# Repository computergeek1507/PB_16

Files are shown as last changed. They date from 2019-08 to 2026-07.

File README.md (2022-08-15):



# Copyright and Disclaimer
Copyright: Scott Hanson

This documentation describes Open Hardware and is licensed under the CERN Open Hardware License Version 2 - Strongly Reciprocal. (CERN-OHL-S)

You may redistribute and modify this documentation under the terms of the CERN OHL-S-v2 (https://ohwr.org/cern_ohl_s_v2.txt). This documentation is distributed WITHOUT ANY EXPRESS OR IMPLIED WARRANTY, INCLUDING OF MERCHANTABILITY, SATISFACTORY QUALITY AND FITNESS FOR A PARTICULAR PURPOSE. Please see the CERN OHL v2-S for applicable conditions

**Under CERN OHL-S-v2, derivative work must be publicly released as defined in subsection 3.3**

# BBB/PB 'Family' of Controllers

The PB16/BBB16 Pixel Controllers are designed as open source DIY hobbyist controllers. 
They all run FPP to drives the ports and serial ports. 
They are designed to be modular and support many use cases. It runs a full Linux operating system with ethernet, WIFI and audio supported over the USB port. It can run in standalone, or be used with other controllers/devices. All the design files are open source and available on github. Open source applications were used to create the controllers. [KiCad](http://kicad.org/) was used for the PCB design, and [LibreOffice](https://www.libreoffice.org/) for the documentation.

# [PB 16v1](PB_16v1/README.md)
The "Original" Pocketbeagle Version with 16 pixel ports, 2 serial ports and an expansion header for additional 16 pixel outputs.
The design was made with all through hole components for easy assembly by most users.

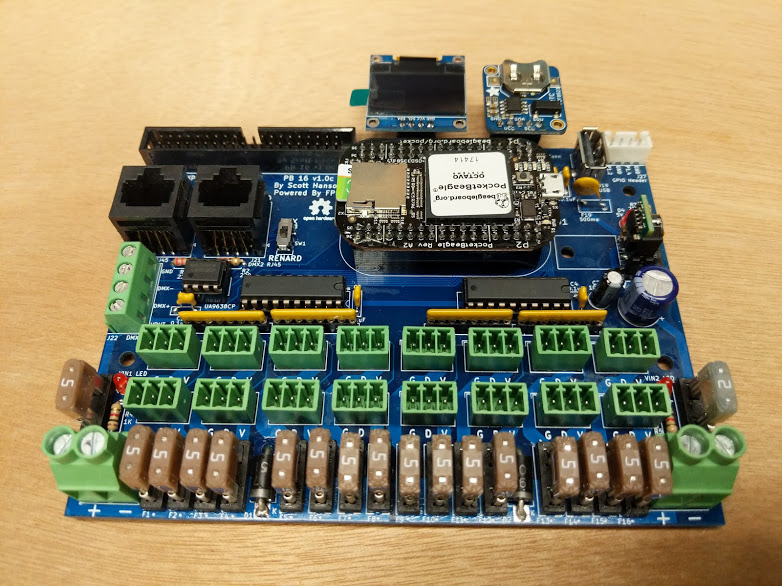
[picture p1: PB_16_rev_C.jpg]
Image of Rev C Controller


# [PB 16v2](PB_16v2_SMD/README.md)
The PB 16v2 is a Surface Mount(SMD) Pocketbeagle Version with 16 pixel ports, 1 remote differential port, 2 serial ports, and an expansion header for additional 16 pixel outputs. The v2 has an improved reverse protect circuit and USB power supply circuit.
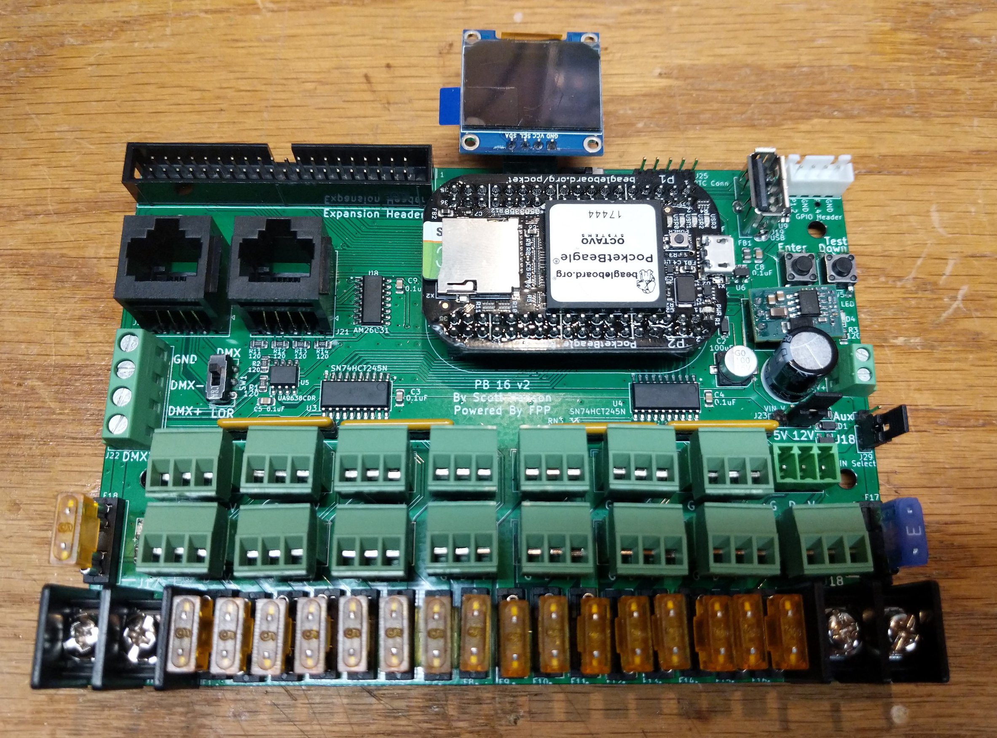
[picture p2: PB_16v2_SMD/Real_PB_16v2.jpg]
Image of PB 16v2


# [BBB 16v2](BBB_16/README.md)
The BBB 16v2 is a BeagleBone Version with 16 pixel ports, 1 remote differential port, 2 serial ports, and an expansion header for additional 16 pixel outputs. Uses Falcon v4 (24 pin) Expansion Pinout.
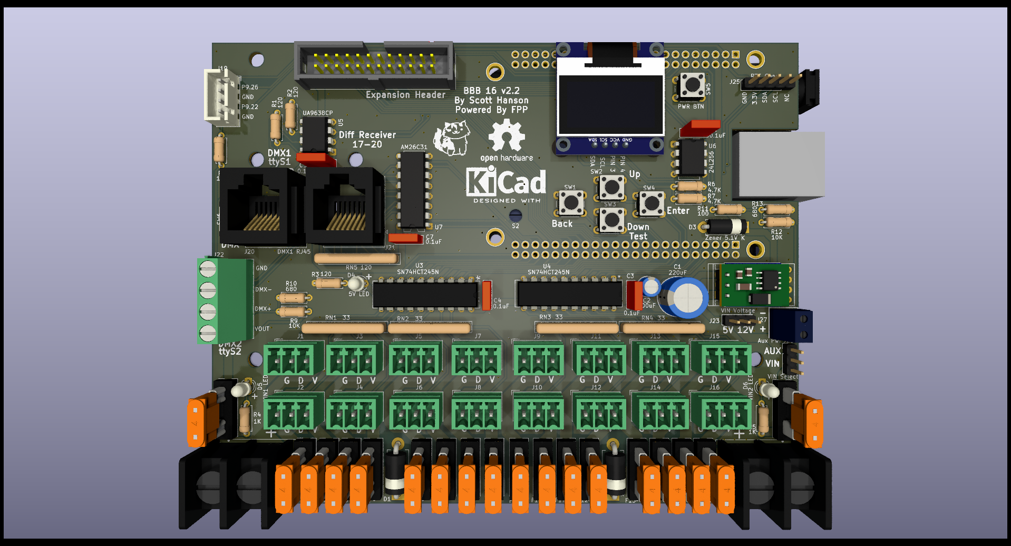
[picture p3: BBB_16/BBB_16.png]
Image of BBB 16v2


# [BBB 16v2 SMD](BBB_16_SMD/README.md) 
The BBB 16v2 SMD is a Surface Mount(SMD) BeagleBone Version with 16 pixel ports, 1 remote differential port, 2 serial ports, and an expansion header for additional 16 pixel outputs. Uses Falcon v4 (24 pin) Expansion Pinout.
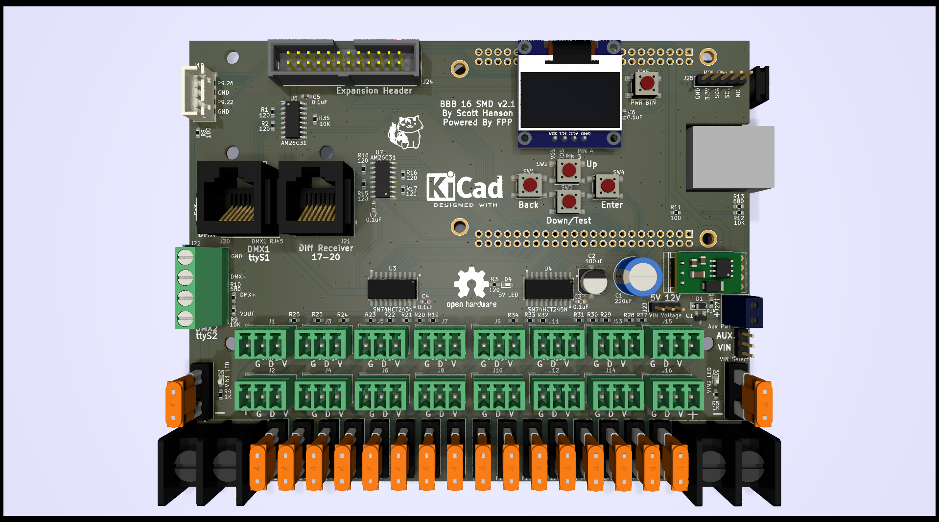
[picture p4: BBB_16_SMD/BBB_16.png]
Image of BBB 16v2 SMD


### Common Features of the PB 16v1, PB 16v2, & BBB 16v2
* Powered by FPP Falcon Player
* Standalone/Master/Remote/Bridge Support
* 16 3-Wire Pixel Ports
* 700 pixel per output at 40 FPS or 1300 at 20 FPS
* 2 DMX Serial Outputs
* Fused Powered DMX Output
* USB port for Ethernet,WIFI, or Audio
* OLED Display header
* Adafruit Real Time Clock Header Connector
* 2 pin GPIO Header for Push Button or Relay Support
* 5v - 24v Vin Support
* Expansion Header for additional 16 pixel outputs, Supports Falcon v3 (40 pin) Expansion Boards.

### Features of the PB 16v1
* Through Hole Assemply
* 1 RJ-45 Connector with DMX/Renard Wiring Support.
* 1 RJ-45 Connector with DMX/LOR Wiring Support.
* Only Supports DMX Protocol over Serial Ports.

### Features of the PB 16v2 & BBB 16v2
* 1 RJ-45 Connector for a remote differential port.
* 1 RJ-45 Connector with DMX/LOR Wiring Support.
* Supports DMX/Renard/Lor Protocol over Serial Ports.

## [Ordering Instructions](https://github.com/computergeek1507/PB_16/blob/master/JLC_PCB.md)
## [Flashing EEPROM Instructions](https://github.com/computergeek1507/PB_16/blob/master/Flashing_EEPROM.md)

## Variants
I created different variants of the PB 16, to fit my specific needs.
* [**PB 16v1**](PB_16v1/README.md) - Original Pocketbeagle Version with 16 pixel ports, 2 serial ports and an expansion header(40 pins) for additional 16 pixel outputs.
* [**PB 16v2**](PB_16v2_SMD/README.md) - **Surface Mount(SMD)** Pocketbeagle Version with 16 pixel ports, 1 remote differential port, 2 serial ports, and an expansion header(40 pins) for additional 16 pixel outputs.
* [**BBB 16v2**](BBB_16/README.md) - Beaglebone Version with 16 pixel ports, 1 remote differential port, 2 serial ports and an expansion header for additional 16 pixel outputs. Uses Falcon v4 Expansion Pinout(24 pins).
* [**BBB 16v2 SMD**](BBB_16_SMD/README.md) - **Surface Mount(SMD)** Beaglebone Version with 16 pixel ports, 1 remote differential port, 2 serial ports and an expansion header for additional 16 pixel outputs. Uses Falcon v4 Expansion Pinout(24 pins).
* [**BBB 16 Flex**](BBB_16_Flex/README.md) - BBB 16 PCB to use with the HolidayCoro Flex System. This is a **Surface Mount(SMD)** Design.
* [**BBB 16 Expansion**](BBB_16_Expansion/README.md) - BBB 16v2 PCB with Three Expansion Board Ports for 48 outputs. Uses Falcon v4 Expansion Pinout. This is a **Surface Mount(SMD)** Design.
* [**PB 16 Expansion**](PB_16_Expansion/README.md) - Small Form Factor PB 16 with Two Expansion Board Ports(40 pins) for 32 outputs.
* [**PB 16 Mini**](PB_16_Mini/README.md) - Small Form Factor PB 16 with one Expansion Board Port(40 pins) for 16 ouputs and two Serial Outputs.
* [**PB 16 Flex**](PB_16_Flex/README.md) - PB 16 PCB to use with the HolidayCoro Flex System.
<!--- * [**PB 16 E682**](PB_16_E682/README.md) - Adapter PCB to use a Pocketbeagle with a Sandevice E682. (This is a proof of concept, not designed for extended use)-->
* [**PB 16 E682 Serial**](PB_16_E682_Serial/README.md) - Serial Output PCB to for PB 16 E682 or PB 16 Expansion.

## Addon Boards

The PB16 Controller contains an expansion header. The expansion header can drive 16 additional pixel ports. I have also created addition addon boards to work with the expansion port. These Expansions will work with Kulp Controllers, but **not** Falcon Controllers.

* [**16 Expansion**](16_Expansion/README.md) - 16 Port Local Expansion. Supports PB 16 (40 pins) Connectors.
* [**16 Expansion 24pin**](16_Expansion_24pin/README.md) - 16 Port Local Expansion. Supports BBB 16v2 (24 pins) Connectors.
* [**16 Expansion SMD**](16_Expansion_SMD/README.md) - 16 Port Local Expansion. Supports PB 16 (40 pins) Connectors. This is a **Surface Mount(SMD)** Design.
* [**16 Expansion SMD 24pin**](16_Expansion_SMD_24pin/README.md) - 16 Port Local Expansion. Supports BBB 16v2 (24 pins) Connectors. This is a **Surface Mount(SMD)** Design.
* [**Diff Expansion**](Diff_Expansion/README.md) - 4 Port Remote Differential Expansion. Supports PB 16 (40 pins) & BBB 16 (24 pins) Connectors.
* [**Multi Expansion**](Multi_Expansion/README.md) - 8 Port Local & 2 Port Remote Differential Expansion. **Only Supports PB 16 (40 pins) Connectors.**
* [**Quad Diff Out**](Quad_Diff_Out/README.md) - 1 Port Remote Differential Expansion.
* [**Four Out**](Four_Out/README.md) - 4 Port Local Expansion. Supports PB 16 (40 pins) & BBB 16 (24 pins) Connectors.
* [**Receiver Out**](Receiver_Out/README.md) - 4 Port Remote Receiver Board for use with Remote Differential Expansions.
* [**Receiver Out SMD**](Receiver_Out_SMD/README.md) - 4 Port Remote Receiver Board for use with Remote Differential Expansions. This is a **Surface Mount(SMD)** Design.

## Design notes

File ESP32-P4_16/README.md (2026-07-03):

# Copyright and Disclaimer
Copyright: Scott Hanson

This documentation describes Open Hardware and is licensed under the CERN Open Hardware License Version 2 - Strongly Reciprocal. (CERN-OHL-S)

You may redistribute and modify this documentation under the terms of the CERN OHL-S-v2 (https://ohwr.org/cern_ohl_s_v2.txt). This documentation is distributed WITHOUT ANY EXPRESS OR IMPLIED WARRANTY, INCLUDING OF MERCHANTABILITY, SATISFACTORY QUALITY AND FITNESS FOR A PARTICULAR PURPOSE. Please see the CERN OHL v2-S for applicable conditions

**Under CERN OHL-S-v2, derivative work must be publicly released as defined in subsection 3.3**

# ESP32-P4 16

**WIP, Do not use**

The ESP32-P4 16 is a ESP32-P4 based 16 port controller. All the design files are open source and available on github.

## [Interactive BOM](https://computergeek1507.github.io/PB_16/ESP32-P4_16/bom/ibom)

## [Part BOM](https://github.com/computergeek1507/PB_16/raw/master/ESP32-P4_16/ESP32-P4_16_BOM.ods)

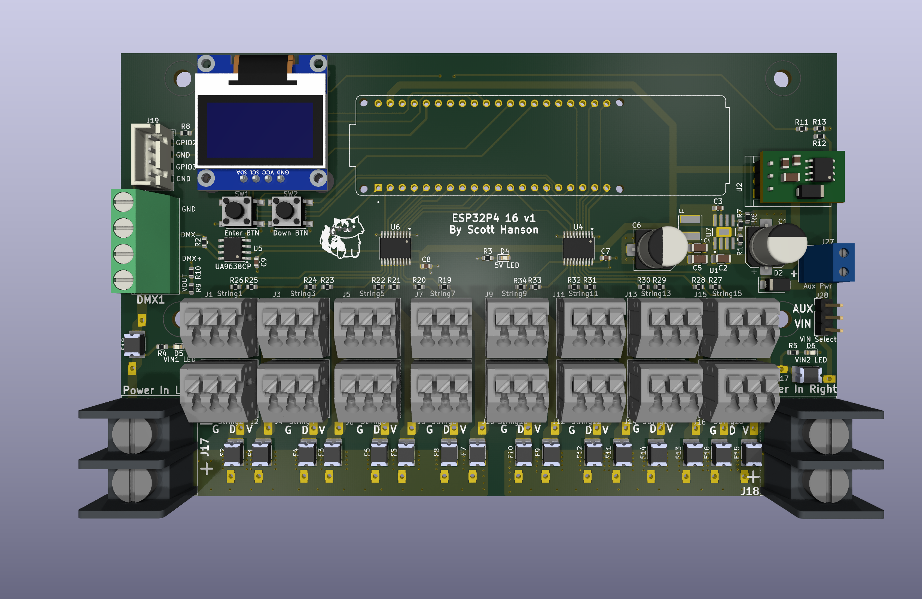
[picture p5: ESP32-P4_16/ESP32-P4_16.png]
Image of ESP32-P4 16 Out


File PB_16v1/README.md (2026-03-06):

# Copyright and Disclaimer
Copyright: Scott Hanson

This documentation describes Open Hardware and is licensed under the CERN Open Hardware License Version 2 - Strongly Reciprocal. (CERN-OHL-S)

You may redistribute and modify this documentation under the terms of the CERN OHL-S-v2 (https://ohwr.org/cern_ohl_s_v2.txt). This documentation is distributed WITHOUT ANY EXPRESS OR IMPLIED WARRANTY, INCLUDING OF MERCHANTABILITY, SATISFACTORY QUALITY AND FITNESS FOR A PARTICULAR PURPOSE. Please see the CERN OHL v2-S for applicable conditions

**Under CERN OHL-S-v2, derivative work must be publicly released as defined in subsection 3.3**

# PB 16

Image of Rev C Controller

The PB16 Pixel Controller is designed as an open source DIY hobbyist controller. A Pocketbeagle running FPP drives the 16 pixel ports and 2 serial ports. The design was made with all through hole components for easy assembly by most users. It is designed to be modular and support many use cases. It runs a full Linux operating system with ethernet, WIFI and audio supported over the USB port. It can run in standalone, or be used with other controllers/devices. It is 140mm (5’) wide by 103mm(4’) tall. The controllers small form factor and simplistic design are intended to limit overall cost. All the design files are open source and available on github. Open source applications were used to create this controller. [KiCad](http://kicad.org/) was used for the PCB design, and [LibreOffice](https://www.libreoffice.org/) for the documentation.

To order your own PCB upload the gerber.zip file to your favorite PCB manufacture of choice, I personally use [jlcpcb.com](https://jlcpcb.com/).

Assembly Instructions are included in the manual below.

### Features
* Powered by FPP Falcon Player
* Standalone/Master/Remote/Bridge Support
* 16 3-Wire Pixel Ports
* 700 pixel per output at 40 FPS or 1300 at 20 FPS
* 2 DMX Serial Outputs
* 2 RJ-45 Connectors with DMX/LOR/Renard Wiring Support
* Fused Powered DMX Output
* USB port for Ethernet,WIFI, or Audio
* OLED Display header
* Adafruit Real Time Clock Header Connector
* 2 pin GPIO Header for Push Button or Relay Support
* 5v - 24v Vin Support
* Expansion Header for additional 16 pixel outputs, Supports Falcon(v3) Expansion Boards

## [Manual](https://github.com/computergeek1507/PB_16/raw/master/PB_16v1/FPP%20PB16%20Pixel%20Controller%20Manual%20and%20Assembly%20Guide.pdf)

## [Gerbers](https://github.com/computergeek1507/PB_16/raw/master/PB_16v1/gerbers/gerbers.zip)

## [Part BOM](https://github.com/computergeek1507/PB_16/raw/master/PB_16v1/PB16_Bom.ods)

## [Interactive BOM](https://computergeek1507.github.io/PB_16/PB_16v1/bom/ibom)

## [Ordering Instructions](https://github.com/computergeek1507/PB_16/blob/master/JLC_PCB.md)

---
## Changelog

v1 rev I 
- 
* 2026-03-06
* Switched Expansion Header to 24pin Falcon V4 pinout.
* Removed OLED Slide Switch.

v1 rev H 
- 
* 2022-05-29
* Updated 5V regulator to "Universal" footprint to support different regulators.
* Added Chewi Logo.

v1 rev G 
-
* 2020-05-09
* Moved to barrier block screws connectors for Power Inputs.
* Fix AUX power pin holes too small.

v1 rev F
-
* 2019-10-07
* Added Serial Selector for LOR/DMX, EEPROM, Push Buttons.

v1 rev E
-
* 2019-09-19
* Increased AUX power input terminal footprint to 3.81mm. (Pin Holes were too small)

v1 rev D
-
* 2019-08-24
* Added OLED wiring selector switch and AUX power input.

v1 rev C
-
* 2019-08-12
* Added LEDs and GPIO Header. (First functional PCBs)

v1 rev B(v1.1)
-
* 2019-07-31
* Added Expansion, DMX2 RJ45, and OLED Headers. (non-functioning due to wiring issues)

v1 rev A(v1.0)
-
* 2019-06-19(SEH B-Day)
* Initial Version. (First non-functioning Prototype PCBs)

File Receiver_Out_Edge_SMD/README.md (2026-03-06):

# Copyright and Disclaimer
Copyright: Scott Hanson

This documentation describes Open Hardware and is licensed under the CERN Open Hardware License Version 2 - Strongly Reciprocal. (CERN-OHL-S)

You may redistribute and modify this documentation under the terms of the CERN OHL-S-v2 (https://ohwr.org/cern_ohl_s_v2.txt). This documentation is distributed WITHOUT ANY EXPRESS OR IMPLIED WARRANTY, INCLUDING OF MERCHANTABILITY, SATISFACTORY QUALITY AND FITNESS FOR A PARTICULAR PURPOSE. Please see the CERN OHL v2-S for applicable conditions

**Under CERN OHL-S-v2, derivative work must be publicly released as defined in subsection 3.3**

# Receiver Out Edge SMD

The "Receiver Out Edge SMD" is a 4 port Differental Reciver output board for the PB16. This design is surface mount based. All the design files are open source and available on github.

### Version 3
Version 3 (2025-2-23) adds an Attiny1616 Micro controller and Test Button to enable local testing. This is be programmed with the included Ardunio INO file or hex file. Requires a UPDI programmer. This can be bypassed by populateding R12 with 10K.

### Ordering
To order PCBs upload the "GERBER-Receiver_Out.zip" file in the "jlcpcb\production_files" folder. Enable the SMD service, 'BOM-Receiver_Out.csv' is the SMD BOM and 'POS-Receiver_Out.csv' is the SMD CPL position file.

## [Part BOM](https://github.com/computergeek1507/PB_16/raw/master/Receiver_Out_Edge_SMD/Receiver_Out.csv)

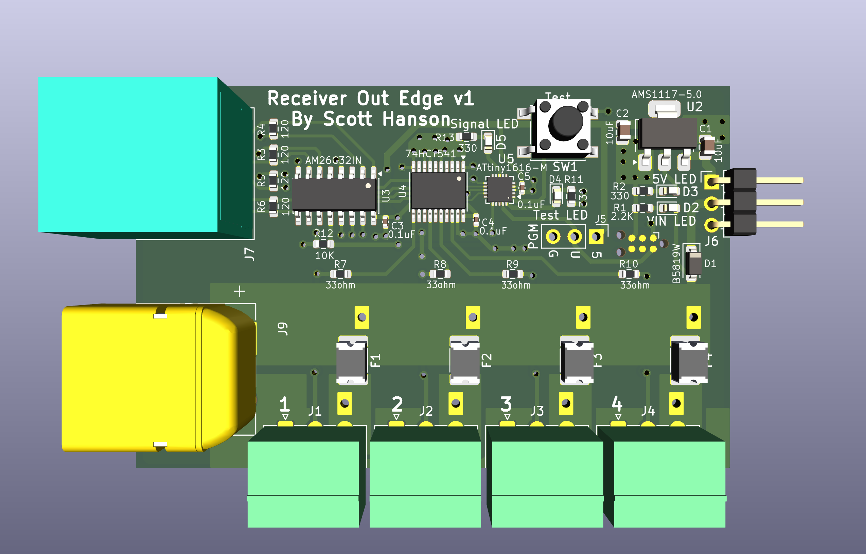
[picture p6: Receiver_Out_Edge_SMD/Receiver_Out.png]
Image of Receiver Out


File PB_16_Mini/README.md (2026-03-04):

# Copyright and Disclaimer
Copyright: Scott Hanson

This documentation describes Open Hardware and is licensed under the CERN Open Hardware License Version 2 - Strongly Reciprocal. (CERN-OHL-S)

You may redistribute and modify this documentation under the terms of the CERN OHL-S-v2 (https://ohwr.org/cern_ohl_s_v2.txt). This documentation is distributed WITHOUT ANY EXPRESS OR IMPLIED WARRANTY, INCLUDING OF MERCHANTABILITY, SATISFACTORY QUALITY AND FITNESS FOR A PARTICULAR PURPOSE. Please see the CERN OHL v2-S for applicable conditions

**Under CERN OHL-S-v2, derivative work must be publicly released as defined in subsection 3.3**

# PB 16 Mini

The PB16 Mini is a compact version of the PB16 with only an Expansions Header. It can be used with any PB16 Family Expansion or Falcon Expansion Boards. All the design files are open source and available on github.

## [Part BOM](https://github.com/computergeek1507/PB_16/raw/master/PB_16_Mini/PB_16_Mini.ods)

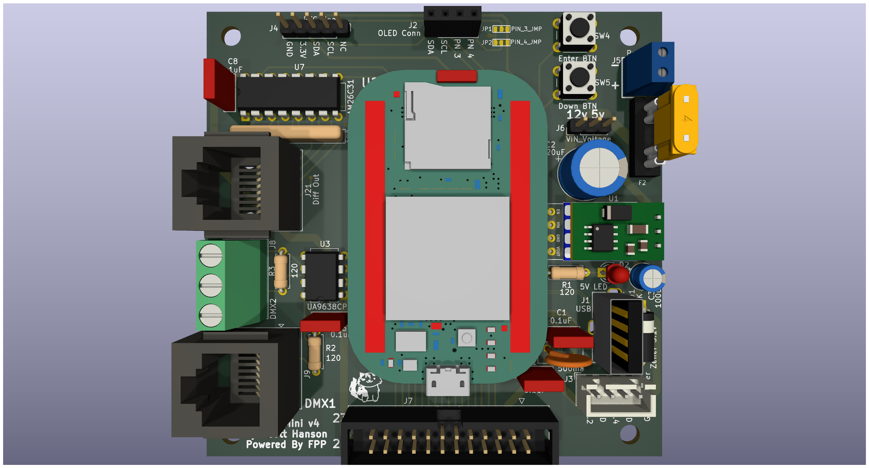
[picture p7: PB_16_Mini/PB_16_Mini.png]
Image of PB16 Mini Out


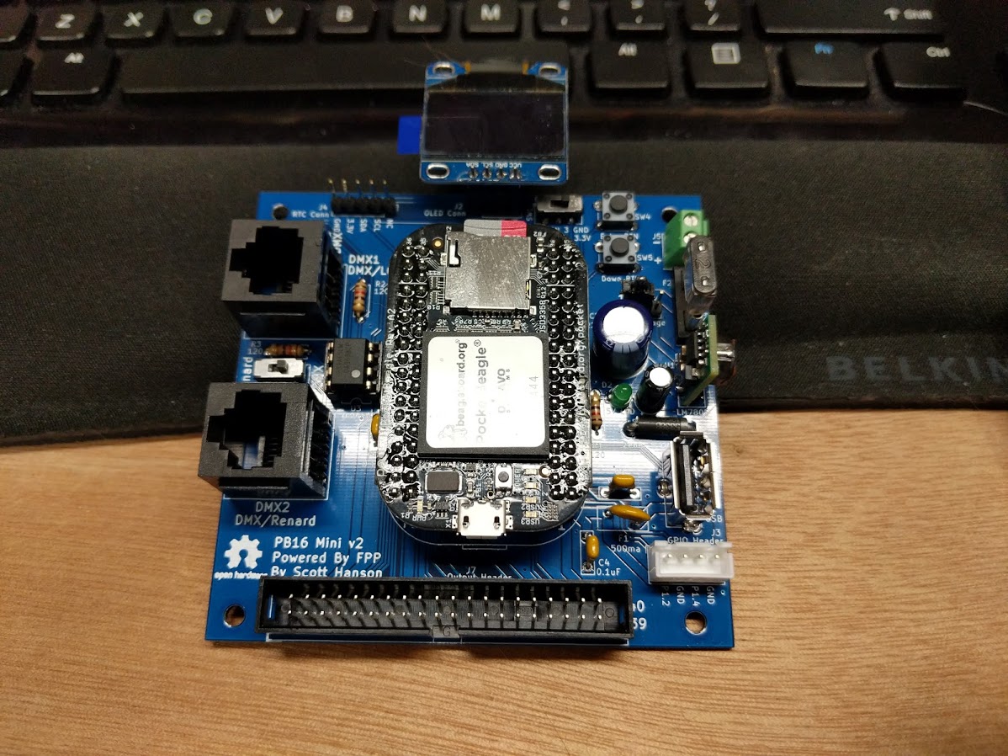
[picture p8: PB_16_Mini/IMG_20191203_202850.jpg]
Real Image of PB16 Mini Out


----
## Changelog

v4
----
* 2026-03-04
* Add Different Output
* Switched Expansion Header to 24pin Falcon V4 pinout.
* Switched to PB16v2 pinout, use PB16v2 EEPROM

v3
----
* 2022-08-13
* Updated 5V regulator to "Universal" footprint to support different regulators.
* Added Logo

v2
----
* 2019-12-03
* Add Serial Outputs.

v1
----
* 2019-??-??
* First Internal Version with only Expansion Port.

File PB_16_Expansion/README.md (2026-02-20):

# Copyright and Disclaimer
Copyright: Scott Hanson

This documentation describes Open Hardware and is licensed under the CERN Open Hardware License Version 2 - Strongly Reciprocal. (CERN-OHL-S)

You may redistribute and modify this documentation under the terms of the CERN OHL-S-v2 (https://ohwr.org/cern_ohl_s_v2.txt). This documentation is distributed WITHOUT ANY EXPRESS OR IMPLIED WARRANTY, INCLUDING OF MERCHANTABILITY, SATISFACTORY QUALITY AND FITNESS FOR A PARTICULAR PURPOSE. Please see the CERN OHL v2-S for applicable conditions

**Under CERN OHL-S-v2, derivative work must be publicly released as defined in subsection 3.3**

# PB 16 Expansion

The PB16 Expansion is a compact version of the PB16 with only two Expansion Headers. It can be used with any PB16 Family Expansion or Falcon Expansion Boards. There is also an optional [serial breakout board](../PB_16_E682_Serial/README.md) for DMX capability. All the design files are open source and available on github.

## [Part BOM](https://github.com/computergeek1507/PB_16/raw/master/PB_16_Expansion/PB_16.csv)

## [Interactive BOM](https://computergeek1507.github.io/PB_16/PB_16_Expansion/bom/ibom)

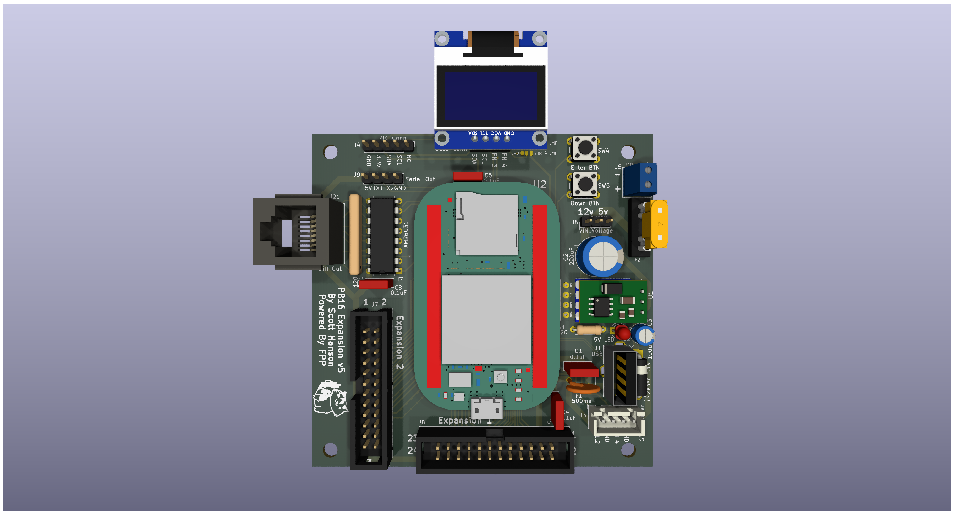
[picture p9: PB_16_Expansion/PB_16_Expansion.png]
Image of PB16 Expansion Out


----
## Changelog

v5
----
* 2026-02-20
* Add Different Output
* Switched Expansion Header to 24pin Falcon V4 pinout.
* Switched to PB16v2 pinout, use PB16v2 EEPROM

v4
----
* 2022-08-13
* Updated 5V regulator to "Universal" footprint to support different regulators.
* Added Logo

v3
----
* 2020-05-06
* Wiring Routing Updates.

v2
----
* 2020-01-02
* Add Serial Output Header.

v1
----
* 2019-12-31
* First Version.

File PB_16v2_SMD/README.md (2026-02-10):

# Copyright and Disclaimer
Copyright: Scott Hanson

This documentation describes Open Hardware and is licensed under the CERN Open Hardware License Version 2 - Strongly Reciprocal. (CERN-OHL-S)

You may redistribute and modify this documentation under the terms of the CERN OHL-S-v2 (https://ohwr.org/cern_ohl_s_v2.txt). This documentation is distributed WITHOUT ANY EXPRESS OR IMPLIED WARRANTY, INCLUDING OF MERCHANTABILITY, SATISFACTORY QUALITY AND FITNESS FOR A PARTICULAR PURPOSE. Please see the CERN OHL v2-S for applicable conditions

**Under CERN OHL-S-v2, derivative work must be publicly released as defined in subsection 3.3**

# PB 16v2

The PB 16v2 is a surface mount(SMD) version of the original PB16. The updated PB 16v2 has 16 local pixel ports, one remote receiver port(4 remote ports), a 16 port expansion, and 2 serial ports. A total of 36 pixel outputs. All the design files are open source and available on github.

### Features
* Powered by FPP Falcon Player
* Standalone/Master/Remote/Bridge Support
* 16 3-Wire Pixel Ports
* 1 RJ-45 Connector for a remote differential port.
* 700 pixel per output at 40 FPS or 1300 at 20 FPS
* 2 DMX Serial Outputs
* 1 RJ-45 Connectors with DMX/LOR Wiring Support
* Fused Powered DMX Output
* USB port for Ethernet,WIFI, or Audio
* OLED Display header
* Adafruit Real Time Clock Header Connector
* 2 pin GPIO Header for Push Button or Relay Support
* 5v - 24v Vin Support
* Expansion Header for additional 16 pixel outputs, Supports Falcon(v3) Expansion Boards

### Purchase
I (Scott) have a limited quantity of fully assembled PCB's available for purchase. PM me if interested.

## [Part BOM](https://github.com/computergeek1507/PB_16/raw/master/PB_16v2_SMD/PB_16_BOM.ods)

## [Interactive BOM](https://computergeek1507.github.io/PB_16/PB_16v2_SMD/bom/ibom)

Image of PB 16v2

----
## Changelog

v2.3
----
* 2026-02-09
* Switched to TSSOP-20 for U4 & U5.
* Switched Pixel Outputs to Dual 3.5mm/3.81mm Pads.
* Switched Expansion Header to 24pin Falcon V4 pinout.
* Removed OLED Slide Switch.
* Removed Top Solder pour.

v2.2
----
* 2022-06-05
* Updated 5V regulator to "Universal" footprint to support different regulators.
* Switched to 603 Resistors and Capacitors
* Added Logo

v2.1
----
* 2022-05-26
* Switched to surface mount 33ohm resistors on pixel outputs.

v2
----
* 2020-08-11 (publicly released 2022-01-22)
* First SMD version.
* Based off PB16v1.
* Used 805 Resistors and Capacitors
* Changed one RJ45 port to new differential output.
* Added Power Controller to USB port.
* Added TVS Diodes to USB port.

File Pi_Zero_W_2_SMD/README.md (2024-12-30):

# Copyright and Disclaimer
Copyright: Scott Hanson

This documentation describes Open Hardware and is licensed under the CERN Open Hardware Licence Version 2 - Strongly Reciprocal. (CERN-OHL-S)

You may redistribute and modify this documentation under the terms of the CERN OHL-S-v2 (https://ohwr.org/cern_ohl_s_v2.txt). This documentation is distributed WITHOUT ANY EXPRESS OR IMPLIED WARRANTY, INCLUDING OF MERCHANTABILITY, SATISFACTORY QUALITY AND FITNESS FOR A PARTICULAR PURPOSE. Please see the CERN OHL v2-S for applicable conditions

**Under CERN OHL-S-v2, derivative work must be publicy released as defined in subsection 3.3**

# Pi Zero W 2

**Never Built or tested**

The Pi Zero W 2 is a surface mount(SMD) controller with 2 local pixel ports. All the design files are open source and available on github.

## [Interactive BOM](https://computergeek1507.github.io/PB_16/Pi_Zero_W_2_SMD/bom/ibom)

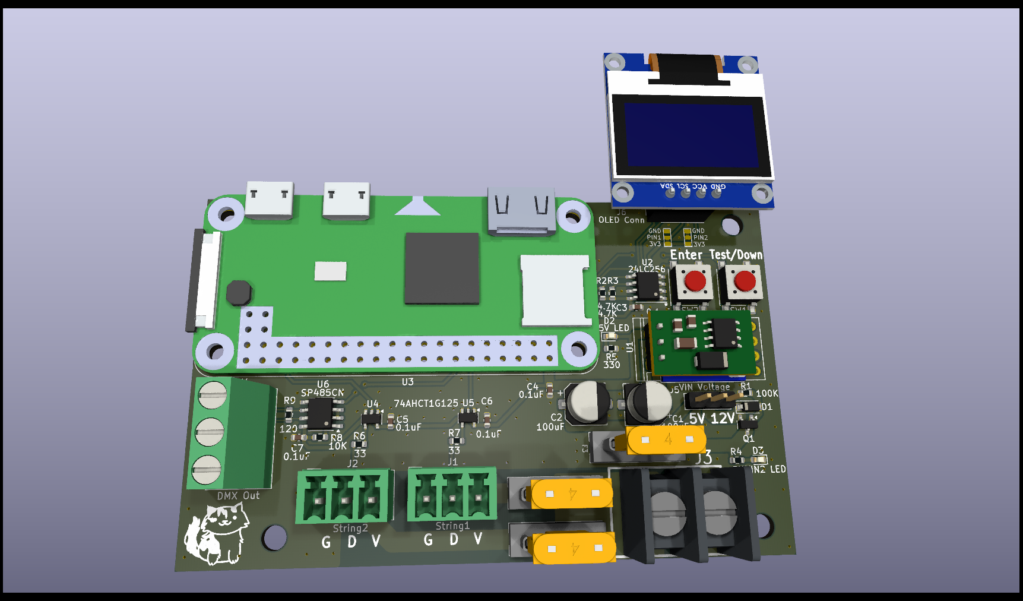
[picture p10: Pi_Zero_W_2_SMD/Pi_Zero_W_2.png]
Image of PB Pi Zero W 16


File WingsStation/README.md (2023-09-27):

# Copyright and Disclaimer
Copyright: Scott Hanson

This documentation describes Open Hardware and is licensed under the CERN Open Hardware License Version 2 - Strongly Reciprocal. (CERN-OHL-S)

You may redistribute and modify this documentation under the terms of the CERN OHL-S-v2 (https://ohwr.org/cern_ohl_s_v2.txt). This documentation is distributed WITHOUT ANY EXPRESS OR IMPLIED WARRANTY, INCLUDING OF MERCHANTABILITY, SATISFACTORY QUALITY AND FITNESS FOR A PARTICULAR PURPOSE. Please see the CERN OHL v2-S for applicable conditions

**Under CERN OHL-S-v2, derivative work must be publicly released as defined in subsection 3.3**

# Button Station SMD

The "Button Station SMD" is a 4 port Selfy Station that reacts to Button Presses. The Firmware is a work in progress. This design is surface mount based and is harder to solder. All the design files are open source and available on github.

**WIP** Work in progress, firmware and PCB may change.

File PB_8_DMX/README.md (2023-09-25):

# Copyright and Disclaimer
Copyright: Scott Hanson

This documentation describes Open Hardware and is licensed under the CERN Open Hardware License Version 2 - Strongly Reciprocal. (CERN-OHL-S)

You may redistribute and modify this documentation under the terms of the CERN OHL-S-v2 (https://ohwr.org/cern_ohl_s_v2.txt). This documentation is distributed WITHOUT ANY EXPRESS OR IMPLIED WARRANTY, INCLUDING OF MERCHANTABILITY, SATISFACTORY QUALITY AND FITNESS FOR A PARTICULAR PURPOSE. Please see the CERN OHL v2-S for applicable conditions

**Under CERN OHL-S-v2, derivative work must be publicly released as defined in subsection 3.3**

# PB 8 DMX

The PB 8 DMX Controller is designed as an open source DIY hobbyist controller. A Pocketbeagle running FPP drives the 8 serial ports. The design was made with all through hole components for easy assembly by most users. It is designed to be modular and support many use cases. It runs a full Linux operating system with ethernet, WIFI and audio supported over the USB port. It can run in standalone, or be used with other controllers/devices. It is 140mm (5’) wide by 103mm(4’) tall. The controllers small form factor and simplistic design are intended to limit overall cost. All the design files are open source and available on github. Open source applications were used to create this controller. [KiCad](http://kicad.org/) was used for the PCB design, and [LibreOffice](https://www.libreoffice.org/) for the documentation.

To order your own PCB upload the gerber.zip file to your favorite PCB manufacture of choice, I personally use [jlcpcb.com](https://jlcpcb.com/).

### Features
* Powered by FPP Falcon Player
* Standalone/Master/Remote/Bridge Support
* 8 DMX Serial Outputs
* USB port for Ethernet,WIFI, or Audio
* OLED Display header
* Adafruit Real Time Clock Header Connector
* 2 pin GPIO Header for Push Button or Relay Support
* 5v - 24v Vin Support

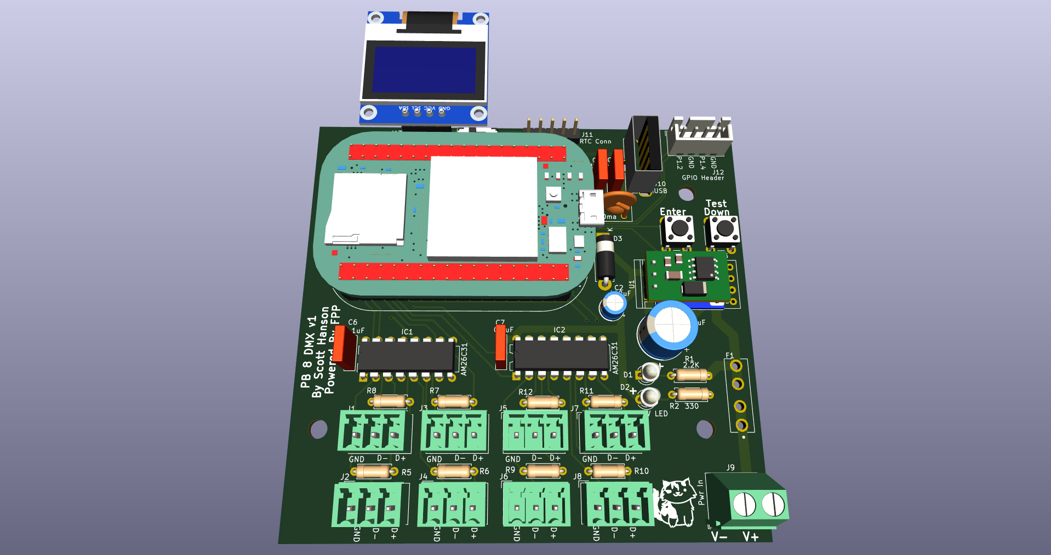
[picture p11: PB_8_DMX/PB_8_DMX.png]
Image of Controller


## [Gerbers](https://github.com/computergeek1507/PB_16/raw/master/jlcpcb/production_files/GERBER-PB_8_DMX.zip)

## [Interactive BOM](https://computergeek1507.github.io/PB_16/PB_8_DMX/bom/ibom)

---
## Changelog

v1
-
* 2023-09-24
* Initial Version.

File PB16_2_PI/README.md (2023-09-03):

# Copyright and Disclaimer
Copyright: Scott Hanson

This documentation describes Open Hardware and is licensed under the CERN OHL v. 1.2.

You may redistribute and modify this documentation under the terms of the CERN OHL v.1.2. (http://ohwr.org/cernohl). This documentation is distributed WITHOUT ANY EXPRESS OR IMPLIED WARRANTY, INCLUDING OF MERCHANTABILITY, SATISFACTORY QUALITY AND FITNESS FOR A PARTICULAR PURPOSE. Please see the CERN OHL v.1.2 for applicable conditions

# PB16-2-PI

This is an adapter to use a Raspberry Pi W with the PB16 Cape instead of a PocketBeagle. This only supports the 16 local ports and the serial ports. The Expansion header does not work. Open source applications were used to create this PCB. [KiCad](http://kicad.org/) was used for the PCB design, and [LibreOffice](https://www.libreoffice.org/) for the documentation.

To order your own PCB upload the gerber.zip file to your favorite PCB manufacture of choice, I personally use [jlcpcb.com](https://jlcpcb.com/).

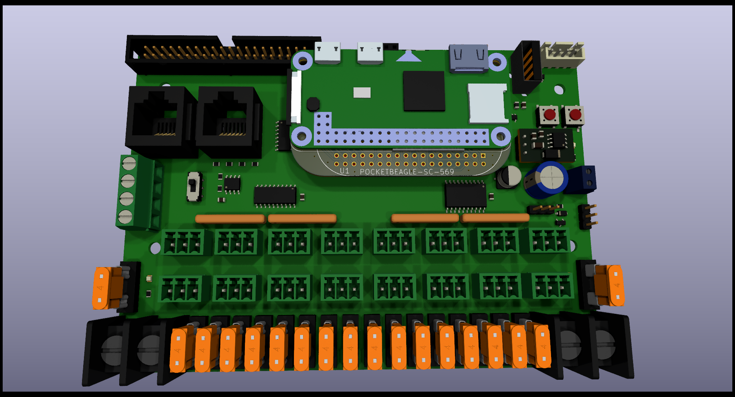
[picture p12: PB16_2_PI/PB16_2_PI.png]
Image of PI Adapter


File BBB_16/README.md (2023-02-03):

# Copyright and Disclaimer
Copyright: Scott Hanson

This documentation describes Open Hardware and is licensed under the CERN Open Hardware License Version 2 - Strongly Reciprocal. (CERN-OHL-S)

You may redistribute and modify this documentation under the terms of the CERN OHL-S-v2 (https://ohwr.org/cern_ohl_s_v2.txt). This documentation is distributed WITHOUT ANY EXPRESS OR IMPLIED WARRANTY, INCLUDING OF MERCHANTABILITY, SATISFACTORY QUALITY AND FITNESS FOR A PARTICULAR PURPOSE. Please see the CERN OHL v2-S for applicable conditions

**Under CERN OHL-S-v2, derivative work must be publicly released as defined in subsection 3.3**

# BBB 16

The BBB16 is a Beaglebone version of the PB16. All the design files are open source and available on github.

To order PCBs upload the ["GERBER-BBB_16.zip"](https://github.com/computergeek1507/PB_16/raw/master/BBB_16/jlcpcb/production_files/GERBER-BBB_16.zip) file in the "jlcpcb\production_files" folder to jlcpcb.com.

## [Part BOM](https://github.com/computergeek1507/PB_16/raw/master/BBB_16/BBB_16_BOM.ods)

## [Interactive BOM](https://computergeek1507.github.io/PB_16/BBB_16/bom/ibom)

Image of BBB16 Out

---
## Changelog

v2.3
-
* Added cutable traces to OLED power pins that defaults to the common pinout.

v2.2
-
* Updated 5V regulator to "Universal" footprint to support different regulators.

v2.1
-
* Added power input ADC circuits.

v2
-
* Moved Beaglebone to bottom of PCB.
* Changed one RJ45 port to differential output.
* Added Aux Power port.
* Changed to 24pin Expansion port.
* Changed power terminals to screw terminals.
* Removed Audio Breakout Header.

v1.4
-
* Fix EEPROM I2C.

v1.3
-
* Fix Buttons and GPIO.

v1.2
-
* Added Audio Breakout Header.
* Switch to 33ohm resistors for pixel outputs.

v1
-
* First version.
* BBB on top
* OLED.
* Buttons.
* GPIO port.
* Side Entry power ports.

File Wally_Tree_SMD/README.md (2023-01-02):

# Copyright and Disclaimer
Copyright: Scott Hanson

This documentation describes Open Hardware and is licensed under the CERN Open Hardware License Version 2 - Strongly Reciprocal. (CERN-OHL-S)

You may redistribute and modify this documentation under the terms of the CERN OHL-S-v2 (https://ohwr.org/cern_ohl_s_v2.txt). This documentation is distributed WITHOUT ANY EXPRESS OR IMPLIED WARRANTY, INCLUDING OF MERCHANTABILITY, SATISFACTORY QUALITY AND FITNESS FOR A PARTICULAR PURPOSE. Please see the CERN OHL v2-S for applicable conditions

**Under CERN OHL-S-v2, derivative work must be publicly released as defined in subsection 3.3**

# Wally Tree Driver

The "Wally Tree Driver" is a Differental Reciver board designed to control at 5" Holiday Time RGB Tree from Walmart[Link](https://www.walmart.com/ip/Holiday-Time-5-Rgb-Color-Changing-Pixel-Tree/908536686). All the design files are open source and available on github.

To order PCBs upload the "GERBER-Wally_Tree.zip" file in the "jlcpcb\gerber" folder. Enable the SMD service, 'BOM-Wally_Tree.csv' is the SMD BOM and 'POS-Wally_Tree.csv' is the SMD CPL position file.

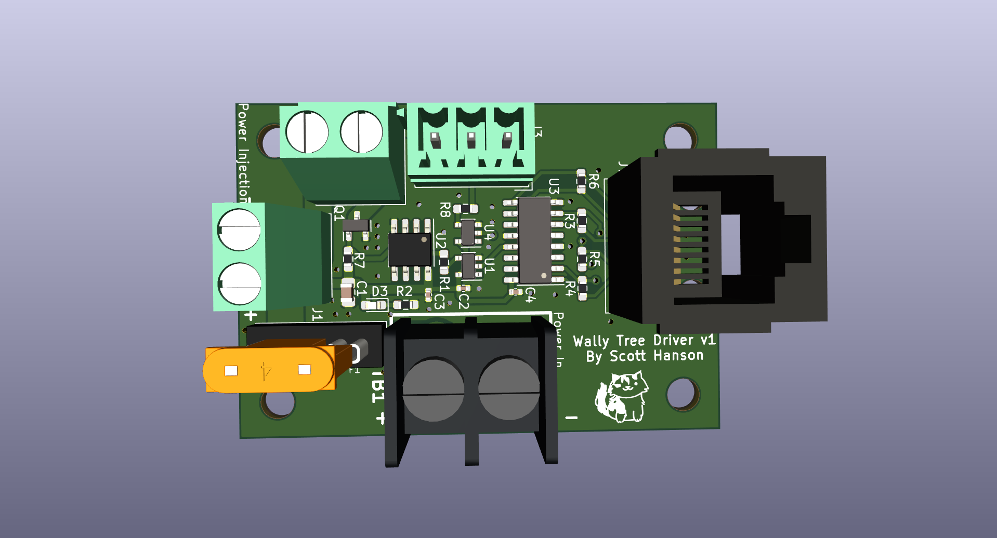
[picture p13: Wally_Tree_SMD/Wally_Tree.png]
Image of PCB


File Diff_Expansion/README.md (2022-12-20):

# Copyright and Disclaimer
Copyright: Scott Hanson

This documentation describes Open Hardware and is licensed under the CERN Open Hardware License Version 2 - Strongly Reciprocal. (CERN-OHL-S)

You may redistribute and modify this documentation under the terms of the CERN OHL-S-v2 (https://ohwr.org/cern_ohl_s_v2.txt). This documentation is distributed WITHOUT ANY EXPRESS OR IMPLIED WARRANTY, INCLUDING OF MERCHANTABILITY, SATISFACTORY QUALITY AND FITNESS FOR A PARTICULAR PURPOSE. Please see the CERN OHL v2-S for applicable conditions

**Under CERN OHL-S-v2, derivative work must be publicly released as defined in subsection 3.3**

# Diff Expansion

The Diff Expansion is a four port Differental Reciever output boardfor the PB16. It works with Smart and Dumb Differental Recievers. All the design files are open source and available on github.

To order, upload the "GERBER-Diff_Expansion.zip" file in the "jlcpcb\gerber" folder to jlcpcb.com.

## [Part BOM](https://github.com/computergeek1507/PB_16/raw/master/Diff_Expansion/Diff_Expansion_BOM.ods)

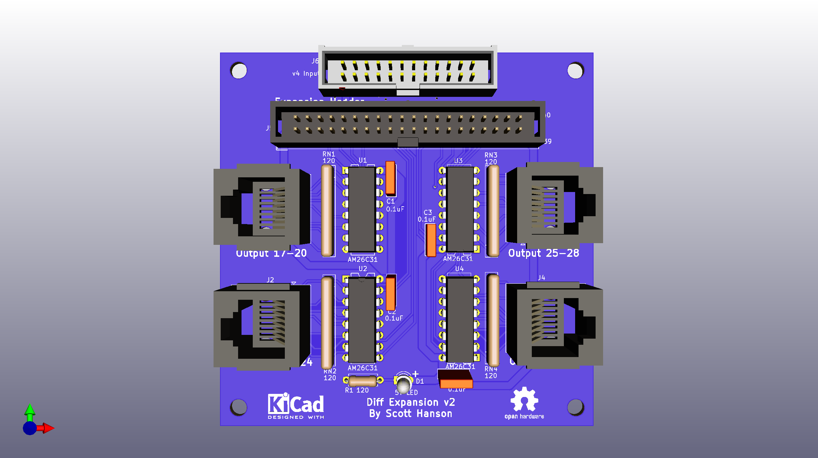
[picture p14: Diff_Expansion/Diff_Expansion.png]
Image of Diff Expansion


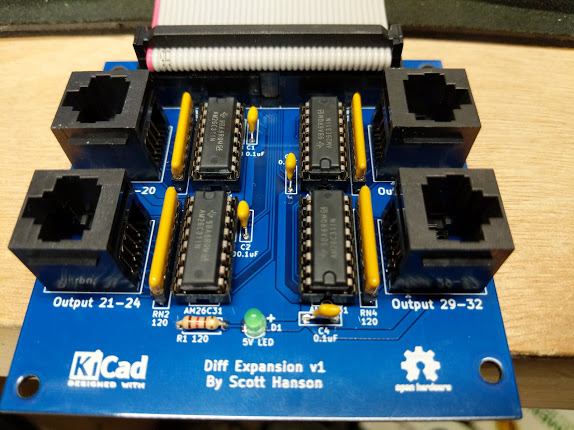
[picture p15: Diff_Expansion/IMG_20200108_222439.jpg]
Real Image of Diff Expansion


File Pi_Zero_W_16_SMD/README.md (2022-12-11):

# Copyright and Disclaimer
Copyright: Scott Hanson

This documentation describes Open Hardware and is licensed under the CERN Open Hardware Licence Version 2 - Strongly Reciprocal. (CERN-OHL-S)

You may redistribute and modify this documentation under the terms of the CERN OHL-S-v2 (https://ohwr.org/cern_ohl_s_v2.txt). This documentation is distributed WITHOUT ANY EXPRESS OR IMPLIED WARRANTY, INCLUDING OF MERCHANTABILITY, SATISFACTORY QUALITY AND FITNESS FOR A PARTICULAR PURPOSE. Please see the CERN OHL v2-S for applicable conditions

**Under CERN OHL-S-v2, derivative work must be publicy released as defined in subsection 3.3**

# Pi Zero W 16

**Never Built or tested**

The Pi Zero W 16 is a surface mount(SMD) controller with 16 local pixel ports and two remote receiver port(8 remote ports). A total of 24 pixel outputs. All the design files are open source and available on github.

## [Interactive BOM](https://computergeek1507.github.io/PB_16/Pi_Zero_W_16_SMD/bom/ibom)

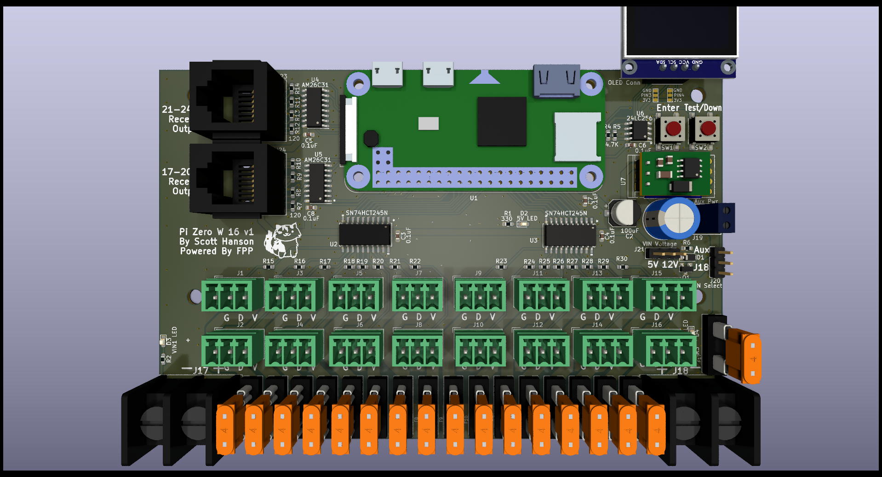
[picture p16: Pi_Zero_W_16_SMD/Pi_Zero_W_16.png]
Image of PB Pi Zero W 16


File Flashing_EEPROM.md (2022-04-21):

## Uploading Cape Firmware

Open the controllers FPP Home Page, goto “Help->About”

About

Scroll to Cape/Hat Firmware Upgrade

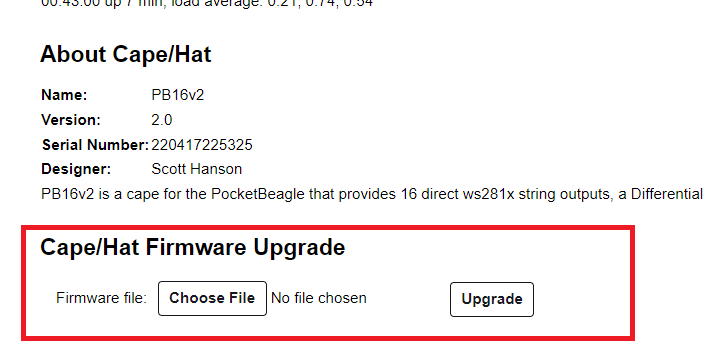
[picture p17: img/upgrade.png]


Upload the "eeprom.bin" file for the controller by clicking the "Choose File" button.
Once Selected Click the "Upgrade" button.

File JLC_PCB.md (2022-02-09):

## Ordering from [jlcpcb.com](https://jlcpcb.com/)

### Printed Circuit Board

Go to https://cart.jlcpcb.com/quote to upload the PCB design files.

Upload the "gerber.zip" file by clicking the "Add Gerber File" button.

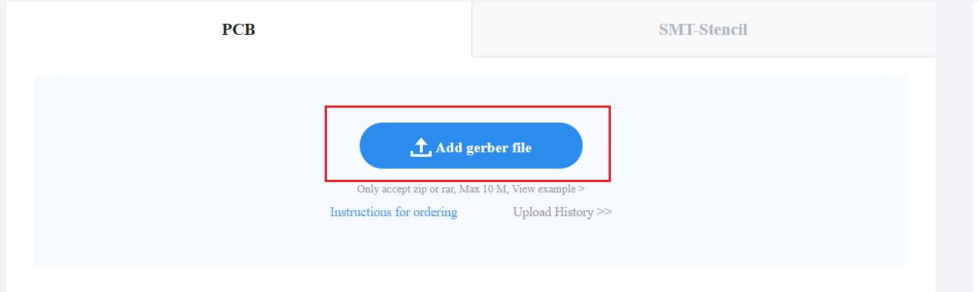
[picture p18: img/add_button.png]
Add Button


The default setting are correct, blue color PCB's are recommended, but it will add two days to the build time.

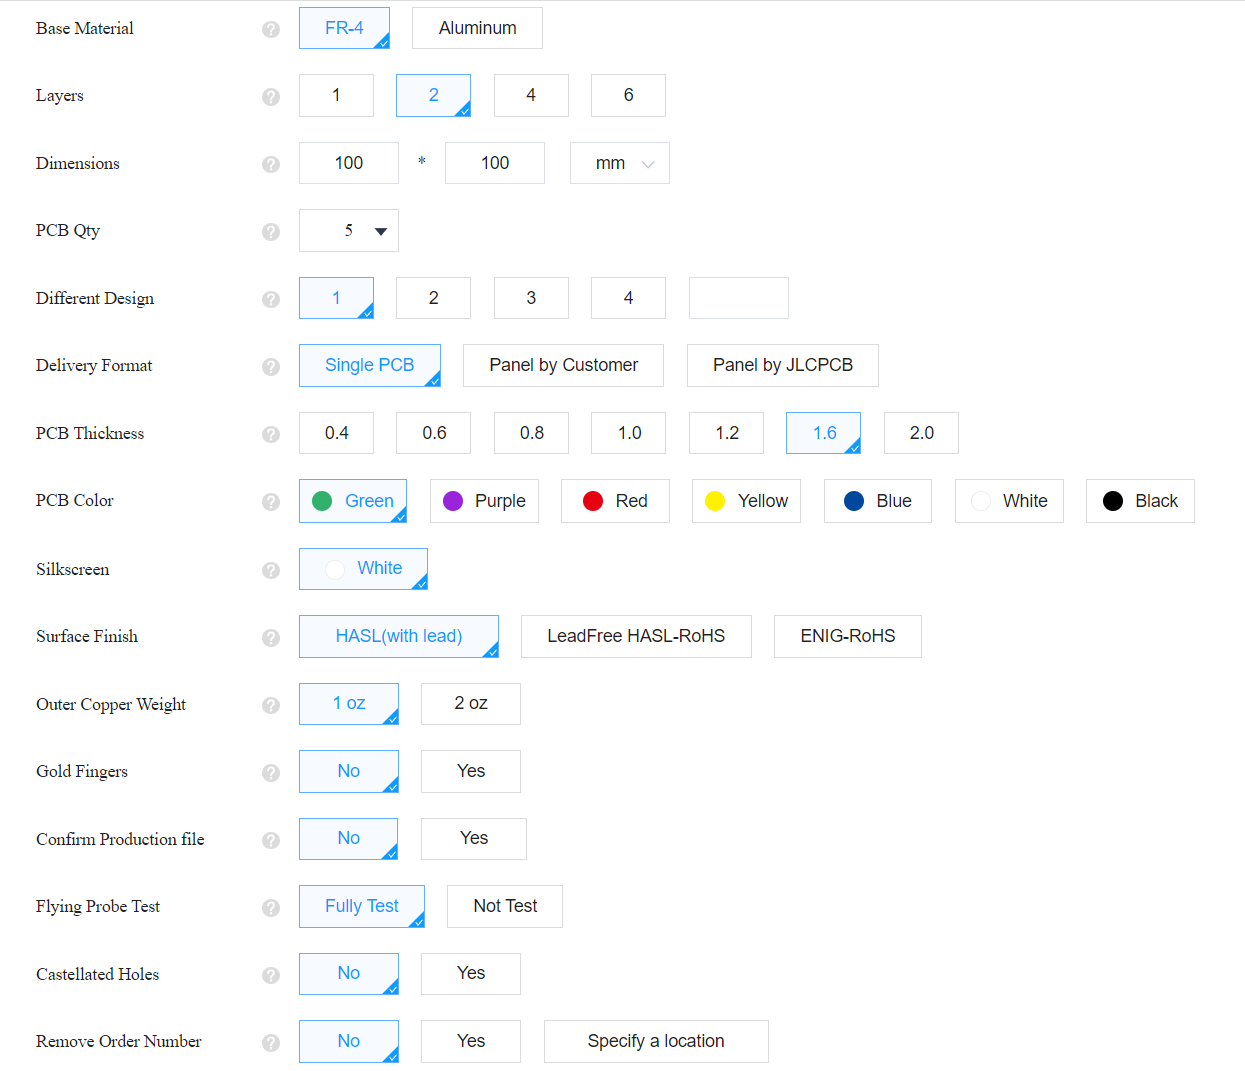
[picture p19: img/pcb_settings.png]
PCB Settings


### Surface Mount Assembly Service

****NOTE: Surface Mount Assembly Service**** is only required for designs ending in "SMD" or "SMT", all other designs can skip this step.

Scroll down and Enable the SMD service.

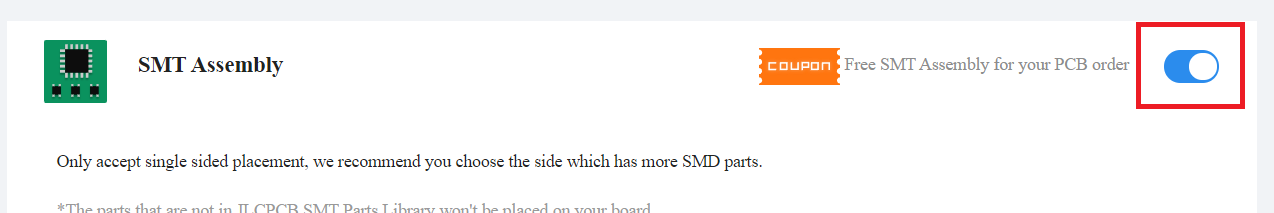
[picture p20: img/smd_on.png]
SMD ON


Select "Assemble top side" and "Added by JLCPCB" for tooling holes.

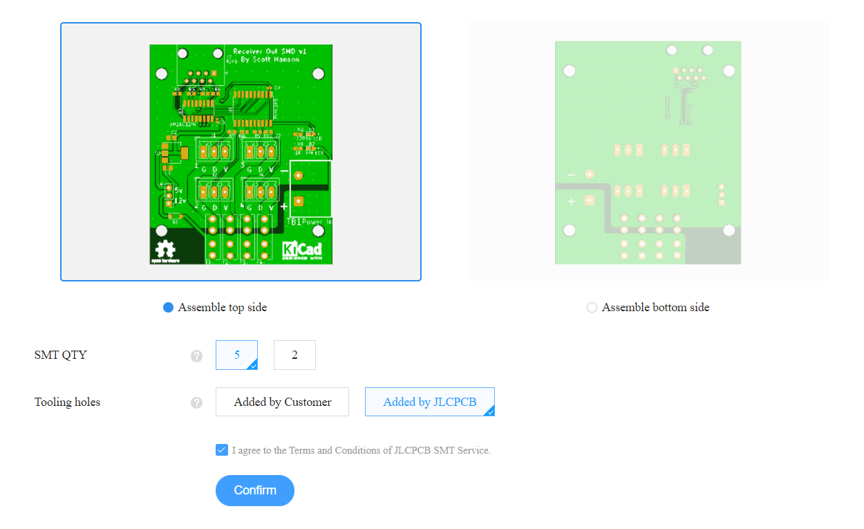
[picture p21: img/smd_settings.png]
SMD Settings


Then click "Next" on the right by the Calculated Price heading.

On the Next page, you will select the BOM and Part Position Files.

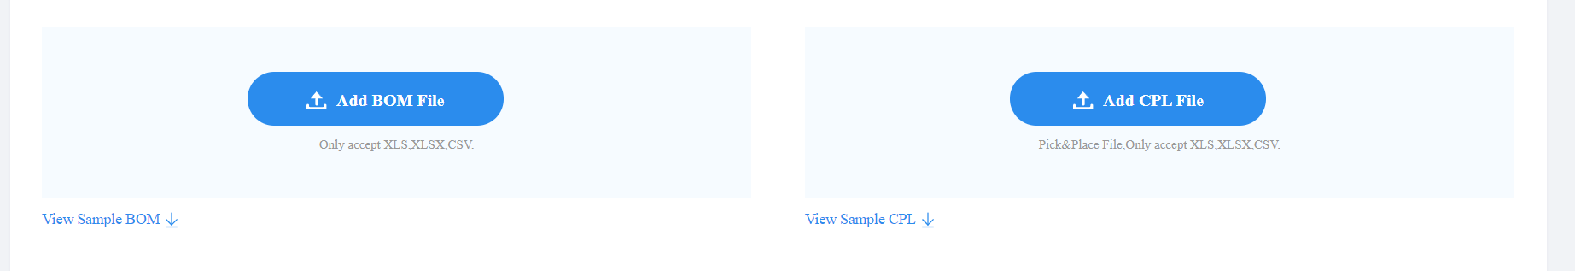
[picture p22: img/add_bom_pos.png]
Add BOM POS


'xxxxx_SMD.csv' is the SMD BOM and 'xxxxx-all-pos.csv' is the SMD CPL position file.

The next page will confirm all the BOM parts in the SMD CSV file. Select "Next" to proceed to placement review. If they are incorrect, let me know and I will update the LCSC part numbers.

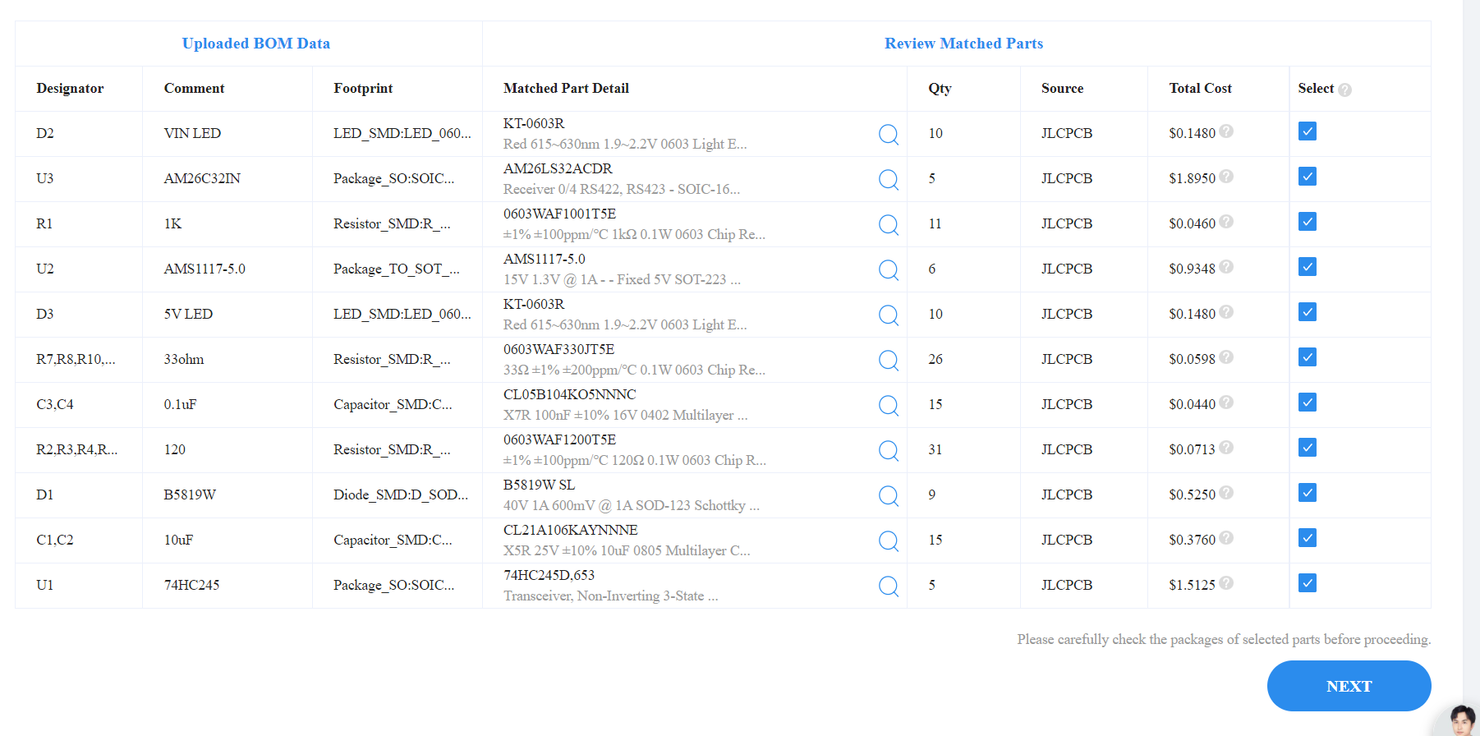
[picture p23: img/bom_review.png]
BOM Review


The final page will confirm all the part placements in the POS CSV file. The "dots" should match the pin 1 locations on the IC's. If they are incorrect, let me know and I will update the rotation values.

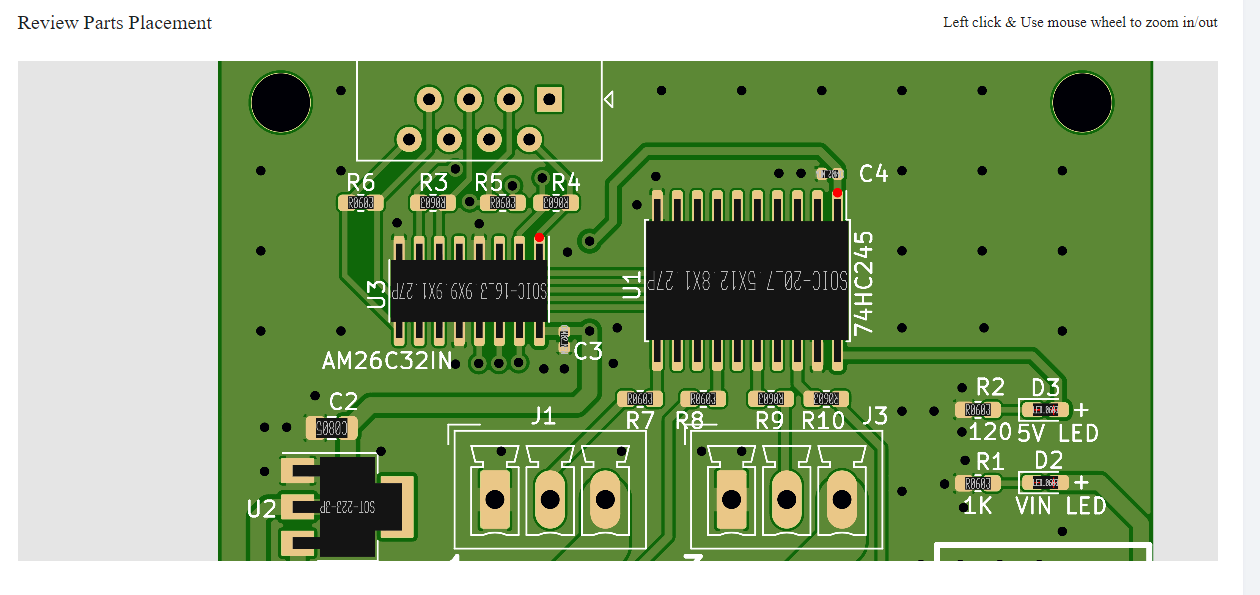
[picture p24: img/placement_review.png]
POS Review


Then Save to Cart and proceed to Checkout and Shipping like normal.

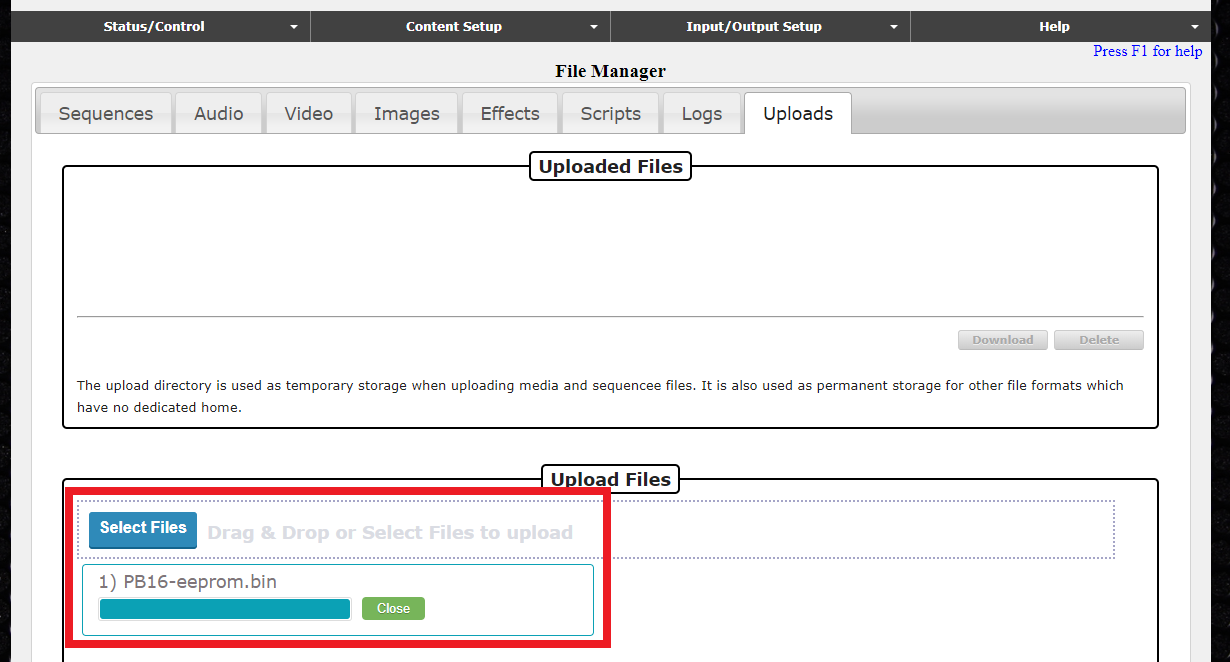
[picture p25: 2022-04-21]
img/upload.png

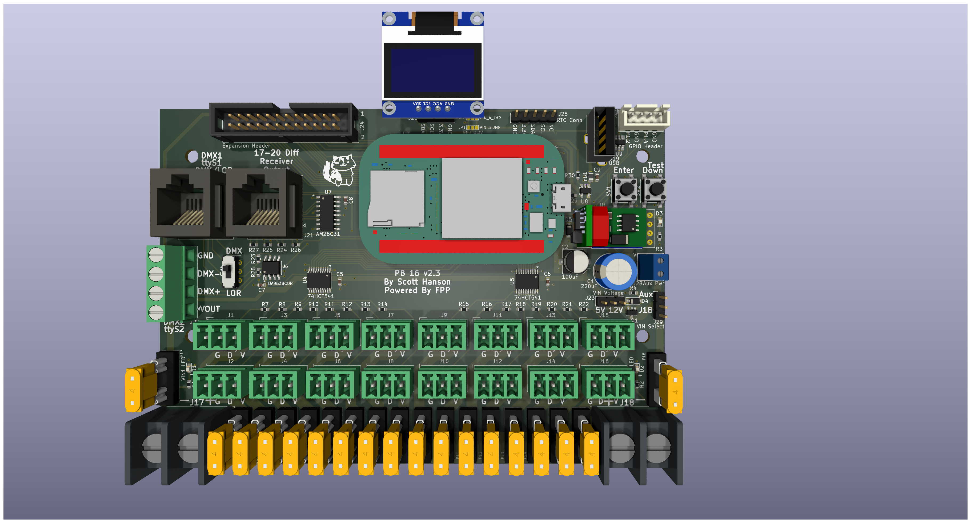
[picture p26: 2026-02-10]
PB_16v2_SMD/PB_16.png

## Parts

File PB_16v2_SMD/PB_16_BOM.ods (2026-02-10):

Designator | 220uF | Quantity | Digi-Key_PN | MPN | LCSC
C1 | 100uF | 1 | P5183-ND | ECA-1HM221 | C338228
C2 | 220uF | 1 | 493-2105-1-ND | UWX1C101MCL1GB | C134723
C3-C9 | 0.1uF | 7 | 1276-1935-2-ND | CL10B104KB8NNWC | C14663
D1, D2, D3 | LED | 3 | 160-1436-2-ND | LTST-C190KRKT | C2286
D4 | Zener 10V | 1 | MMSZ5240B-FDICT-ND | MMSZ5240B-7-F | C173431
D5 | Zener 5.1V | 1 | MMSZ5231B-FDICT-ND | MMSZ5231B-7-F | C173407
F1-F18 | Fuse Holder | 18 | 36-3544-2-ND | 3544-2 | C492610
F1-F17 Fuse | String Fuse | 17 | F989-ND | 0297005.WXNV
F18 Fuse | PB Fuse | 1 | F986-ND | 0297002.WXNV
FB1 | USB Ferrite | 1 | MU2029-151YCT-ND | MU2029-151Y | C1015
J1-J16 | String Plugs | 16 | 277-5737-ND | 1843619
J1-J16 Header | String Headers | 16 | ED10555-ND | OSTTJ0311530 | C192778
J17,J18 | Power In | 2 | ED2953-ND | OSTYK51102030 | C707421
J19 | USB | 1 | WM8672-ND | 1050570001 | C39455
J20,J21 | RJ45 | 2 | AE10392-ND | A-2014-2-4-R | C2938579
J22 | DMX2 | 1 | 277-1238-ND | 1729034 | C192769
J23 | Voltage Select | 1 | 732-5316-ND | 61300311121 | C49257
J24 | Expansion | 1 | S9175-ND | SBH11-PBPC-D20-ST-BK | C9138
J25 | RTC | 1 | 732-5318-ND | 61300511121 | C358687
J26 | OLED | 1 | S7002-ND | PPTC041LFBN-RC | C225501
J27 | GPIO | 1 | 455-2249-ND | B4B-XH-A(LF)(SN) | C144395
J28 | Aux Pwr | 1 | 277-1947-ND | 1727010 | C69811
J29 | VIN Select | 1 | 732-5316-ND | 61300311121 | C49257
Q1 | DMP3056L | 1 | DMP3056L-7DICT-ND | DMP3056L-7 | C150724
R1, R2 | 1K | 2 | 311-1.00KHRTR-ND | RC0603FR-071KL | C21190
R3 | 120 | 1 | A129677CT-ND | CRGCQ0603F120R | C22787
R4 | 100K | 1 | YAG1235CT-ND | RT0603BRD07100KL | C25803
R5, R6 | 4.7K | 2 | 311-4.7KGRCT-ND | RC0603JR-074K7L | C23162
R7-R22 | 33 | 16 | 311-33.0HRCT-ND | RC0603FR-0733RL | C23140
R23-R28 | 120 | 6 | A129677CT-ND | CRGCQ0603F120R | C22787
R29, R30 | 10K | 2 | 311-10.0KHRCT-ND | RC0603FR-0710KL | C25804
SW1,SW2 | Push Btn | 2 | CKN9088CT-ND | PTS645SL50SMTR92 LFS | C127509
SW4 | Slide Switch | 1 | CKN10723CT-ND | K3-2235D-F1 | C189615
U1 | OKI-78SR-5 | 1 | 811-2196-5-ND | OKI-78SR-5/1.5-W36-C
U2 | 24LC256 | 1 | 24LC256T-I/SNCT-ND | 24LC256T-I/SN | C6482
U3 | POCKETBEAGLE-SC-569 | 1 | POCKETBEAGLE-SC-569-ND | POCKETBEAGLE-SC-569
U4, U5 | SN74HCT245N | 2 | MC74HCT541ADTR2GOSTR-ND | SN74HCT541PWR | C133641
U6 | UA9638CDR | 1 | 296-15058-1-ND | UA9638CDR | C435812
U7 | AM26C31 | 1 | 296-24344-1-ND | AM26C31IDR | C157476
U8 | TPS2051BDBVR | 1 | 296-21265-1-ND | TPS2051BDBVR | C24593
U9 | TPD4S009DBVR | 1 | 296-23749-1-ND | TPD4S009DBVR | C88032

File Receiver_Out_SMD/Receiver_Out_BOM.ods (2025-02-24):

Qty | Comment | Designator | LCSC_PN | Digi-Key_PN | MPN
2 | 10uF | C1,C2 | C15850 | 490-5523-1-ND | GRM21BR61E106KA73L
3 | 0.1uF | C3,C4,C5 | C1525 | 1292-1630-1-ND | 0402B104K160CT
1 | B5819W | D1 | C8598 | B5819W-TPMSCT-ND | B5819W-TP
3 | VIN/5V/Test LED | D2,D3,D4 | C2286 | 732-4984-1-ND | 150080RS75000
4 | 3544-2 | F2,F3,F4,F1 | C492610 | 36-3544-2-ND | 3544-2
4 | String1-4 | J1,J2,J3,J4 | C192778 | 277-5737-ND | 1843619
4 | String1-4 Plugs | J1,J2,J3,J4 |  | ED10555-ND | OSTTJ0311530
1 | PGM | J5
1 | VIN_Voltage | J6 | C49257 | 732-5316-ND | 61300311121
1 | VIN_Voltage JMP | J6 |  | S9341-ND | NPC02SXON-RC
1 | RJ45 | J7 | C2938579 | AE10392-ND | A-2014-2-4-R
1 | 1K | R1 | C21190 | 311-1.00KHRCT-ND | RC0603FR-071KL
6 | 120 | R2,R3,R4,R5,R6,R11 | C22787 | A129677CT-ND | CRGCQ0603F120R
4 | 33ohm | R7,R8,R10,R9 | C23140 | 311-33GRCT-ND | RC0603JR-0733RL
1 | Test Btn | SW1 | C255812 | CT3088CT-ND | 222AMVBAR
1 | Power In | TB1 | C306200 | A98472-ND | 4DB-P108-02
1 | AMS1117-5.0 | U2 | C6187 | 488-LM1117MPX-50NOPBCT-ND | LM1117MPX-50NOPB
1 | AM26C32IN | U3 | C6180 | 296-37322-1-ND | AM26C32INSR
1 | 74HCT541PW | U4 | C131314 | 1727-4099-1-ND | 74HCT541PW,118
1 | ATtiny1616-M | U5 | C507118 | ATTINY1616-MNRCT-ND | ATTINY1616-MNR

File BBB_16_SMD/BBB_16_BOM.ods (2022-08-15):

D:\PB_16\BBB_16_SMD\BBB_16.kicad_sch
Qty | Reference(s) | Value | Digi-Key_PN | LCSC | MPN
1 | C1 | 220uF | P5183-ND | C88784 | ECA-1HM221
1 | C2 | 100uF | 493-2105-1-ND | C134723 | UWX1C101MCL1GB
5 | C3, C4, C5,C6, C7 | 0.1uF | 1276-1935-2-ND | C14663 | CL10B104KB8NNWC
1 | D1 | Zener 10V | MMSZ5240B-FDICT-ND | C173431 | MMSZ5240B-7-F
3 | D4, D5, D5 | LEDs | 160-1436-2-ND | C2286 | LTST-C190KRKT
18 | F1-F18 | 3544-2 | 36-3544-2-ND | C492610 | 3544-2
17 | F1-F16, F18 Fuses | FUSE AUTO 5A 32VDC BLADE MINI | F989-ND |  | 0297005.WXNV
1 | F17 Fuse | FUSE AUTO 2A 32VDC BLADE MINI | F986-ND |  | 0297002.WXNV
16 | J1-J16 | String Ports | 277-11320-ND | C8389 | 5444657
16 | J1-J16 Plugs | String Ports | ED2876-ND |  | OSTTJ0331530
2 | J17, J18 | Power Ins | ED2953-ND | C707421 | OSTYK51102030
1 | J19 | GPIO | 455-2249-ND | C144395 | B4B-XH-A(LF)(SN)
2 | J20, J21 | RJ45 | AE10392-ND | C305972 | A-2014-2-4-R
1 | J22 | DMX2 | 277-1238-ND | C192769 | 1729034
2 | J23, J28 | VIN Voltage/Select | 732-5316-ND | C49257 | 61300311121
2 | J23, J28 Jumpers |  | S9341-ND |  | NPC02SXON-RC
1 | J24 | Expansion Header | ED10525-ND | C221083 | 302-S241
1 | J25 | RTC Conn | 732-5318-ND | C358687 | 61300511121
1 | J26 | OLED | S7002-ND | C225501 | PPTC041LFBN-RC
1 | J27 | Aux Pwr | 277-1947-ND | C69811 | 1727010
1 | Q1 | DMP3056L | DMP3056L-7DICT-ND | C150724 | DMP3056L-7
7 | R1, R2, R3, R15, R16, R17, R18 | 120 | A129677CT-ND | C22787 | CRGCQ0603F120R
2 | R4, R5 | 1K | 311-1.00KHRTR-ND | C21190 | RC0603FR-071KL
2 | R6, R7 | 4.7K | 311-4.7KGRCT-ND | C23162 | RC0603JR-074K7L
2 | R8, R11 | 100 | RMCF0603FT100RCT-ND | C22775 | RMCF0603FT100R
3 | R9, R12, R35 | 10K | 311-10.0KHRCT-ND | C25804 | RC0603FR-0710KL
2 | R10, R13 | 680 | 311-680HRCT-ND | C23228 | RC0603FR-07680RL
1 | R14 | 100K | YAG1235CT-ND | C25803 | RT0603BRD07100KL
16 | R19 - R34 | 33 | 311-33.0HRCT-ND | C23140 | RC0603FR-0733RL
5 | SW1-SW5 | BTNs | CKN9088CT-ND | C127509 | PTS645SL50SMTR92 LFS
1 | SW6 | DMX_LOR_Select | 401-2001-ND | C221663 | JS202011CQN
1 | U1 | BEAGLEBONEBLACK | BBB01-SC-505-ND |  | BBB01-SC-505
2 | U1 Header |  | S2012EC-23-ND |  | PREC023DAAN-RC
1 | U2 | 5V Reg | 811-2196-5-ND or 102-P7805-2000-S-ND |  | OKI-78SR-5/1.5-W36-C or P7805-2000-S
2 | U3, U4 | SN74HCT245N | 296-8279-1-ND | C133641 | SN74HC245PWR
2 | U5, U7 | AM26C31 | 296-23457-1-ND | C34923 | AM26C31MDREP
1 | U6 | 24L256 | 24LC256T-I/MSCT-ND | C6482 | 24LC256T-I/MS

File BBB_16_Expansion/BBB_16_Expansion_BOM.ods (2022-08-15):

Qty | Reference(s) | Value | Digi-Key_PN | LCSC | MPN
1 | C1 | 220uF | P5183-ND | C88784 | ECA-1HM221
1 | C2 | 100uF | 493-2105-1-ND | C134723 | UWX1C101MCL1GB
4 | C3, C4, C5, C6 | 0.1uF | 1276-1007-1-ND | C14663 | CC0603KRX7R9BB104
1 | C7 | 10uF | 493-2173-1-ND | C72485 | UWT1C100MCL1GB
1 | D1 | 5V LED | 160-1423-1-ND | C2297 | LTST-C171GKT
1 | D2 | Zener 10V | MMSZ5240B-FDICT-ND | C173431 | MMSZ5240B-7-F
1 | F1 | 3544-2 | 36-3544-2-ND | C492610 | 3544-2
1 | F1 Fuse | FUSE AUTO 2A 32VDC BLADE MINI | F986-ND |  | 0297002.WXNV
3 | J1-J3 | Outputs | ED10525-ND | C221083 | Z-S311024S1GK1A
1 | J4 | RTC Conn | 732-5318-ND | C358687 | MTP125-1105S1
1 | J5 | OLED Conn | S7002-ND | C225501 | A2541HWV-4P
1 | J6 | Pwr In | 277-1947-ND | C69811 | 1727010
2 | J7, J8 | DMX | 2057-EBWA-03-B-ND | C36780 | EBWA-03-B
1 | J10 | VIN Voltage | 732-5316-ND | C49257 | 61300311121
1 | J10 Jumper |  | S9341-ND |  | NPC02SXON-RC
1 | Q1 | DMP3056L | DMP3056L-7DICT-ND | C150724 | DMP3056L-7
1 | R1 | 1K | 311-1.00KCRCT-ND | C17513 | RC0805FR-071KL
2 | R2, R3 | 120 | 311-120ARCT-ND | C17437 | RC0805JR-07120RL
4 | R4, R5, R7, R8 | 4.7K | 311-4.7KARCT-ND | C17673 | RC0805JR-074K7L
1 | R6 | 100K | YAG1235CT-ND | C25803 | RT0603BRD07100KL
5 | SW1-SW5 | BUTTONS | 450-1650-ND | C428628 | 1825910-6
1 | U1 | BEAGLEBONEBLACK
2 | U1 Header |  | S2012EC-23-ND |  | PREC023DAAN-RC
2 | U2, U5 | SP3485EN | 1016-1171-5-ND | C6855 | SP485EEN-L
1 | U3 | 24LC256 | 24LC256T-I/SNCT-ND | C6482 | 24LC256T-I/SN
1 | U4 | Universe5V | 811-2196-5-ND |  | OKI-78SR-5/1.5-W36-C

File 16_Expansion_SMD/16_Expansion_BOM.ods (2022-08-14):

Comment | Designator | Digi-Key_PN | MPN | LCSC
0.1uF | C1,C2 | 478-1395-1-ND | 08055C104KAT2A | C49678
10uF | C3 | 493-2173-1-ND | UWT1C100MCL1GB | C72485
VIN1 LED | D3 | 732-4986-1-ND | 150080VS75000 | C2297
VIN2 LED | D4 | 732-4986-1-ND | 150080VS75000 | C2297
5V LED | D5 | 732-4986-1-ND | 150080VS75000 | C2297
3544-2 | F2,F3,F4,F5,F6,F7,F8,F1,F10,F11,F12,F13,F14,F15,F16,F9 | 36-3544-2-ND | 3544-2
String1 | J1 | 277-5737-ND/ED10555-ND | 1843619/OSTTJ0311530
String10 | J10 | 277-5737-ND/ED10555-ND | 1843619/OSTTJ0311530
String11 | J11 | 277-5737-ND/ED10555-ND | 1843619/OSTTJ0311530
String12 | J12 | 277-5737-ND/ED10555-ND | 1843619/OSTTJ0311530
String13 | J13 | 277-5737-ND/ED10555-ND | 1843619/OSTTJ0311530
String14 | J14 | 277-5737-ND/ED10555-ND | 1843619/OSTTJ0311530
String15 | J15 | 277-5737-ND/ED10555-ND | 1843619/OSTTJ0311530
String16 | J16 | 277-5737-ND/ED10555-ND | 1843619/OSTTJ0311530
Power In Left | J17 | ED2953-ND | OSTYK51102030
Power In Right | J18 | ED2953-ND | OSTYK51102030
Expansion Header | J19 | S9175-ND | SBH11-PBPC-D20-ST-BK
String2 | J2 | 277-5737-ND/ED10555-ND | 1843619/OSTTJ0311530
String3 | J3 | 277-5737-ND/ED10555-ND | 1843619/OSTTJ0311530
String4 | J4 | 277-5737-ND/ED10555-ND | 1843619/OSTTJ0311530
String5 | J5 | 277-5737-ND/ED10555-ND | 1843619/OSTTJ0311530
String6 | J6 | 277-5737-ND/ED10555-ND | 1843619/OSTTJ0311530
String7 | J7 | 277-5737-ND/ED10555-ND | 1843619/OSTTJ0311530
String8 | J8 | 277-5737-ND/ED10555-ND | 1843619/OSTTJ0311530
String9 | J9 | 277-5737-ND/ED10555-ND | 1843619/OSTTJ0311530
1K | R1,R2 | 311-1.00KCRCT-ND | RC0805FR-071KL | C17513
330 | R3 | 311-330CRCT-ND | RC0805FR-07330RL | C17630
120 | R20-R35 | RMCF0603JT120RCT-ND | RMCF0603JT120R | C22787
33 | RN2,RN1,RN4,RN3 | 4608X-2-330LF-ND | 4608X-102-330LF
74HC245 | U1,U2 | 296-8279-1-ND | SN74HC245PWR | C5625

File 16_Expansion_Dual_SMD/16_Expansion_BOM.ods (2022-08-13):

Qty | Comment | Designator | Digi-Key_PN | MPN | LCSC
2 | 0.1uF | C1,C2 | 478-1395-1-ND | 08055C104KAT2A | C49678
1 | 10uF | C3 | 493-2173-1-ND | UWT1C100MCL1GB | C72485
3 | LEDs | D3-D5 | 732-4986-1-ND | 150080VS75000 | C2297
16 | 3544-2 | F1-F16 | 36-3544-2-ND | 3544-2
16 | Fuses | F1-F16 Fuses | F989-ND | 0297005.WXNV
16 | Pixel String Ports | J1-J16 | 277-5737-ND/ED10555-ND | 1843619/OSTTJ0311530
2 | Power Ins | J17, J18 | ED2953-ND | OSTYK51102030
1 | Expansion Header | J19 | S9175-ND | SBH11-PBPC-D20-ST-BK
1 | v4 Headed | J20 | ED10525-ND | 302-S241
2 | 1K | R1,R2 | 311-1.00KCRCT-ND | RC0805FR-071KL | C17513
1 | 330 | R3 | 311-330CRCT-ND | RC0805FR-07330RL | C17630
16 | 33 | R4-R19 | 2571-CN34J330CTTR-ND | CN34J330CT | C23140
32 | 120 | R20-R51 | RMCF0603JT120RCT-ND | RMCF0603JT120R | C22787
2 | 74HC245 | U1,U2 | 296-8279-1-ND | SN74HC245PWR | C5625

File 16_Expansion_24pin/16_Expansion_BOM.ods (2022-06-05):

Reference | Description | Quantity | Digi-Key Part Number
C1-C2 | CAP CER 0.1UF 50V X7R RADIAL | 2 | 478-7336-1-ND
C3 | CAP ALUM 10UF 20% 16V RADIAL | 1 | 399-6597-ND
D1,D2 | DIODE SCHOTTKY 100V 5A DO201AD | 2 | SB5100DICT-ND
D3,D4,D5 | LED GREEN DIFFUSED T-1 T/H | 3 | 754-1217-ND
F1-F16 Fuses | FUSE AUTO 5A 32VDC BLADE MINI | 16 | F989-ND
F1-F16 | FUSE BLOCK BLADE 500V 20A PCB | 16 | 36-3544-2-ND
J17,J18 | CONN BARRIER STRIP 2CIRC 0.374" | 2 | ED2953-ND
J1-J16 | TERM BLOCK HDR 3POS VERT 3.5MM | 16 | 277-5737-ND
J1-J16 Pixel Plugs | TERM BLOCK PLUG 3POS STR 3.5MM | 16 | ED10555-ND
J20 | CONN HEADER VERT 24POS 2.54MM | 1 | ED10525-ND
R1,R2 | RES 1K OHM 1/4W 5% AXIAL | 2 | CF14JT1K00CT-ND
R3 | RES 120 OHM 1/4W 5% AXIAL | 1 | CF14JT120RCT-ND
RN1-RN4 | RES ARRAY 4 RES 33 OHM 8SIP | 4 | 4608X-2-330LF-ND
RN1-RN4 Sockets | CONN SOCKET 8POS 0.1 GOLD PCB | 4 | 1212-1097-ND
U1,U2 | IC TXRX NON-INVERT 5.5V 20DIP | 2 | 296-1612-5-ND
U1,U2 Sockets | CONN IC DIP SOCKET 20POS TIN | 2 | AE9998-ND

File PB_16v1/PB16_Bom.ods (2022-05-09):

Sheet: PB16_Bom
Reference | Description | Quantity | Digi-Key Part Number | Alt Digi-Key Part Number | Mouser Part Number | Tayda SKU | MPN | Aliexpress links
C1 | CAP ALUM 220UF 20% 50V RADIAL | 1 | P5183-ND |  | 80-ESK227M050AH9KA | A-4547 | ECA-1HM221 | https://www.aliexpress.com/item/32886248789.html?spm=a2g0s.9042311.0.0.27424c4d3bSt0w
C2 | CAP ALUM 100UF 20% 16V RADIAL | 1 | 1189-1148-ND |  | 80-ESK107M016AC3AA | A-4146 | 16ZLH100MEFC5X11 | https://www.aliexpress.com/item/32886248789.html?spm=a2g0s.9042311.0.0.27424c4d3bSt0w
C3-C8 | CAP CER 0.1UF 50V X7R RADIAL | 6 | 478-7336-1-ND |  | 594-K104K15X7RF5TH5 | A-553 | SR215C104KARTR1 | https://www.aliexpress.com/item/32429917283.html?spm=a2g0s.9042311.0.0.27424c4dvo0FgD
D1,D2 | DIODE SCHOTTKY 100V 5A DO201AD | 2 | SB5100DICT-ND |  | 621-SB5100T |  | SB5100-T | https://www.aliexpress.com/item/32853424313.html?spm=a2g0s.9042311.0.0.27424c4dvo0FgD
D3 | DIODE ZENER 5.1V 5W AXIAL | 1 | 1N5338BRLGOSCT-ND |  | 512-1N4733AT50A | A-169 | 1N5338BRLG | https://www.aliexpress.com/item/32854094468.html?spm=a2g0s.9042311.0.0.27424c4dvo0FgD
D4,D5,D6 | LED GREEN DIFFUSED T-1 T/H | 3 | 754-1217-ND |  | 859-LTL-4231N | A-262 | WP3A8GD | https://www.aliexpress.com/item/32826443536.html?spm=a2g0s.9042311.0.0.27424c4d3bSt0w
F17 Fuse | FUSE AUTO 2A 32VDC BLADE MINI | 1 | F986-ND |  | 576-0297002.WXNV |  | 0297002.WXNV | https://www.aliexpress.com/item/32919446549.html?spm=a2g0s.9042311.0.0.78ce4c4dzTHxuo
F19 | PTC RESET FUSE 72V 500MA RADIAL | 1 | RXEF050-2HFCT-ND |  | 650-RXEF050-2 | A-5234 | RXEF050-2
F1-F16, F18 Fuses | FUSE AUTO 5A 32VDC BLADE MINI | 17 | F989-ND |  | 576-0297005.WXNV |  | 0297005.WXNV | https://www.aliexpress.com/item/32919446549.html?spm=a2g0s.9042311.0.0.78ce4c4dzTHxuo
F1-F18 | FUSE BLOCK BLADE 500V 20A PCB | 18 | 36-3544-2-ND |  | 534-3544-2 |  | 3544-2 | https://www.aliexpress.com/item/4000541186880.html?spm=a2g0s.9042311.0.0.27424c4dTVdR23
J17,J18 | CONN BARRIER STRIP 2CIRC 0.374" | 2 | ED2953-ND |  | 538-38720-7502 or 571-14376644 | A-2793 | OSTYK51102030 | https://www.aliexpress.com/item/1005002136115175.html?spm=a2g0o.productlist.0.0.1950561bL3DRIy
J19 | CONN RCPT USB2.0 TYPEA 4POS VERT | 1 | WM8672-ND |  | 571-1734366-3 | A-5358 | 1050570001
J1-J16 | TERM BLOCK HDR 3POS VERT 3.5MM | 16 | 277-5737-ND |  | 710-691321100003 |  | 1843619 | https://www.aliexpress.com/item/4000660083322.html?spm=a2g0s.9042311.0.0.27424c4d3bSt0w
J1-J16 Pixel Plugs | TERM BLOCK PLUG 3POS STR 3.5MM | 16 | ED10555-ND |  | 710-691361100003 |  | OSTTJ0311530 | https://www.aliexpress.com/item/4000660083322.html?spm=a2g0s.9042311.0.0.27424c4d3bSt0w
J20,J21 | CONN MOD JACK 8P8C VERT UNSHLD | 2 | AE10392-ND |  | 571-55202594 |  | A-2014-2-4-R | https://www.aliexpress.com/item/4000641016208.html?spm=a2g0s.9042311.0.0.27424c4dTVdR23
J22 | TERM BLK 4POS SIDE ENTRY 5MM PCB | 1 | 277-1238-ND |  | 651-1729034 or 490-TB002-500-04BE | 2 x A-664 | 1729034
J23, J29 | CONN HEADER VERT 3POS 2.54MM | 2 | 732-5316-ND |  | 710-61300311121 | A-5774 | 61300311121 | https://www.aliexpress.com/item/32993182990.html?spm=a2g0s.9042311.0.0.27424c4dvo0FgD
J24 | CONN HEADER VERT 40POS 2.54MM | 1 | S9175-ND |  | 517-30340-6002 | A-2976 | SBH11-PBPC-D20-ST-BK | https://www.aliexpress.com/item/32841491526.html?spm=a2g0s.9042311.0.0.27424c4dvo0FgD
J25 | CONN HEADER VERT 5POS 2.54MM | 1 | 732-5318-ND |  | 710-61300511121 | A-5775 | 61300511121 | https://www.aliexpress.com/item/32993182990.html?spm=a2g0s.9042311.0.0.27424c4dvo0FgD
J26 | CONN HDR 4POS 0.1 TIN PCB | 1 | S7002-ND |  |  | A-1303 | PPTC041LFBN-RC | https://www.aliexpress.com/item/32867179300.html?spm=a2g0s.9042311.0.0.27424c4dvo0FgD
J27 | CONN HEADER VERT 4POS 2.5MM | 1 | 455-2249-ND |  | 855-M20-7820442 |  | B4B-XH-A(LF)(SN)
J28 | TERM BLK 2P SIDE ENT 3.81MM PCB | 1 | 277-1947-ND |  | 651-1727010 |  | 1727010
J23/J29 Power Jumper | CONN JUMPER SHORTING .100" GOLD | 2 | S9341-ND |  |  | A-1324 | NPC02SXON-RC | https://www.aliexpress.com/item/33016645429.html?spm=a2g0s.9042311.0.0.78ce4c4dzTHxuo
R1,R2,R3 | RES 120 OHM 1/4W 5% AXIAL | 3 | CF14JT120RCT-ND |  | 603-CFR-25JT-52-120R | A-2057 | CF14JT120R | https://www.aliexpress.com/item/32835738578.html?spm=a2g0s.9042311.0.0.78ce4c4dzTHxuo
R4,R5 | RES 1K OHM 1/4W 5% AXIAL | 2 | CF14JT1K00CT-ND |  | 603-CFR-12JB-52-1K | A-2123 | CF14JT1K00 | https://www.aliexpress.com/item/32979849787.html?spm=a2g0s.9042311.0.0.78ce4c4dzTHxuo
R6,R7 | RES 4.7K OHM 1/4W 5% AXIAL | 2 | CF14JT4K70 |  | 603-CFR-12JB-52-4K7 | A-2027 | CF14JT4K70 | https://www.aliexpress.com/item/32979849787.html?spm=a2g0s.9042311.0.0.78ce4c4dzTHxuo
RN1-RN4 | RES ARRAY 4 RES 33 OHM 8SIP | 4 | 4608X-2-330LF-ND |  | 774-77083330P |  | 4608X-102-330LF
RN1-RN4 Sockets | CONN SOCKET 8POS 0.1 GOLD PCB | 4 | 1212-1097-ND |  |  | A-1605 | 310-87-108-41-001101 | https://www.aliexpress.com/item/32847506950.html?spm=a2g0s.9042311.0.0.27424c4dvo0FgD
SW1, SW2, SW3 | SWITCH SLIDE DPDT 300MA 6V | 3 | 401-2001-ND |  | 611-JS202011JCQN |  | JS202011CQN
SW4, SW5 | SWITCH TACTILE SPST-NO 0.05A 24V | 2 | 1825910-6 |  | 611-SM43JSMTR92LFS | A-5127 | 1825910-6 | https://www.aliexpress.com/item/32960657626.html?spm=a2g0s.9042311.0.0.27424c4dTVdR23
U1 P1 & P2 Headers | CONN HEADER VERT 36POS 2.54MM | 2 | 732-5309-ND |  | 649-77313-818-36LF | A-2458 | 61303621121
U1 P1 & P2 Sockets | CONN HDR 36POS 0.1 GOLD PCB | 2 | S7121-ND |  |  | A-195 | PPPC182LFBN-RC
‎U1-POCKETBEAGLE | POCKETBEAGLE OSD3358 EVAL BRD | 1 | POCKETBEAGLE-SC-569-ND |  | 958-PKTBEAGLE-SC-569 |  | POCKETBEAGLE-SC-569
U2 | DC DC CONVERTER 5V 8W | 1 | 811-2196-5-ND | 102-P7805-2000-S-ND | 595-TPSM84205EAB |  | OKI-78SR-5/1.5-W36-C | https://www.aliexpress.com/item/32817933017.html?spm=a2g0s.9042311.0.0.78ce4c4dzTHxuo
U3,U4 | IC TXRX NON-INVERT 5.5V 20DIP | 2 | 296-1612-5-ND |  | 595-SN74HCT245N | A-3695 | SN74HCT245N | https://www.aliexpress.com/item/32817933017.html?spm=a2g0s.9042311.0.0.78ce4c4dzTHxuo
U3,U4 Sockets | CONN IC DIP SOCKET 20POS TIN | 2 | AE9998-ND |  | 571-1-2199298-6 | A-1600 | A 20-LC-TT | https://www.aliexpress.com/item/32982748544.html?spm=a2g0s.9042311.0.0.78ce4c4dzTHxuo
U5 | IC DRIVER 2/0 8DIP | 1 | 296-15059-5-ND |  | 595-UA9638CP |  | UA9638CP
U5/U6 Socket | CONN IC DIP SOCKET 8POS TIN | 2 | AE9986-ND |  | 571-1-2199298-2 | A-001 | A 08-LC-TT | https://www.aliexpress.com/item/32982748544.html?spm=a2g0s.9042311.0.0.78ce4c4dzTHxuo
U6 | IC EEPROM 256K I2C 1MHZ 8DIP | 1 | 24LC256-E/P-ND |  | 579-24LC256-E/P | A-2369 | 24LC256
USB to Ethernet Adapter | USB 2.0 to 10/100 Ethernet Network Adapter | 1 | https://www.amazon.com/gp/product/B00M77HLII/ref=ppx_yo_dt_b_search_asin_title?ie=UTF8&th=1
Micro SD Card | SanDisk Ultra 32GB UHS-I Class 10 microSDHC Card | 1 | https://www.amazon.com/SanDisk-Ultra-SDSQUNS-032G-GN3MN-UHS-I-microSDHC/dp/B074B28H3S
Optional OLED Display | 0.96" I2C 128X64 OLED LCD Display | 1 | https://www.amazon.com/gp/product/B06XRBTBTB/ref=ppx_yo_dt_b_asin_title_o00_s00?ie=UTF8&psc=1 |  |  |  |  | https://www.aliexpress.com/item/4000433885018.html?spm=a2g0s.9042311.0.0.78ce4c4dzTHxuo
Optional Real Time Clock | PCF8523 REAL TIME CLOCK BOARD | 1 | 1528-1787-ND

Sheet: PB16_Minimal_Bom
This BOM is intended to be the bare minimum for a 16 port controller, It has no Serial Outputs, no IO headers and no pocketbeagle headers
Reference | Description | Quantity | Digi-Key Part Number
C1 | CAP ALUM 220UF 20% 50V RADIAL | 1 | P5183-ND
C2 | CAP ALUM 100UF 20% 16V RADIAL | 1 | 1189-1148-ND
C3,C4,C6,C7 | CAP CER 0.1UF 50V X7R RADIAL | 4 | 478-7336-1-ND
D1,D2 | DIODE SCHOTTKY 100V 5A DO201AD | 2 | SB5100DICT-ND
D3 | DIODE ZENER 5.1V 5W AXIAL | 1 | 1N5338BRLGOSCT-ND
F1-F17 | FUSE BLOCK BLADE 500V 20A PCB | 17 | 36-3544-2-ND
F19 | PTC RESET FUSE 72V 500MA RADIAL | 1 | RXEF050-2HFCT-ND
F1-F16 Fuses | FUSE AUTO 5A 32VDC BLADE MINI | 16 | F989-ND
F17 Fuse | FUSE AUTO 2A 32VDC BLADE MINI | 1 | F986-ND
J1-J16 | TERM BLOCK HDR 3POS VERT 3.5MM | 16 | 277-5737-ND
J1-J16 Pixel Plugs | TERM BLOCK PLUG 3POS STR 3.5MM | 16 | ED10555-ND
J17,J18 | 2 Circuit Barrier Block Screws Connector 9.50mm | 2 | ED2953-ND
J19 | CONN RCPT USB2.0 TYPEA 4POS VERT | 1 | WM8672-ND
J23,J29 | CONN HEADER VERT 3POS 2.54MM | 2 | 732-5316-ND
J23/29 Power Jumper | CONN JUMPER SHORTING .100" GOLD | 2 | S9341-ND
RN1-RN4 | RES ARRAY 4 RES 33 OHM 8SIP | 4 | 4608X-2-330LF-ND
‎U1-POCKETBEAGLE | POCKETBEAGLE OSD3358 EVAL BRD | 1 | POCKETBEAGLE-SC-569-ND
U1 P1 & P2 Headers | CONN HEADER VERT 36POS 2.54MM | 2 | 732-5309-ND
U2 | DC DC CONVERTER 5V 8W | 1 | 811-2196-5-ND
U3,U4 | IC TXRX NON-INVERT 5.5V 20DIP | 2 | 296-1612-5-ND
Micro SD Card | SanDisk Ultra 32GB UHS-I Class 10 microSDHC Card | 1 | https://www.amazon.com/SanDisk-Ultra-SDSQUNS-032G-GN3MN-UHS-I-microSDHC/dp/B074B28H3S
USB to Ethernet Adapter | USB 2.0 to 10/100 Ethernet Network Adapter | 1 | https://www.amazon.com/gp/product/B00M77HLII/ref=ppx_yo_dt_b_search_asin_title?ie=UTF8&th=1

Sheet: PB16_Power_Inject_Bom
This BOM removes all the fuses and uses 2 pin headers for the pixel outputs. It assumes you will use separate fusing and power for the pixels.
Reference | Description | Quantity | Digi-Key Part Number
C1 | CAP ALUM 220UF 20% 50V RADIAL | 1 | P5183-ND
C2 | CAP ALUM 100UF 20% 16V RADIAL | 1 | 1189-1148-ND
C3-C8 | CAP CER 0.1UF 50V X7R RADIAL | 6 | 478-7336-1-ND
D2 | DIODE SCHOTTKY 100V 5A DO201AD | 1 | SB5100DICT-ND
D3 | DIODE ZENER 5.1V 5W AXIAL | 1 | 1N5338BRLGOSCT-ND
D4,D6 | LED GREEN DIFFUSED T-1 T/H | 2 | 754-1217-ND
F17 | FUSE BLOCK BLADE 500V 20A PCB | 1 | 36-3544-2-ND
F17 Fuse | FUSE AUTO 2A 32VDC BLADE MINI | 1 | F986-ND
F19 | PTC RESET FUSE 72V 500MA RADIAL | 1 | RXEF050-2HFCT-ND
J18 | 2 Circuit Barrier Block Screws Connector 9.50mm | 1 | ED2953-ND
J19 | CONN RCPT USB2.0 TYPEA 4POS VERT | 1 | WM8672-ND
J1-J16 | TERM BLOCK HDR 2POS VERT 3.5MM | 16 | 277-5733-ND
J1-J16 Pixel Plugs | TERM BLOCK PLUG 2POS STR 3.5MM | 16 | ED10554-ND
J20,J21 | CONN MOD JACK 8P8C VERT UNSHLD | 2 | AE10392-ND
J22 | TERM BLK 4POS SIDE ENTRY 5MM PCB | 1 | 277-1238-ND
J23,J29 | CONN HEADER VERT 3POS 2.54MM | 1 | 732-5316-ND
J24 | CONN HEADER VERT 40POS 2.54MM | 1 | S9175-ND
J25 | CONN HEADER VERT 5POS 2.54MM | 1 | 732-5318-ND
J26 | CONN HDR 4POS 0.1 TIN PCB | 1 | S7002-ND
J27 | CONN HEADER VERT 4POS 2.5MM | 1 | 455-2249-ND
J28 | TERM BLK 2P SIDE ENT 2.54MM PCB | 1 | A98333-ND
J23/J29 Power Jumper | CONN JUMPER SHORTING .100" GOLD | 2 | S9341-ND
R1,R2,R3 | RES 120 OHM 1/4W 5% AXIAL | 3 | CF14JT120RCT-ND
R5 | RES 1K OHM 1/4W 5% AXIAL | 2 | CF14JT1K00CT-ND
R6,R7 | RES 4.7K OHM 1/4W 5% AXIAL | 2 | CF14JT4K70
RN1-RN4 | RES ARRAY 4 RES 33 OHM 8SIP | 4 | 4608X-2-330LF-ND
RN1-RN4 Sockets | CONN SOCKET 8POS 0.1 GOLD PCB | 4 | 1212-1097-ND
SW1,SW2 | SWITCH SLIDE DPDT 300MA 6V | 2 | 401-2001-ND
SW4, SW5 | SWITCH TACTILE SPST-NO 0.05A 24V | 2 | 1825910-6
U1 P1 & P2 Headers | CONN HEADER VERT 36POS 2.54MM | 2 | 732-5309-ND
U1 P1 & P2 Sockets | CONN HDR 36POS 0.1 GOLD PCB | 2 | S7121-ND
‎U1-POCKETBEAGLE | POCKETBEAGLE OSD3358 EVAL BRD | 1 | POCKETBEAGLE-SC-569-ND
U2 | DC DC CONVERTER 5V 8W | 1 | 811-2196-5-ND
U3,U4 | IC TXRX NON-INVERT 5.5V 20DIP | 2 | 296-1612-5-ND
U3,U4 Sockets | CONN IC DIP SOCKET 20POS TIN | 2 | AE9998-ND
U5 | IC DRIVER 2/0 8DIP | 1 | 296-15059-5-ND
U5/U6 Socket | CONN IC DIP SOCKET 8POS TIN | 2 | AE9986-ND
U6 | IC EEPROM 256K I2C 1MHZ 8DIP | 1 | FT24C256A-UDR-B
Micro SD Card | SanDisk Ultra 32GB UHS-I Class 10 microSDHC Card | 1 | https://www.amazon.com/SanDisk-Ultra-SDSQUNS-032G-GN3MN-UHS-I-microSDHC/dp/B074B28H3S
USB to Ethernet Adapter | USB 2.0 to 10/100 Ethernet Network Adapter | 1 | https://www.amazon.com/gp/product/B00M77HLII/ref=ppx_yo_dt_b_search_asin_title?ie=UTF8&th=1
Optional Real Time Clock | PCF8523 REAL TIME CLOCK BOARD | 1 | 1528-1787-ND
Optional OLED Display | 0.96" I2C 128X64 OLED LCD Display | 1 | https://www.amazon.com/gp/product/B06XRBTBTB/ref=ppx_yo_dt_b_asin_title_o00_s00?ie=UTF8&psc=1

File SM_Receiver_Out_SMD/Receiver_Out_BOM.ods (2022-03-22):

Qty | Reference(s) | Value | Digi-Key_PN | LCSC_PN | MPN
2 | C1, C2 | 10uF | 490-5523-1-ND | C15850 | GRM21BR61E106KA73L
3 | C3, C4, C5 | 0.1uF | 1276-1935-2-ND | C14663 | CL10B104KB8NNWC
1 | D1 | B5819W | B5819W-TPMSCT-ND | C8598 | B5819W-TP
2 | D2, D4 | LEDs | 732-4984-1-ND | C2286 | 150080RS75000
4 | F1, F2, F3, F4 | 3544-2 | 36-3544-2-ND | C492610 | 3544-2
1 | J1-J4 | Strings | 277-5737-ND/ED10555-ND | C192778 | 1843619/OSTTJ0311530
1 | J1-J4 Plug | Strings Plugs | ED10555-ND |  | OSTTJ0311530
1 | J5 | OLED | S7002-ND | C225501 | PPTC041LFBN-RC
2 | J6,J9 | VIN_Voltage/Debug | 732-5316-ND | C49257 | 61300311121
1 | J6 Jumper | Power Jumper | S9341-ND |  | NPC02SXON-RC
2 | J7, J8 | RJ45 | AE10392-ND | C305972 | A-2014-2-4-R
1 | J10 | SWD | 732-5315-ND | C492401 | 61300211121
1 | R1 | 1K | 311-1.00KHRCT-ND | C21190 | RC0603FR-071KL
1 | R2 | 100K | YAG1235CT-ND | C25803 | RT0603BRD07100KL
4 | R3, R4, R5, R6 | 120 | A129677CT-ND | C22787 | CRGCQ0603F120R
4 | R7, R8, R9, R10 | 33ohm | 311-33GRCT-ND | C23140 | RC0603JR-0733RL
1 | R11 | 220 | RMCF0603FT220RTR-ND | C22962 | RMCF0603FT220R
1 | SW1 | ID | 563-1069-ND | C457921 | SD-2010
1 | SW2 | Terminators | 2223-DS04-254-1L-04BK-ND | C509571 | DS04-254-1L-04BK
2 | SW3-SW4 | User/RUN | CKN9088CT-ND | C127509 | PTS645SL50SMTR92 LFS
1 | TB1 | Power In | A98472-ND | C306200 | 4DB-P108-02
4 | U1, U4, U5, U6 | 74AHCT1G125 | 74AHCT1G125W5-7DICT-ND | C7484 | 74AHCT1G125W5-7
1 | U2 | AMS1117-5.0 | 488-LM1117MPX-50NOPBCT-ND | C6187 | LM1117MPX-50NOPB
1 | U3 | AM26C32IN | 296-37322-1-ND | C6180 | AM26C32INSR
1 | U7 | Pico | SC0915 |  | 2648-SC0915CT-ND

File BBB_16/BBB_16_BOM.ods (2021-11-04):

Reference | Description | Quantity | Digi-Key Part Number
C1 | CAP ALUM 220UF 20% 50V RADIAL | 1 | P5183-ND
C2 | CAP ALUM 100UF 20% 16V RADIAL | 1 | 1189-1148-ND
C3-C7 | CAP CER 0.1UF 50V X7R RADIAL | 5 | 478-7336-1-ND
D1,D2 | DIODE SCHOTTKY 100V 5A DO201AD | 2 | SB5100DICT-ND
D3 | DIODE ZENER 5.1V 5W AXIAL | 1 | 1N5338BRLGOSCT-ND
D4,D5,D6 | LED GREEN DIFFUSED T-1 T/H | 3 | 754-1217-ND
F17 Fuse | FUSE AUTO 2A 32VDC BLADE MINI | 1 | F986-ND
F1-F16, F18 Fuses | FUSE AUTO 5A 32VDC BLADE MINI | 17 | F989-ND
F1-F18 | FUSE BLOCK BLADE 500V 20A PCB | 18 | 36-3544-2-ND
J17,J18 | CONN BARRIER STRIP 2CIRC 0.374" | 2 | ED2953-ND
J1-J16 | TERM BLOCK HDR 3POS VERT 3.5MM | 16 | 277-5737-ND
J1-J16 Pixel Plugs | TERM BLOCK PLUG 3POS STR 3.5MM | 16 | ED10555-ND
J19 | CONN HEADER VERT 4POS 2.5MM | 1 | 455-2249-ND
J20,J21 | CONN MOD JACK 8P8C VERT UNSHLD | 2 | AE10392-ND
J22 | TERM BLK 4POS SIDE ENTRY 5MM PCB | 1 | 277-1238-ND
J23,J28 | CONN HEADER VERT 3POS 2.54MM | 2 | 732-5316-ND
J24 | CONN HEADER VERT 24POS 2.54MM | 1 | ED10525-ND
J25 | CONN HEADER VERT 5POS 2.54MM | 1 | 732-5318-ND
J26 | CONN HDR 4POS 0.1 TIN PCB | 1 | S7002-ND
J27 | TERM BLK 2POS SIDE ENTRY 3.81MM PCB | 1 | 277-1947-ND
J23/J28 Power Jumper | CONN JUMPER SHORTING .100" GOLD | 2 | S9341-ND
R1,R2,R3 | RES 120 OHM 1/4W 5% AXIAL | 3 | CF14JT120RCT-ND
R4,R5 | RES 1K OHM 1/4W 5% AXIAL | 2 | CF14JT1K00CT-ND
R6,R7 | RES 4.7K OHM 1/4W 5% AXIAL | 2 | CF14JT4K70CT-ND‎
R8, R11 | RES 100 OHM 1/4W 5% AXIAL | 2 | CF14JT100RCT-ND
R9, R12 | RES 10K OHM 1/4W 1% AXIAL | 2 | RNF14FTD10K0CT-ND
R10, R13 | RES 680 OHM 1/4W 1% AXIAL | 2 | MFR-25FBF52-680R-ND
RN1-RN4 | RES ARRAY 4 RES 33 OHM 8SIP | 4 | 4608X-2-330LF-ND
RN5 | RES ARRAY 4 RES 120 OHM 8SIP | 1 | 4608X-2-121LF-ND
RN1-RN5 Sockets | CONN SOCKET 8POS 0.1 GOLD PCB | 5 | 1212-1097-ND
SW1-SW5 | SWITCH TACTILE SPST-NO 0.05A 24V | 5 | 1825910-6
SW6 | SWITCH SLIDE DPDT 300MA 6V | 1 | 401-2001-ND
U1 P1 & P2 Headers | CONN HEADER VERT46POS 2.54MM | 2 | S2012EC-23-ND
‎U1-BEAGLEBONE | BEAGLEBONE BLK REV C AM3358BZCZ | 1 | BBB01-SC-505-ND
U2 | DC DC CONVERTER 5V 8W | 1 | 811-2196-5-ND
U3,U4 | IC TXRX NON-INVERT 5.5V 20DIP | 2 | 296-1612-5-ND
U3,U4 Sockets | CONN IC DIP SOCKET 20POS TIN | 2 | AE9998-ND
U5 | IC DRIVER 2/0 8DIP | 1 | 296-15059-5-ND
U5,U6 Socket | CONN IC DIP SOCKET 8POS TIN | 2 | AE9986-ND
U6 | IC EEPROM 256K I2C 1MHZ 8DIP | 1 | FT24C256A-UDR-B
U7 | IC DRIVER 4/0 16DIP | 1 | 296-6785-5-ND
U7 Socket | CONN IC DIP SOCKET 16POS TIN | 1 | AE9992-ND
Micro SD Card | SanDisk Ultra 32GB UHS-I Class 10 microSDHC Card | 1 | https://www.amazon.com/SanDisk-Ultra-SDSQUNS-032G-GN3MN-UHS-I-microSDHC/dp/B074B28H3S
Optional OLED Display | 0.96" I2C 128X64 OLED LCD Display | 1 | https://www.amazon.com/gp/product/B06XRBTBTB/ref=ppx_yo_dt_b_asin_title_o00_s00?ie=UTF8&psc=1
Optional Real Time Clock | PCF8523 REAL TIME CLOCK BOARD | 1 | 1528-1787-ND

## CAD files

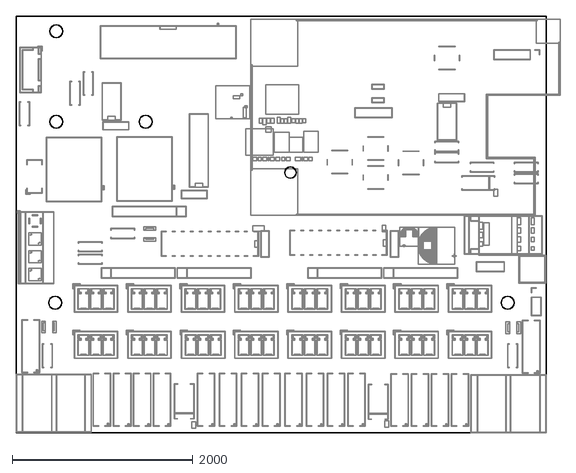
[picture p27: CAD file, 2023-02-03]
BBB_16/BBB_16.dxf
6011.6 x 4605.0

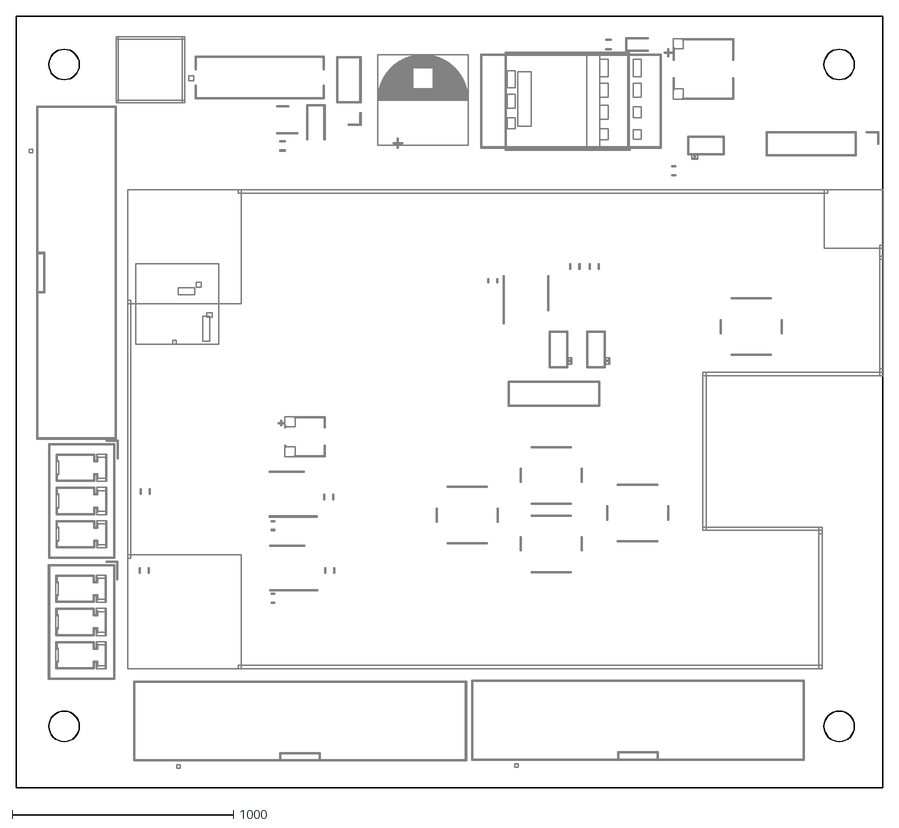
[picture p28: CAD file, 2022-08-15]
BBB_16_Expansion/BBB_16_Expansion.dxf
3919.4 x 3486.2

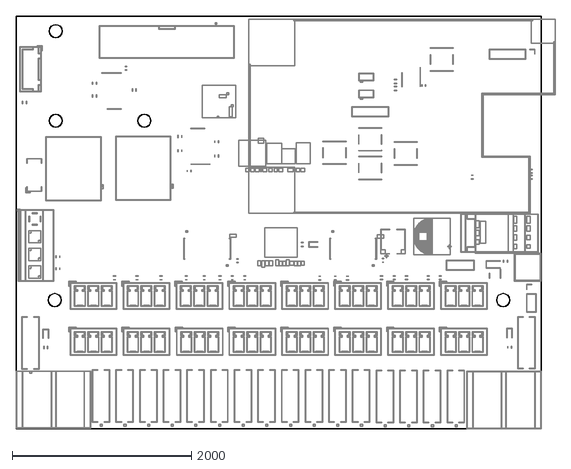
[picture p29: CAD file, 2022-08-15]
BBB_16_SMD/BBB_16.dxf
6011.6 x 4605.0

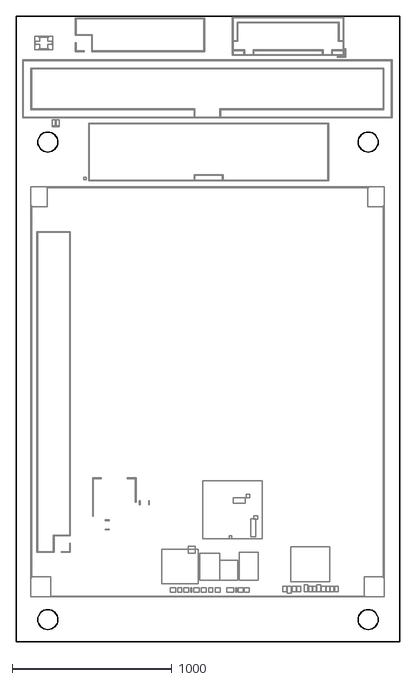
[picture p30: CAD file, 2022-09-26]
Input_Adapter/Input_Adapter.dxf
2405.5 x 3921.3

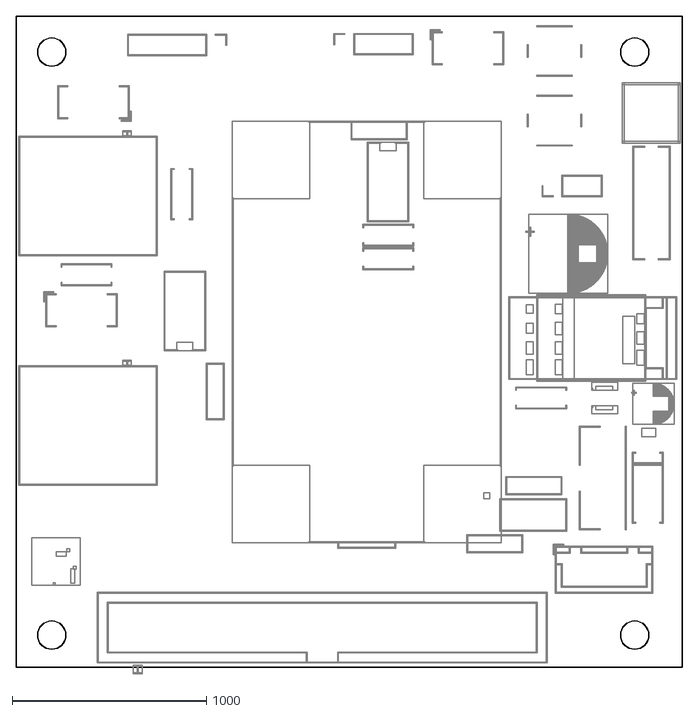
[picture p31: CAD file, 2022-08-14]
PB_16_Mini/PB_16.dxf
3427.2 x 3381.8

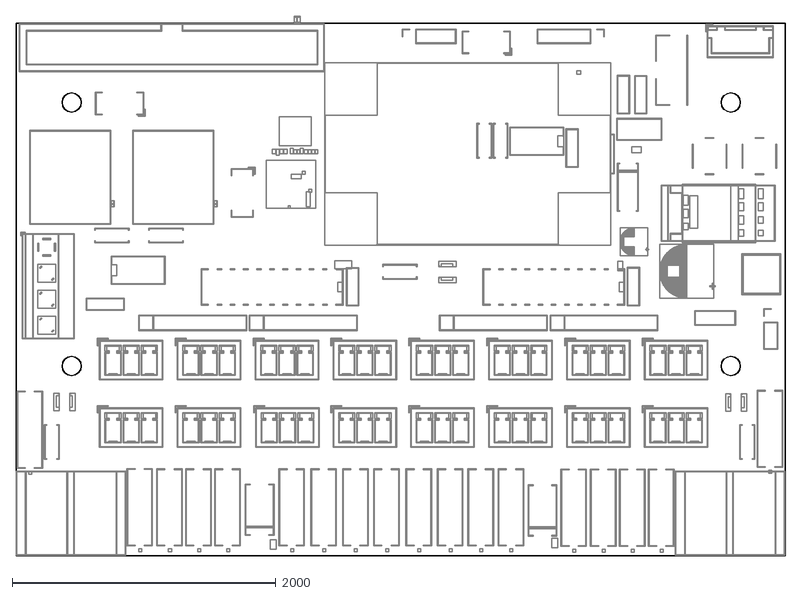
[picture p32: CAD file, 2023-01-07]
PB_16v1/PB_16.dxf
5833.9 x 4090.2

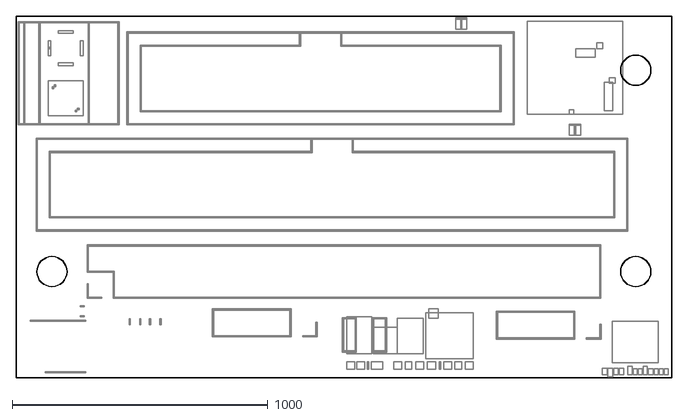
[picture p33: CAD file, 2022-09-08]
Pi_Adapter/Pi_Adapter.dxf
2562.6 x 1413.4

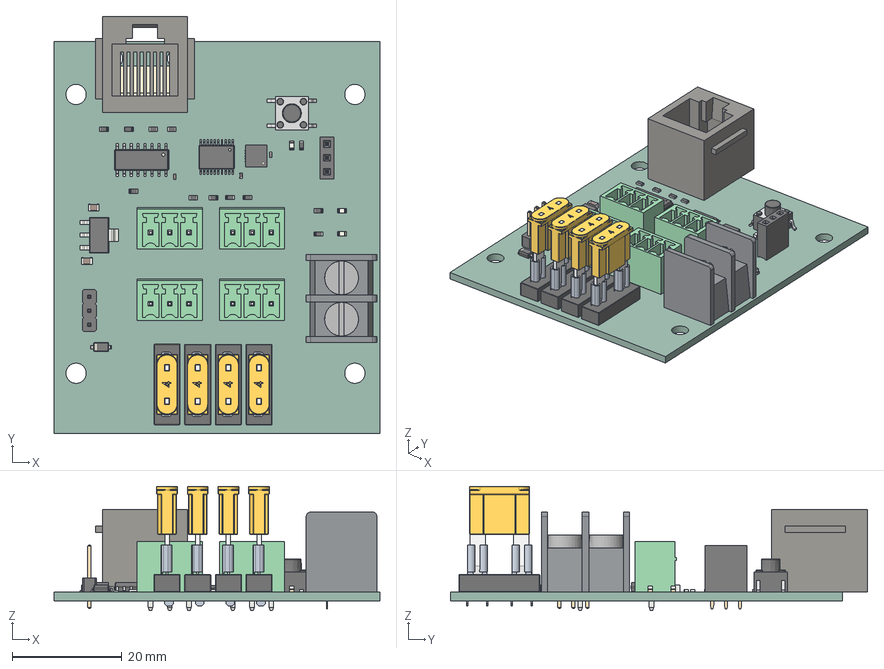
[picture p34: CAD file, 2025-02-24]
Receiver_Out_SMD/Receiver_Out.step
59.3 x 76.0 x 22.6 mm
MCV_01x03_G_3_5mm x 4
Fuse Holder Mini Blade v1 x 4
C_0805_2012Metric x 2
PinHeader_1x03_P254mm_Vertical
R_0603_1608Metric x 12
LED_0603_1608Metric x 3
SOIC_16_39x99mm_P127mm
C_0402_1005Metric x 3
D_SOD_123
SOT_223
TSSOP_20_44x65mm_P065mm
PinSocket_1x03_P2.54mm_Vertical
Tactal Switch - SMD (6mmx 6mmx__mm) - Marked
UQFN-20-1EP_4x4mm_Pitch0.5mm
Receiver_Out_PCB

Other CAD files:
Receiver_Out_SMD/Receiver_Out.dxf

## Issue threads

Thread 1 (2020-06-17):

PB_16 Voltage Regular

libby2cm, 2020-06-17:
Hi, it looks like at one point this board used a buck converter, but now uses a LM7805.  Is that on purpose, or were there issues with the buck?  If the 7805 is right, does it need a heatsink or anything?

computergeek1507, 2020-06-17:
You should use a OKI-78SR-5 buck converter. The Kicad 3D renders show a 7805 because I have not made a 3D model for the OKI-78SR-5 buck converter. The BOM also has a  OKI-78SR-5 buck converter.

libby2cm, 2020-06-17:
Ah, got it.. missed it in BOM.  Just sending boards out to fab, so wanted to double check.. thanks!

libby2cm, 2020-06-17:
Just a heads up, looks like it's in digikey library now, with 3d model (horizontal & vertical)

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

computergeek1507, 2020-06-17:
Do I also see the polifuse 3d model as well in your screenshot?

libby2cm, 2020-06-18:
> Do I also see the polifuse 3d model as well in your screenshot?

Yes, I didn't change anything from your last commit though, so new version of kicad must have included new libraries/models.

Closed 2020-06-17.

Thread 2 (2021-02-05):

Mosfet switch on ports

sslupsky, 2021-02-05:
Due to the safety issues with pixels, I wonder if it would be a good idea to put a mosfet on each port so they can be shut down?  The mosfets could have a common gate signal.  When the show is over, FPP could turn off the power to the pixels.

Kosh42, 2021-02-05:
I'd argue the "safety issue" is to do with cheapest price point pixels rather than quality pixels, but argument for another day.

In this case I believe that if you want to shut down the pixels side, but keep the controller live, you'd power it from aux with a 5V input, them just shut down the pixel PSU feeding the main port inputs.

It's how I plan to do it, from a safety and efficiency point of view.

sslupsky, 2021-02-05:
Agreed.  Race to the bottom and we are not in control of the design of the pixels so the suppliers make crazy mistakes.  It would be nice to control the power to the pixels from FPP.  This would provide people that want to have permanent lights a bit of a better safety margin.  It would also give Scott's design an additional feature the other controllers do not have.  If people are concerned about the cost of adding the extra fets, we could add some 0 ohm resistors to bypass them and allow people to build without the fets.

processor83, 2021-03-31:
im sure its possible alredy to control a relay with some GPIO to turn on or off the power supply source. If using hp power supply you can take adventage of the standby 5V and the enable pin... for meanwell power supply you can have a 5V power supply and control a contactor to turn on off the AC source or even control a smart plug so i dont see any need to make huge modification to the controller here.

sslupsky, 2021-04-01:
But that solution requires two power supplies.  One to run the board and another for the pixels.  The better solution is to have the control on the controller.  A TI eFuse costs less than $0.50, are UL/CSA listed and provides an electronically resettable output.  So, you can get rid of the thermal fuses and fuse holders and the cost of those components.

processor83, 2021-04-02:
Do you have the part number? How may gpio it would need to control all those fuses?

sslupsky, 2021-04-02:
TPS2595, TPS25947, TPS25980 are some parts I think would work for this application.  You could connect the EN pin of all the fuses together and use one GPIO to turn them on/off.  If you want to control them all individually, you would require one GPIO per fuse.  Or, use an I2C port expander and drive the EN pins from that and use the I2C bus.

sslupsky, 2021-04-02:
Note, the max current of the TPS2595 is 4A.  All pixel strings sold these days come with 22 AWG wire so the current limit of an output port should be limited to the wire capacity which is 3A for 22 AWG wire.  Thus the TPS2595 would be suitable.

ptr727, 2021-12-23:
FET's switching the DC output sounds like an interesting idea, I was considering relays or SSR's in front of the PSU's.
I'm contemplating building a DIN enclosure next season, AC breaker, 5V DIN PSU for controller, and multiple 10A (12V, 24V, 48V) DIN PSU's per light group, maybe 2 to 4 outputs per PSU, resettable fuses, I2C INA236 / ACS712 current monitoring, dedicated injection outputs running 24/48V DC-DC 12V at end of long runs.

processor83, 2022-10-15:
i made some test with HP server power supply they have 12 stanby power and i used a mini buck converter and feed the beaglebone from this all the time and a gpio at the begening of the schedule to turn on the power supply and turn off at the end of the show i used opto coupler to protect the gpio it work pretty good and need only one psu...

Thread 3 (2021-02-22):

Flash bin to ROM

Kosh42, 2021-02-22:
HI,

I've manager to create my own bin file for the BBB16 v2, but the PB16 files say to go to Help > About, then "Scroll to Cape/Hat Firmware Upgrade". I have no such option when I upload this to the FPP instance, only a section called "About Cape/Hat" on that page.

I know the bin is valid as placing in it /opt/fpp-vendor/cape-eeprom.bin works as expected. This is of course putting my own public key in /opt/fpp/scripts/keys/ to match the one used when generating the bin, as without that I can't even get to this far.

I have tried the old FPP way with a sudo cp to the eeprom but this again doesn't work. When I nano this though I do see it still reports all the "filler" data in the unused end of the EEPROM.

Running `sudo journalctl -u fppcapedetect` gives me:

```-- Logs begin at Thu 2019-02-14 10:12:00 UTC, end at Mon 2021-02-22 20:45:54 UTC. --
Feb 14 10:12:03 FPP systemd[1]: Starting FPP Cape Detection...
Feb 14 10:12:03 FPP detect_cape[163]: Running detect_cape
Feb 14 10:12:04 FPP detect_cape[163]: Running fppcapedetect
Feb 14 10:12:08 FPP detect_cape[163]: Did not find 0x50 on i2c2, trying i2c1.
Feb 14 10:12:08 FPP detect_cape[163]: Did not find eeprom on i2c.
Feb 14 10:12:08 FPP detect_cape[163]: EEPROM file doesn't exist .
Feb 14 10:12:08 FPP detect_cape[163]: Using /opt/fpp-vendor/cape-eeprom.bin
Feb 14 10:12:08 FPP detect_cape[163]: Found cape BBB16, Version v2, Serial Number: 12345
Feb 14 10:12:08 FPP detect_cape[163]: Done fppcapedetect
Feb 14 10:12:09 FPP detect_cape[163]: Done
Feb 14 10:12:09 FPP systemd[1]: fppcapedetect.service: Succeeded.
Feb 14 10:12:09 FPP systemd[1]: Started FPP Cape Detection.
```

When I try this on a fresh fpp without the public key I get:
```-- Logs begin at Thu 2019-02-14 10:12:00 UTC, end at Mon 2021-02-22 21:03:40 UTC. --
Feb 14 10:12:03 FPP systemd[1]: Starting FPP Cape Detection...
Feb 14 10:12:03 FPP detect_cape[168]: Running detect_cape
Feb 14 10:12:04 FPP detect_cape[168]: Running fppcapedetect
Feb 14 10:12:05 FPP detect_cape[168]: Did not find 0x50 on i2c2, trying i2c1.
Feb 14 10:12:05 FPP detect_cape[168]: Did not find eeprom on i2c.
Feb 14 10:12:05 FPP detect_cape[168]: EEPROM file doesn't exist .
Feb 14 10:12:05 FPP detect_cape[168]: Could not detect any cape
Feb 14 10:12:05 FPP detect_cape[168]: Done fppcapedetect
Feb 14 10:12:06 FPP detect_cape[168]: Done
Feb 14 10:12:06 FPP systemd[1]: fppcapedetect.service: Succeeded.
Feb 14 10:12:06 FPP systemd[1]: Started FPP Cape Detection.
```

Any thoughts welcomed, and apologies if me trying to hash this together I've made some schoolboy error.

Many thanks,

Tim

computergeek1507, 2021-02-26:
Try flashing this file and let me know if it works
[BBB16-eeprom.zip](https://github.com/computergeek1507/PB_16/files/6047540/BBB16-eeprom.zip)

ukdel, 2021-03-11:
hi
I am doing  a similar thing to Tim and I did load your BBB16-EEprom file and seemed to work a treat (I still have to run it with full pixels connected). The only additional issue is that I am running one of your multi expansion board  from the main BBB16. It does allow for an expansion card, and includes for differential or standard ports, but not a mix of the two. Do you have a solution for this yet? Many Thanks
D

computergeek1507, 2021-03-12:
From a configuration standpoint the only difference between a differential or standard ports is the ability to setup smart receivers. For FPP the pixel data output is basically the same. For the multi expansion just use the differential expansion option. The first two groupings(8 ports) are the local standard ports and the last two groupings are the diff receiver ports.

Kosh42, 2021-03-13:
Many thanks for your work on this. Not sure where else to post this without bugging you, but any chance I can have a look at the files you created the bin from for learning purposes? I've created them for a different thing I'm working on and they are not quite working as expected (many the control buttons).

ukdel, 2021-03-13:
Hi kosh..

Scott produced the files.. and also produced the changes in xlight. He is a star.

I got it all working with hi s files.

Derek

..on the move

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

Closed 2021-04-18.

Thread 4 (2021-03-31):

Smart receiver documentation?

processor83, 2021-03-31:
Hello, i see you work on a smart receiver 3 in 1. Do you have any documentation you can share so i can learn how they send information about the receiver ID to the smart receiver. I have read FPP source code but its not 100% clear to me!  I want to try learning AVR and do it with attiny one my side.

Thank you for your help!

Kosh42, 2021-03-31:
Looking at a commercial differential board, I noted an ATTiny chip on it I think. As my coding is so bad, I gave up trying to reverse engineer it further from that point. Where did you see that Scott was working on a differential board?

processor83, 2021-03-31:
I also try to replicate those smart receiver you talk about.  When i see something i always want to learn how it work and build it! Very steap learning curve for me learning PCB design shematics  and now try to add prog to it all! Im far from anything working. What i know is that it can be done with Attiny416 and that it have to read the receiver id in the data stream and this will turn on and off a switch inside the attiny416 to allow data or not to the 4 pixels ports based of receiver ID.

I looked at falcon pi mplayer source files since it is used on kilp board and i kind of understand that is pull the data pin low to tell the attiny416 to listed for ID then send the id and then return to led data mode. It do this super fast to turn the switches on and off on the smart receivers.

Maybe it would be easy to see on a scope. I also asked Daniel Kulp about it since he is the one that found it and added this to fpp.

You can look at  smart_receiver_max folders in this repo for this project. Its exactly 3 bank of 4 so i guessed it must be compatible with falcon kulp but i also see a the smart_receiver_max_out so maybe he work on is own way of doing it and will break out 12 full ports over one signle cable.

processor83, 2021-03-31:
Ok i will write it there since i just thinked of something and i guess its would be the way they do it. strop led data on the 4 pins use those 4 data pins in high or low state to comunicate the id and resume led data it make sense for pi gpio pin high or low its like those 4 dip switches on the receiver ... so simple now thta i think about it  and im 80% sure its like this was thinking they where addind packed to the ws2811 stream but attiny416 is too slow to decode all this data real time.

processor83, 2021-03-31:
Ok afther making some more thinking its like this but each port are individual and the id is send  individually to each ports.

computergeek1507, 2021-04-01:
There is no real documentation, but here is a screenshot of the data from my logic analyzer.

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

processor83, 2021-04-01:
Thank you for this it will help us!
Can i assume this.
180ms low to tell the ic to listen for id.
180ms port number high to tell the id to the smart receiver
180ms low to return to pixel data mode.

Now to start to play with this info :)
Thank you again!

computergeek1507, 2021-04-01:
the data is not high for 180us it is toggling at 800khz.

processor83, 2021-04-01:
ok so its like they are sending 100% white if i unserstand correctly from the source code of fpp.

Thank you.

ninjinja, 2023-07-04:
Is there firmware available for the smart receiver designs, and are you willing to share the source code?   Thanks

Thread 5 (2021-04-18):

Issue with DMX working on BBB16 V2 Board

ukdel, 2021-04-18:
HI Scott. I have been trying to get the DMX working on the BBB16 V2 board to no avail. I am using a 12 Ch DMX decoder wired to the screw terminals at DMX2. I have check that switched to DMX and configuration is correct in FPP (Ports active and out from ttyS2) . I have even checked that the decoder is good using a separate USB/DMX dongle.
With a simple DIY tester there doesnt appear to be a good DMX signal at the terminals or at the RJ45 sockets (tried them both...)
I have tried everything I could think of but am now stumped.

Note although i am using V2 board, I have done the changes to the GPIO port and ENter/Down buttons which worked, and the  rest of board seems to work well. Just the DMX to figure out. Any suggestions?

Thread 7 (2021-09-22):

bbb 16

djravi, 2021-09-22:
bbb16 new board EEPROM file is old when update new files

computergeek1507, 2021-11-06:
I added a new eeprom file for the v2 I am still testing if it works correctly

Closed 2022-08-15.

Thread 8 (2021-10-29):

BBB16 v2.0

Mariio82, 2021-10-29:
Good morning
I have a question regarding your driver I made it is BBB-16 v2.0
but I have a problem at output 14 not working,
Buttons do not work.

The rest of the ports work but are swapped, the descriptions do not match.
It is possible to change the Bin file because it has been to version 1.0

Closed 2021-11-04.

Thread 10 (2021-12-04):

Pull Requests

sslupsky, 2021-12-04:
@computergeek1507 Are you taking pull requests?  I've made a SMT version of the BBB-16 and had JLCPCB assemble it.  The board can now be completely assembled by JLCPCB including the through hole parts.  The only part JLCPCB will not currently assemble are the two headers for the BBB because it must be mounted on the bottom side of the board.  JLCPCB support assembly on only one side.

computergeek1507, 2021-12-04:
My only request is that it's licenced under an open source hardware license, so myself or others can use it and modify it.

sslupsky, 2021-12-05:
Sure, that's not a problem.  Should I submit it as a commit to BBB 16 or rename it something like BBB 16-SMT?

computergeek1507, 2021-12-08:
BBB 16-SMT or BBB 16-SMD is fine with me

ptr727, 2021-12-23:
@sslupsky that sounds cool, can't wait to see it!

ptr727, 2022-01-20:
Hi @sslupsky are you still planning on a PR here, if not, would you share your project publicly?

computergeek1507, 2022-01-20:
I was wondering as well, if not I will start one

sslupsky, 2022-01-21:
@ptr727 Yes.  Apologies for taking a while.  I was doing some clean up, then KiCad updates and then got distracted with some sequencing.  I'll get back to this soon.

@computergeek1507 One design change I have been contemplating is to implement a switch on the port power outputs.  Is there a spare GPIO that can be used for this purpose?  If not, I could use an I2C port expander to add the additional GPIO.  The switches also have a current sense so it would also possible to monitor current on each port.  Do you think the current monitor would be useful?  Can these control elements be integrated into FPP?

ptr727, 2022-01-21:
+1 for output switch and current monitor (e.g. TI TPS).
I'd like to run electronics powered 24/7, but power up the LED power only when in use (permanent install safety and power savings).
I'd also like to experiment and drive output by current limit threshold vs. % power setting trying to get output max below fuse rating (resettable fuse?).
Don't know what V ratings for FET/switch you're looking at, but another thing I'd like to try is running output at 24V/48V (lots of newer datacenter gear running 48V DC, hoping it brings prices down for DIN mount PSU's), and then a 24V-48V DC -> 12V DC per string section.
Talking about PSU, rather than big single PSU, want to run n-outputs per DIN mount PSU, e.g. modular 2/4/8-outputs per PSU, and same outputs could be used for power injection still with current monitoring / limiting.
Anyway, lots of things one could do, just need time ;)

sslupsky, 2022-01-21:
The component that I was considering for this is the TPS2597xx.  It has the switch and built in current monitor as well as a current limited output.  So, we can eliminate the fuses.  Probably should add some LED's.  Recommended max input voltage is 23V for this part.  It rated up to 7A.

ptr727, 2022-01-21:
The TPS1HB08-Q1 is 8mR 40V, so safe for 24V, there are others in the automotive high side switch series.
https://www.ti.com/power-management/power-switches/high-side-switches/products.html

For 48V not so easy, even the INA3221 is 26V, and then need a FET, but it is a 3x channel with 4x selectable I2C address, so 12 outputs per I2C bus without a multiplexor.

But this is just browsing, no idea what is available at JLC for manufacturing.

sslupsky, 2022-01-24:
@computergeek1507 I am preparing the BBB_16_SMD PR and had a question about the organization of the repo.  I've been wondering if each board shoud tracked separately?  The way it is now, commits are interspersed among the individual boards (projects).  As I understand there are two approaches to doing so, using a submodule or a subtree.  Let me know what you think.

WaldoWood, 2022-02-09:
@computergeek1507 Pull requests? Hi, I've made a modified version of the BBB-16 to fit my own expansion boards, as I don't want to use Holiday Coro Flex Boards. Would it be ok to use your BB16-Flex-eeprom?

ptr727, 2022-05-07:
@sslupsky any progress on switchable outputs on a JLC buildable SMD board?

sslupsky, 2022-05-08:
The design is complete.  I am waiting for the switch to come in stock and then I should be able to order some prototypes from JLC.  You can switch the outputs in banks of 8 ports (so, two banks).  You can monitor the load current on any output.

Design enhancements include an RTC and battery, audio DAC, speaker amplifier and FM transmitter.  I also changed the DMX RJ45 to a diff port and moved the DMX port to the DMX terminal block which is now six pins.

Also, the power path is now jumperless and auto configures itself based on the power input connections.

sslupsky, 2022-05-08:
Here is a render of the pcb
blob:null/47971c57-c64c-4068-a306-0a56421b17fc

ptr727, 2022-07-16:
I see that ExperienceLights announced their new Genius controllers have auto resettable polyfuses and current monitoring, they posted a video demoing on the XLights FB group; using current monitoring to good use doing auto pixel counting and pixel fault testing.

sslupsky, 2022-07-16:
Yes, using the current monitor, you could detect stuck pixels and dead pixels.  I am still waiting for the parts to become available.  Should be soon.

ptr727, 2022-11-02:
@sslupsky any update on publishing your design?

kingofkristmas, 2022-12-23:
> Yes, using the current monitor, you could detect stuck pixels and dead pixels. I am still waiting for the parts to become available. Should be soon.

Excited and waiting to see what you come up with!

sslupsky, 2022-12-23:
I think I have found a substitute for one of the parts that will allow me to build a few of these.  I am looking into a couple of the other parts that have disappeared from distribution now.  Hopefully, early in the new year I will be able to build one.

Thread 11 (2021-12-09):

FPP reports abnormal condition:  Could not not initialize output type BBB48String

sslupsky, 2021-12-09:
I have an issue where FPP is reporting an abnormal condition.  I am using the BBB16 and I believe this problem began when I flashed the BBB16v2-eeprom.bin file but that might just be coincidental.  The eeprom appears to have been flashed but I did not notice a message indicating the flashing was complete when I performed the flash.

The first few bytes of the eeprom appear to be programmed correctly but I cannot be certain because I do not know what information is stored in this file and the file format.  But, it clearly indicates "BBB16v2":
```
FPP02BBB16v22.02111032347063497cs 18982tmp/cape-info.tgz?\?S?8?5?+4~??*?_I?.????s?N??Q?[cgl%@????l+?`sW??P7Z}?vW?]??u?d????$
```

xLights appears to upload the output configuration.  I see the "FPP output upload complete" message in the bottom left corner.  Note however that xLights does not have an option for "BBB16v2".  The only option is "BBB16".

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

When I inspect the output configuration in FPP, it appears to be correct.

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

When I inspect fppd.log I can see a couple ChannelOut messages:

```
2021-12-09 10:13:49.669 (2365) [ChannelOut] /opt/fpp/src/channeloutput/BBB48String.cpp:293: No output pin configuration for BBB16
2021-12-09 10:13:49.671 (2365) [ChannelOut] /opt/fpp/src/channeloutput/channeloutput.cpp:395: Determined range needed 0 - 7
```

I notice the ChannelOut message refers to BBB16 but the output configuration in FPP shows the device as BBB16v2.  I am not sure if this is relevant or an indication that ChannelOut thinks this is an older version of the board.

Not sure if this is an FPP issue or xLights issue or related to the eeprom configuration.

FPP version is 5.4.1
xLights version is 2021.39

At the moment, I do not have the OLED or RTC installed.

computergeek1507, 2021-12-09:
xLights is setting the wrong controller type in the FPP bbb-strings JSON file. I will have to update xLights

sslupsky, 2021-12-09:
Yeah, that is the problem.  Here is the relevant part of co-bbbStrings.json:

```
            "subType": "BBB16",
            "pinoutVersion": "1.x",
            "type": "BBB48String",
            "startChannel": 1,
            "channelCount": -1,
            "enabled": 1
```

I changed it to "BBB16v2" and the abnormal condition appears to be resolved.  The fppd.log file now shows that ChannelOutput is loading the output configuration properly:
```
2021-12-09 11:05:23.830 (5579) [ChannelOut] /opt/fpp/src/channeloutput/channeloutput.cpp:356: BBB48String 0:  Determined range needed 30240 - 30539
2021-12-09 11:05:23.833 (5579) [ChannelOut] /opt/fpp/src/channeloutput/channeloutput.cpp:356: BBB48String 0:  Determined range needed 30540 - 30839
2021-12-09 11:05:23.833 (5579) [ChannelOut] /opt/fpp/src/channeloutput/channeloutput.cpp:356: BBB48String 0:  Determined range needed 30840 - 31139
2021-12-09 11:05:23.833 (5579) [ChannelOut] /opt/fpp/src/channeloutput/channeloutput.cpp:356: BBB48String 0:  Determined range needed 31140 - 31439
2021-12-09 11:05:23.833 (5579) [ChannelOut] /opt/fpp/src/channeloutput/channeloutput.cpp:356: BBB48String 0:  Determined range needed 31440 - 31739
2021-12-09 11:05:23.834 (5579) [ChannelOut] /opt/fpp/src/channeloutput/channeloutput.cpp:356: BBB48String 0:  Determined range needed 31740 - 32039
2021-12-09 11:05:23.834 (5579) [ChannelOut] /opt/fpp/src/channeloutput/channeloutput.cpp:356: BBB48String 0:  Determined range needed 32040 - 32339
2021-12-09 11:05:23.834 (5579) [ChannelOut] /opt/fpp/src/channeloutput/channeloutput.cpp:356: BBB48String 0:  Determined range needed 32340 - 32639
2021-12-09 11:05:23.834 (5579) [ChannelOut] /opt/fpp/src/channeloutput/channeloutput.cpp:356: BBB48String 0:  Determined range needed 32640 - 32939
2021-12-09 11:05:23.835 (5579) [ChannelOut] /opt/fpp/src/channeloutput/channeloutput.cpp:395: Determined range needed 30240 - 32939
```

sslupsky, 2021-12-09:
As a workaround, I will disable automatic upload of the output configuration in xLights.  I won't be needing to update the configuration very often so I can do a manual update and go in a make the change manually until xLights is updated.

I'll leave this issue open until xLights is updated.

computergeek1507, 2021-12-09:
I could make a new epprom that has the same id as well

sslupsky, 2021-12-09:
I do not intend to change the output configuration at this point.

Unless there is a preference to use the old ID it is probably ok to leave it as it is and I will just make the change manually.

computergeek1507, 2021-12-09:
I think it's is the reason for the pinout version field but the issue I have is I added 4 more ports so xLights has to have multiple configurations too

sslupsky, 2021-12-12:
Yeah, I noticed today that ports 17 to 20 do not appear in the xLights visualizer so I am not able to assign a model to those ports.  Can I manually assign the port in the layout editor?

sslupsky, 2021-12-12:
So I manually edited fpp.xcontroller in the app bundle and added a BBBv2 controller definition to xLights.  This solved the problem and also solved the upload issue.

```
    <Controller Name="BBB16v2">
        <Variant Name="No Expansion" ID="BBB16v2" Base="FPP:FPPStringCapeTTYs">
            <MaxPixelPort>20</MaxPixelPort>
            <MaxSerialPort>2</MaxSerialPort>
            <fpp>1</fpp>
            <fpp1>21,-1</fpp1>
            <fppSerialPort1>ttyS1</fppSerialPort1>
            <fppSerialPort2>ttyS2</fppSerialPort2>
        </Variant>
        <Variant Name="w/Expansion" ID="BBB16v2" Base="FPP:FPPStringCapeTTYs">
            <MaxPixelPort>36</MaxPixelPort>
            <MaxSerialPort>2</MaxSerialPort>
            <fpp>1</fpp>
            <fpp1>21,16</fpp1>
            <fppSerialPort1>ttyS1</fppSerialPort1>
            <fppSerialPort2>ttyS2</fppSerialPort2>
        </Variant>
    </Controller>
```

sslupsky, 2021-12-21:
Created PR in xLights:  https://github.com/smeighan/xLights/pull/3025

Closed 2021-12-21.

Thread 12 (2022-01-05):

Missing positions CSV files

MKansagra, 2022-01-05:
I'm following the ordering instructions but I can't seem to find the positions CSV file.
I'm just ordering the PB16 version and nothing fancy.

Am I looking in the wrong place?

computergeek1507, 2022-01-05:
The PB16 is through hole and cannot be assembled by JLC so no position file is needed

MKansagra, 2022-01-05:
Ahh so if I'm not confusing myself here, I just order the PCB from JLC or whoever else and then use BOM to order the parts myself to assemble it at home?

I was following the ordering instructions which mentioned the positions files so I got confused by that.

Which boards require the positions file if I do need any expansion boards or such in the future?

computergeek1507, 2022-01-05:
Any of the PCBs with "SMD" have surface mount parts that can be assembled by JLC

MKansagra, 2022-01-05:
Wonderful! Thank you!

Can't wait to build the controller and try it.

Closed 2022-01-05.

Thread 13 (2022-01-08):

Diff Expansion v4 sock has wrong pinout

fone626, 2022-01-08:
Unfortunately I found this out the hard way.  The +5V and GND on the Diff_Expansion are reversed on pins 1,2 and 3,4 from what is on the BBB-16, 3to4_Adapter and the 16_Expansion.   I'm assuming the BBB-16, 3to4_Adapter and 16_Expansion have the correct pinout as that's what appears to be correct based on what little I can see from pictures of the falcon v4 expansion boards.

While researching this I also noticed the GND and +5V are reversed on the Four_Out Expansion.

computergeek1507, 2022-08-15:
fixed I think

Closed 2022-08-15.

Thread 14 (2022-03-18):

BBB_16_Expansion J1, J2, J3 pins 21-24

MmmDee, 2022-03-18:
This is more of a comment. I realize in your use case, the subject pins can be used as you desire; however, when interfacing a "real" F16V4 16-port Expansion card, Pin 21 is used as and tied to CLK (you have it labeled as GND) and your pin 23 is used for 3.3v. I don't believe pins 22-24 are used on Dave's board (I have a couple of the expansion boards, none of the controllers). This may be worth a mention somewhere. I appreciate you making this all open source.

computergeek1507, 2022-03-23:
Since FPP cannot drive 4 wire pixels I pulled the clock pin 21 to GND to prevent the buffer from oscillating On the F16v4 I have, pin 23 has v3.3 connected to it. On the v4 Expansion pin 23 went nowhere so I assume it was for future proofing if needed.

MmmDee, 2022-03-23:
Got it, close the issue. Didn't see a way to PM/email you aside from the Issues section. I don't have an F16V4 controller (that's what's driving me to BBB options) so I was unsure what was on p22-24 because, as you say, there's no connection on the F16V4 expansion board itself.

Closed 2022-03-23.

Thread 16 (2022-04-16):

BBB16 Expansion

Strawberry1997, 2022-04-16:
While testing the outputs I noticed that port 3, 11, 12, 16, 34, doesn't have any pixel data. I've tried it on 3 different BBB16 expansion controllers to rule out any soldering issues.
test was using BBB16 expansion > Diff Expansion > Receiver_Out_SMD > pixels strands.

Also tested the BBB16 expansion > 16_expansion SMD,  some ports work fine, some no data, some flickering.

computergeek1507, 2022-04-16:
What eeprom file did you use?

Strawberry1997, 2022-04-16:
I haven't used any eeprom file.Sent from my T-Mobile 4G LTE Device
-------- Original message --------From: Scott Hanson ***@***.***> Date: 4/15/22  10:16 PM  (GMT-05:00) To: computergeek1507/PB_16 ***@***.***> Cc: Strawberry1997 ***@***.***>, Author ***@***.***> Subject: Re: [computergeek1507/PB_16] BBB16 Expansion (Issue #16)
What eeprom file did you use?

—Reply to this email directly, view it on GitHub, or unsubscribe.You are receiving this because you authored the thread.Message ID: ***@***.***>

Strawberry1997, 2022-04-17:
I've tried the BBB16 and BBB16v2 eeprom files with no JOY. seems this board needs it's unique file.

computergeek1507, 2022-04-17:
I haven't generator one for it yet, I'll try to do it tonight.

computergeek1507, 2022-04-18:
Unzip this file and try this eeprom

[BBB16-Exp-eeprom.zip](https://github.com/computergeek1507/PB_16/files/8502943/BBB16-Exp-eeprom.zip)

Strawberry1997, 2022-04-19:
I've uploaded eeprom, it didn't seem too help.
Which controller> Vendor > model > variant, should I be using in Xlights?

Strawberry1997, 2022-04-19:
The EEPROM did allow for 48 stings in multiple configurations.
The buttons for the oled control seem to not function. I'm not sure how to configure them in the gpio section.
The voltage is reading vin1 27.2v and vin2 23.9. I'm only sending 5v from a dedicated PS.

computergeek1507, 2022-04-21:
there is no ADC circuits, I will have to fix that

Strawberry1997, 2022-05-03:
Have you had a chance to look at the ADA circuits? is this the cause of the flicker on the 16 expansion SMD board?

Closed 2022-06-22.

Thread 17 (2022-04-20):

PB 16 SMD CPL

tw0924, 2022-04-20:
I am having issues importing the CPL file to JLCPCB? Any advice on what im doing wrong?

computergeek1507, 2022-04-21:
What is the specific board or file?

tw0924, 2022-04-23:
My apologies, it’s is the PB16 V2 position file. It was giving me a error when trying to upload it

mrpburke, 2022-05-01:
I’ve found a couple discrepancies in the BOM and CPL files and the interactive BOM for this board. I just finished up an order so I can submit a pull request tomorrow with the updated files. Some part numbers are different on JLCPCB, SW4 & SW5 we’re missing from SMD BOM, rotation is off on a few components, and the JLCPCB format is slightly different that the provided csv files.

tw0924, 2022-05-02:
Thank you sir. Just trying to plan ahead for this Christmas! Thank you for all your work into this board and making it open source.

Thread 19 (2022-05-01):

Parts issue? BBB_16_SMD

Crezzie, 2022-05-01:
Hi im building a cart in digi-key to have a go at building my own BBB 16. Im having trouble with one item on your list being "not found" on their website. In the BBB_16_BOM file part no 29 Digi-key reference: 2571-CN34J330CTTR-ND is the only one i cant find are you able to help or update the part number? Im in australia if this helps.

Regards luke

Strawberry1997, 2022-05-01:
I think you have the wrong part #. I don't see this part in the BOM file. It appears you are looking for the 33 ohm resistor network.

mrpburke, 2022-05-01:
>

It's in the BBB 16 SMD BOM. The LCSC part # that's in the BOM is available in JLCPCB and appears to be the one you want (0603WAF330JT5E).

Crezzie, 2022-05-01:
beautiful found it guys thanks a bunch. also 1 more thing is there an alternative to the part on line 34 Part number for digi-key 811-2196-5-ND. the lead time is crazy and literally out of stock EVERYWHERE its the dc dc 5v converter. 1 site i went to said 52 week lead time.

mrpburke, 2022-05-01:
> beautiful found it guys thanks a bunch. also 1 more thing is there an alternative to the part on line 34 Part number for digi-key 811-2196-5-ND. the lead time is crazy and literally out of stock EVERYWHERE its the dc dc 5v converter. 1 site i went to said 52 week lead time.

I believe 102-P7805-2000-S-ND will also work.

computergeek1507, 2022-05-01:
The regulars have been out of stock since 2020, I have been working on a design with a built-in switcher chip, but they can be hit and miss as well.

Closed 2022-05-02.

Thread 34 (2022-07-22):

BBB_16_SMD U5 Part error

processor83, 2022-07-22:
Just to let you know that this part is not correctly connected.

for users dont order this without changes!

processor83, 2022-07-22:
Also just saw that OLED footprint should not be there in gerber files i understand its there for 3D rendering!

bcarriveau, 2022-07-22:
Not correctly connected in what way, orientation, trace not connected, routed wrong?

processor83, 2022-07-22:
footprint has changed and traces are not connected.  also OLED mounting holes should be removed im working on it to fix those but im not very goof with github to ask a pull of those fixes

processor83, 2022-07-22:
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
here is the oled part

computergeek1507, 2022-07-22:
Ill fix it, I was consolidating libraries and might have broke it

processor83, 2022-07-22:
Thank you!

I now also see the bleaglebone silk is showed  but im sure you will see it also!

computergeek1507, 2022-07-23:
This should be fixed now

Closed 2022-07-23.

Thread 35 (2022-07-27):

sugestion: use AM26C31CDR for DMX/LOR

processor83, 2022-07-27:
would it be possible to use AM26C31CDR for the DMX port ??  i did some test also made some espixelstick board and tested with dmx equipment and it was working properly.

This part is more available and cheaper also it reduce the number of part on the bom.

computergeek1507, 2022-08-15:
Updated the BBB16 SMD to use it

Closed 2023-04-10.

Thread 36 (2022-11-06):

BBB16 v2

Kosh42, 2022-11-06:
When uploading the binary [here](https://github.com/computergeek1507/PB_16/blob/master/BBB_16/BBB16v2-220513130004-eeprom.bin) the Cape Info in FPP reads as PBv2 instead of BBB. Is this correct?

Kosh42, 2022-11-06:
FYI - My cape is fairly old. PCB says BBB 16 v2. It has the OLED sticking out of the top and the BBB on top rather than underneath. Do I need the V2 or un-numbered version?

bcarriveau, 2022-11-06:
I installed the 220513130004 and it does in fact change it to a pb16v2
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

but my pixel string screen shows the correct cape type, so maybe its just the cape info that is wrong. (this board was previously flashed with firmware from before the july firmware update.) So if that cape type is right it should work just fine!

but if you want or the one you have does not work on the cape here is the older firmware that you may need a fpp license for or atleast have to email them to get a license or something.
pre 6.x firmware for bbb16v2
[BBB16v2-eeprom.zip](https://github.com/computergeek1507/PB_16/files/9946955/BBB16v2-eeprom.zip)

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

computergeek1507, 2022-11-06:
The BBBv2 is incorrect, I have emailed Chris multiple times over the last month to generate me a new one with no response. For the BBB16 with the BBB on the top you need the V1 eeprom file.

bcarriveau, 2022-11-06:
v1 file?
[BBB16-eeprom.zip](https://github.com/computergeek1507/PB_16/files/9946977/BBB16-eeprom.zip)

computergeek1507, 2022-11-06:
Think so

computergeek1507, 2023-04-10:
v2 EEPROM was fix with 8c6638d3b7af76e1e375479646f170d5cb0bfdbd

Closed 2023-04-10.

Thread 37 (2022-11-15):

BBB 16 v2.0

Mariio82, 2022-11-15:
Hello
I have a problem with the BBB 16 v2.0 driver version
I have two pieces and the same thing happens on both.
The problem is this type, all outputs work, but on some of them there are flashes on the test and on the sequence from time to time
What could be the problem

computergeek1507, 2022-12-11:
is this the SMD or regular version?

Mariio82, 2022-12-20:
regular version

kgreene1983, 2022-12-27:
Did you fix it?

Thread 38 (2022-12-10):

Need some tips and explanations how to write a code

stefancvetkovic, 2022-12-10:
And this is my first encounter with FPP. Previously I used WLED with dig-uno, quad stuff. But I think that FPP is more powerful including e1.31/DDP/ protocol standard
Can you please tell me if this board is good? I pick beaglebone for main cpu because of its hardware advantages, and Im wondering what I need of softare/hardware tools in order to flash it properly and make it work for this board? also I want to add seprate esp32 for wifi/ble communication and pairing with custom mobile app that I want to make (something mobile xLights)

kingofkristmas, 2022-12-25:
Lol

stefancvetkovic, 2022-12-27:
> Lol

?

bcarriveau, 2023-01-10:
So this is a Cape for a beagle bone. The beagle is not only a FPP device , FPP is also the firmware for the cape.  This may or may not be a good choice for you without a little background but it's really just soldering and FPP has a well documented setup manual.

Not sure anyone is here to give tutorials on codeing as this project does not require any.

Closed 2023-04-10.

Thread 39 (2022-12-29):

What actually goes on the SD card?

joelhauxwell, 2022-12-29:
Hi there,

I love a project so i'm going to assemble at least two of the BBB 16v2 boards to use with Xlights and my 2023 show.

Assuming I successfully build the PCBs, get the beaglebones and SD cards - what do I actually do with the cards?  Is there some firmware I need to stick onto them first, and is so, are there some instructions?

Thanks,

Joel.

Closed 2022-12-29.

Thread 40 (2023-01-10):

BBB 16 SMD V2.1 Part Placement

brymitch56, 2023-01-10:
When I upload the gerber, BOM and placement files to JLCPCB, many of the through hole parts are not placed correctly. Maybe this isn't an issue, as I've read that they don't do through hole anyway. Picture of their render attached with the components circled that look wrong to me.
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

bcarriveau, 2023-01-10:
Select the option to have jlc review it on the board selection options page and they will just adjust it for you.

brymitch56, 2023-01-11:
After playing around with the layout render, I figured out you can rotate and reposition parts within the GUI before adding to your cart. Though it's a bit of a pain, it looks like it should work. I've also found the same issue with the Receiver_Out_SMD, and I expect most other SMD boards.

Closed 2023-01-28.

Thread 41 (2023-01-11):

Receiver_Out_SMD assembly BOM incorrect RJ45

brymitch56, 2023-01-11:
When trying to add the Receiver_Out_SMD to my order on JLCPCB, I noticed the RJ45 connector in the BOM only has 6 of 8 pins populated. Looking at the schematic, I assume this won't work, since it looks like all 8 pins are used. The Digi-Key and manufacturer numbers look fine in the main BOM, but the BOM within the assembly folder has LCSC part number C305972, as compared to the assembly BOM of the BBB 16 SMD that I'm also trying to order which uses part number C2938579

computergeek1507, 2023-04-10:
fixed BOM

Closed 2023-04-10.

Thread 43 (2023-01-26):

BBB 16v2 OLED power and ground

tika911, 2023-01-26:
Let me start of by saying thanks for sharing this and that I have zero EE training.  I am just a hobbyist and am most likely doing something wrong but I could not get the OLED working.  Everything else is working great.  I started troubleshooting and I did not have power or ground at the OLED header.  Once I figured that out, I was able to find a good source of 3.3v on the pads located directly in front of the oled header.  I wired a couple of jumpers from these pads to the power and ground of the header and got the oled to work.

I had to use a TSR 1.5-2450E voltage converter in place of the 811-2196-5-ND due to availability.  I do not know if that is the reason for issue I am having.

computergeek1507, 2023-01-26:
This is the purpose of these jumper pads under the OLED. Some OLEDS have +3.3 and GND on different pins, I added these jumpers to allow the user to configure the correct pins. You jump them with a blob of solder.
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

brymitch56, 2023-01-26:
Are you using the SMD BBB version? There are solder pads on the board that you need to jumper with solder depending on the pin configuration of your OLED board. One for power, one for ground. The pins on some OLEDs are reversed, but instead of jumper pins, the SMD board has pads that need to be bridged with solder. They should be under where the OLED mounts, on the top of the board.

brymitch56, 2023-01-26:
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

tika911, 2023-01-26:
Thanks that makes sense.

computergeek1507, 2023-01-26:
On newer designs I have been adding a cutable bridge on the pads I normally use but I didn't add it to this one yet

Closed 2023-01-26.

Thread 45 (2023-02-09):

Possibility for new version of board to use FPGA/STM32

stefancvetkovic, 2023-02-09:
Is it possible to minimize the board in terms of non-using BBB but some more advanced integrated chips FPGA/STM32? thanks!

computergeek1507, 2023-02-09:
That was my intention of this PCB, but the firmware needs to be. I have also looked at an ESP32 based PCB as they are more available. written.https://github.com/computergeek1507/PB_16/tree/master/Teensy_16_SMD

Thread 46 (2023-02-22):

BBB has no power, board has

stefancvetkovic, 2023-02-22:
Any hint regarding that my BBB does not have power? also display is dead.
I put 5V to the left screws only. I tried to hold power btn, but nothing happens.
Thanks

bcarriveau, 2023-02-22:
The board needs to be powered at the bottom right to supply power to the BBB

stefancvetkovic, 2023-02-22:
But still, I dont have power on my BBB. Im using 5v DC, I can see green light on D6 diode, and I put 5A fuse on that spot. but BBB does not emitting any blue lamps.

computergeek1507, 2023-02-22:
You need to set the J23 jumper to 5V

computergeek1507, 2023-02-22:
And set J28 to the VIN position i.e down

computergeek1507, 2023-02-22:
its a different PCB but if you look at this PDF find the "Test Power" section and verify your voltages. I would do it with the BBB not connected until you know it right.

https://github.com/computergeek1507/PB_16/blob/master/PB_16v1/FPP%20PB16%20Pixel%20Controller%20Manual%20and%20Assembly%20Guide.pdf

stefancvetkovic, 2023-02-22:
Thanks, now I have the power on my BBB!
But still Icant access it over BBB's IP address.
When I disconnect BBB and put it the same UTP cable and its own supply, then it works, I can found on that IP address. Do you maybe know why is that? thanks again

computergeek1507, 2023-02-22:
The OLED will not turn on until you flash the EEprom or set it up in FPP. You also have to solder the jumpers under the OLED to the correct pinout of your OLED

stefancvetkovic, 2023-02-22:
Thanks @computergeek1507  can you point me out with which firmware should I need to flash eeprom? I found it on fpp=> about=> flash
But still it should be presenting fpp welcome screen even if connected to the board, but its not.

computergeek1507, 2023-02-22:
If running FPP 6 you should flash from the cape menu option. It needs to be the V2 version

stefancvetkovic, 2023-02-22:
I found this: https://github.com/computergeek1507/PB_16/blob/master/PB_16v2_SMD/PB16v2-220513130003-eeprom.bin
Also I will first update fpp to to version 6

computergeek1507, 2023-02-22:
it was moved to Help->Cape Info in FPP 6, The file you found in the repo had an error, I uploaded a new one here:

https://github.com/computergeek1507/PB_16/blob/master/BBB_16_SMD/BBB16v2-221118135219-eeprom.bin

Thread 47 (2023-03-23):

BBB_16 EEPROM

joelhauxwell, 2023-03-23:
Hello,

First of all, thanks for making all of this great stuff available!

I have decided to build some BBB_16 boards to control my 2023 Christmas display and have some PCBs on their way from JLCPCB.

Im struggling to source the exact thru-hole EEPROM from the BOM - are you able to suggest an in-stock alternative?

Thanks,

Joel.

GDWoody, 2023-03-23:
Hi,

Try this from LCSC part number C411624 this is what I used for my boards.

Also, I have made my own open hardware customized versions of Scott's BBB-16v2 SMD free for anyone to try.

https://github.com/GDWoody/Pixel-Controllers

joelhauxwell, 2023-03-23:
@GDWoody thanks for the link, much appreciated

Also, thanks for sharing your projects - your bbb_all_diff is a great fit for what I need...I feel another JLCPCB order coming on 😊.

computergeek1507, 2023-03-23:
The EEPROM file is 4KB so any EEPROM 4KB or bigger should work. "24LC32A-I/P-ND" or "25LC640-I/P-ND" are two I found doing a quick search. I haven't tested them, so order at your own risk.

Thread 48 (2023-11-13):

No pixel data from some expansion ports

sslupsky, 2023-11-13:
I encountered an issue with the 16 Expansion Dual SMD board where some outputs do not output pixel data.  Seems like the issue is similar to #16 and #18.  It is a weird issue where I had a prop using two strings located on ports 21 and 22 and the first string was not lighting up.  FPP shows the output configured correctly but there is no pixel data when doing display testing.  Could be some sort of output config issue but it is not obvious.  I tried moving the prop to ports 27 and 28 and had the same issue.  I confirmed the issue was not the prop by plugging the first string into port 22, which causes it to light up.  I found a workaround of sorts.  I reconfigured the prop as one string and connected to port 28 and it works there.

Commit #8c6638d says it was to "fix eeprom" but no other details about what was addressed.  I am currently using an earlier eeprom version of BBB16v2.  Here is the header from the EEPROM:
```
00000000  46 50 50 30 32 00 42 42  42 31 36 76 32 00 00 00  |FPP02.BBB16v2...|
00000010  00 00 00 00 00 00 00 00  00 00 00 00 00 00 00 00  |................|
00000020  32 2e 30 00 00 00 00 00  00 00 32 31 31 31 30 33  |2.0.......211103|
00000030  32 33 34 37 30 36 00 00  00 00 31 32 00 00 00 00  |234706....12....|
00000040  39 37 63 73 00 00 00 00  00 00 00 00 00 00 32 00  |97cs..........2.|
00000050  00 00 00 00 39 38 30 00  32 33 38 35 00 00 32 00  |....980.2385..2.|
00000060  74 6d 70 2f 63 61 70 65  2d 69 6e 66 6f 2e 74 67  |tmp/cape-info.tg|
00000070  7a 00 00 00 00 00 00 00  00 00 00 00 00 00 00 00  |z...............|
00000080  00 00 00 00 00 00 00 00  00 00 00 00 00 00 00 00  |................|
```

If I update the EEPROM with the new version, will that affect my FPP license and require a new license key?

sslupsky, 2024-03-07:
Turned out to be solder bridges (JLCPCB) to the ground plane.  Not sure if it was a board manufacturing issue with the solder mask/etching or their soldering process is poor.  Either way, there was bridging on several of the pins of the J9 20 pin expansion connector and JLCPCB QA did not catch it.  Saw this problem on another board where the I2C pin on J3 was bridged to ground.  If you use JLCPCB, you might want to inspect your boards carefully.

Closed 2024-03-07.

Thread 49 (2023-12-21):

EEPROM

bulldoglevin, 2023-12-21:
How do you fix a corrupt eeprom? Had a tough time flashing a bbb16v2 smd now it says it's corrupt.
Any help would be appreciated.

bulldoglevin, 2023-12-22:
the bom is 24L256 but the chip is ATMLH243 it is surface mount. the other boards work this was the first and it wouldn't take the voucher so i tried the old EEPROM file and then it came up as corrupt and it wont do any thing now.

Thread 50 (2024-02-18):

Request for help with Pi_Zero_24_Diff

Gooselight, 2024-02-18:
Hi Scott

Firstly, thank you for making all this wonderful material available and congratulations on your dedication to making our learning easier.

My name is Henrique, my nickname is Gooselight, I'm from Brazil and due to the difficulty in purchasing boards to use with BeagleBone Black here where we live, I decided to build some BBB_16 and Pi_Zero_24_Diff boards using their projects as a base.

The BBB_16 boards are working perfectly with version 5.5 of Fpp, but the Pi_Zero_24_Diff boards I'm trying to use with this 5.5 version as well, but unfortunately I'm not having success, I tried using the EEprom version: Pi_Zero_24_Diff-eeprom but it still didn't work.
Could you tell me if it is possible to use this scheme to work with this version of Fpp and this eeprom, or will it only work with versions above Fpp 6 or newer that need a signed eeprom. Can you help me with this?

Thank you once again for your material and help.

Henry B Garcia
Maringá PR Brazil

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
My board.

computergeek1507, 2024-02-18:
The DPI pixel output used by the pi based boards need FPP 6 or newer

Gooselight, 2024-02-18:
Thank you for quicly answer

Enviado do meu Samsung Mobile da Claro
Obter o Outlook para Android<https://aka.ms/AAb9ysg>
________________________________
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

Closed 2024-06-28.

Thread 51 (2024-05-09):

daisy chaining bbb 16

surajchauhan6631, 2024-05-09:
How can I daisy Chain Multiple BBB16 using ethernet if i want to use multiple BBB16 board over ethernet port?

computergeek1507, 2024-06-28:
not easy way to add this, also why Kulps don't have it either. You need to buy a network switch.

Closed 2024-06-28.

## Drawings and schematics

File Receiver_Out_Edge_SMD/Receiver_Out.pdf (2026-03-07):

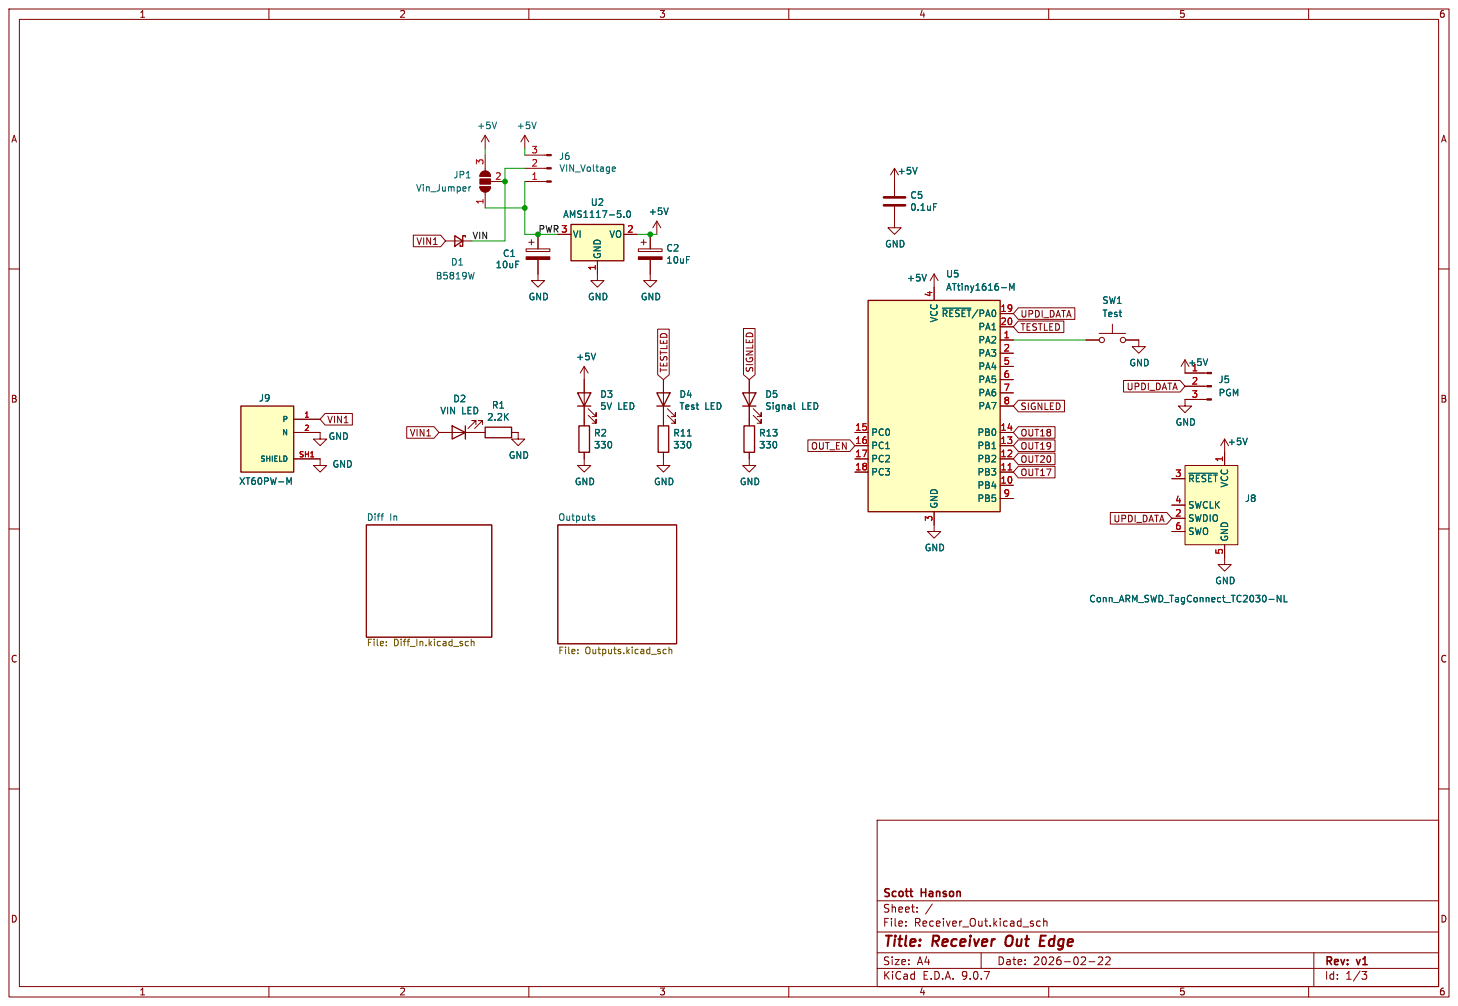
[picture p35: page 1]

5 ~{RESET} 3 SWCLK 4 SWDIO 2 SWO 6 +5V

5 ~{RESET} 3 SWCLK 4 SWDIO 2 SWO 6

Id: 1/3 Title: Receiver Out Edge

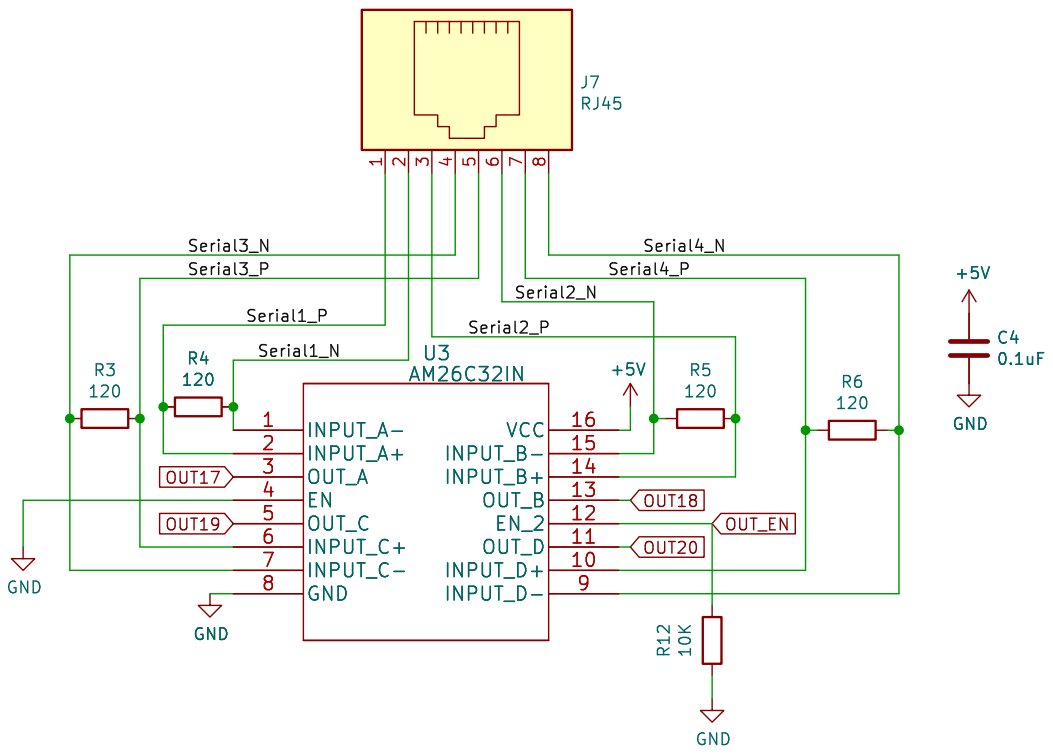
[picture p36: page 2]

Id: 2/3 Title: Receiver Out Edge

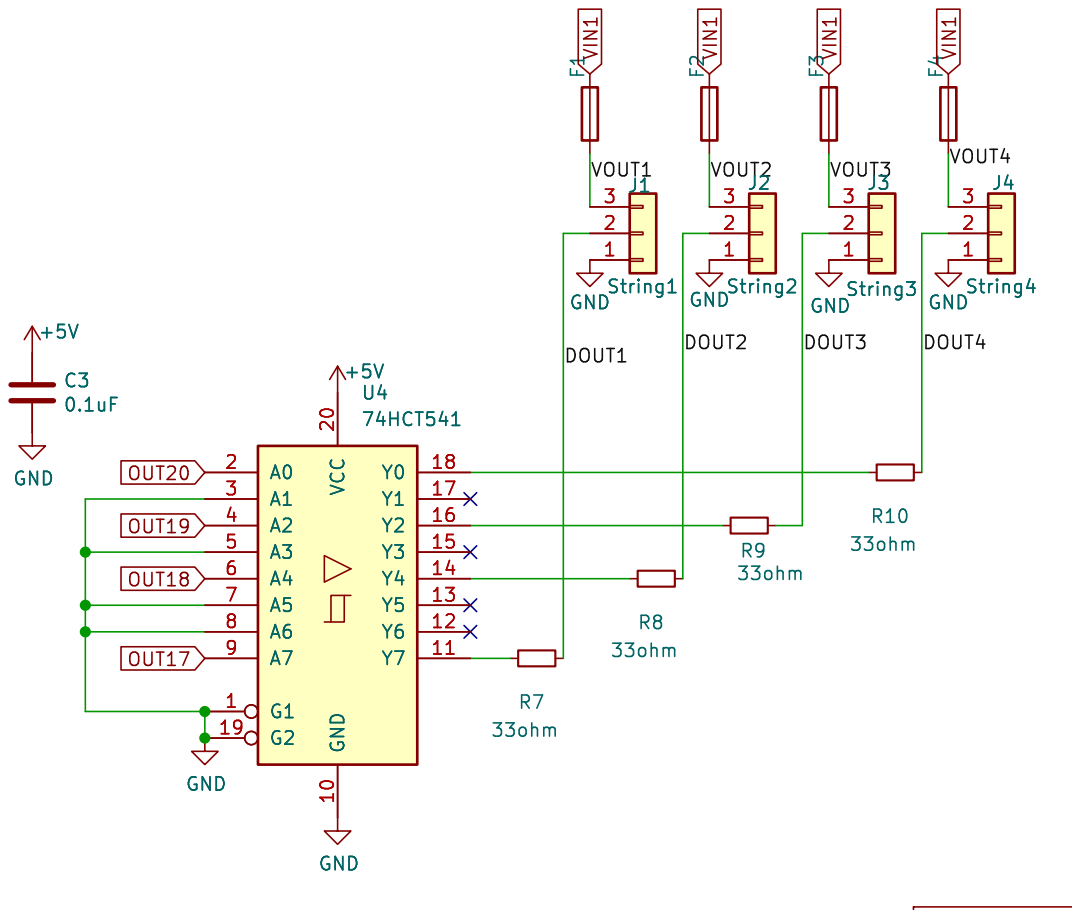
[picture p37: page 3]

Id: 3/3 Title: Receiver Out Edge

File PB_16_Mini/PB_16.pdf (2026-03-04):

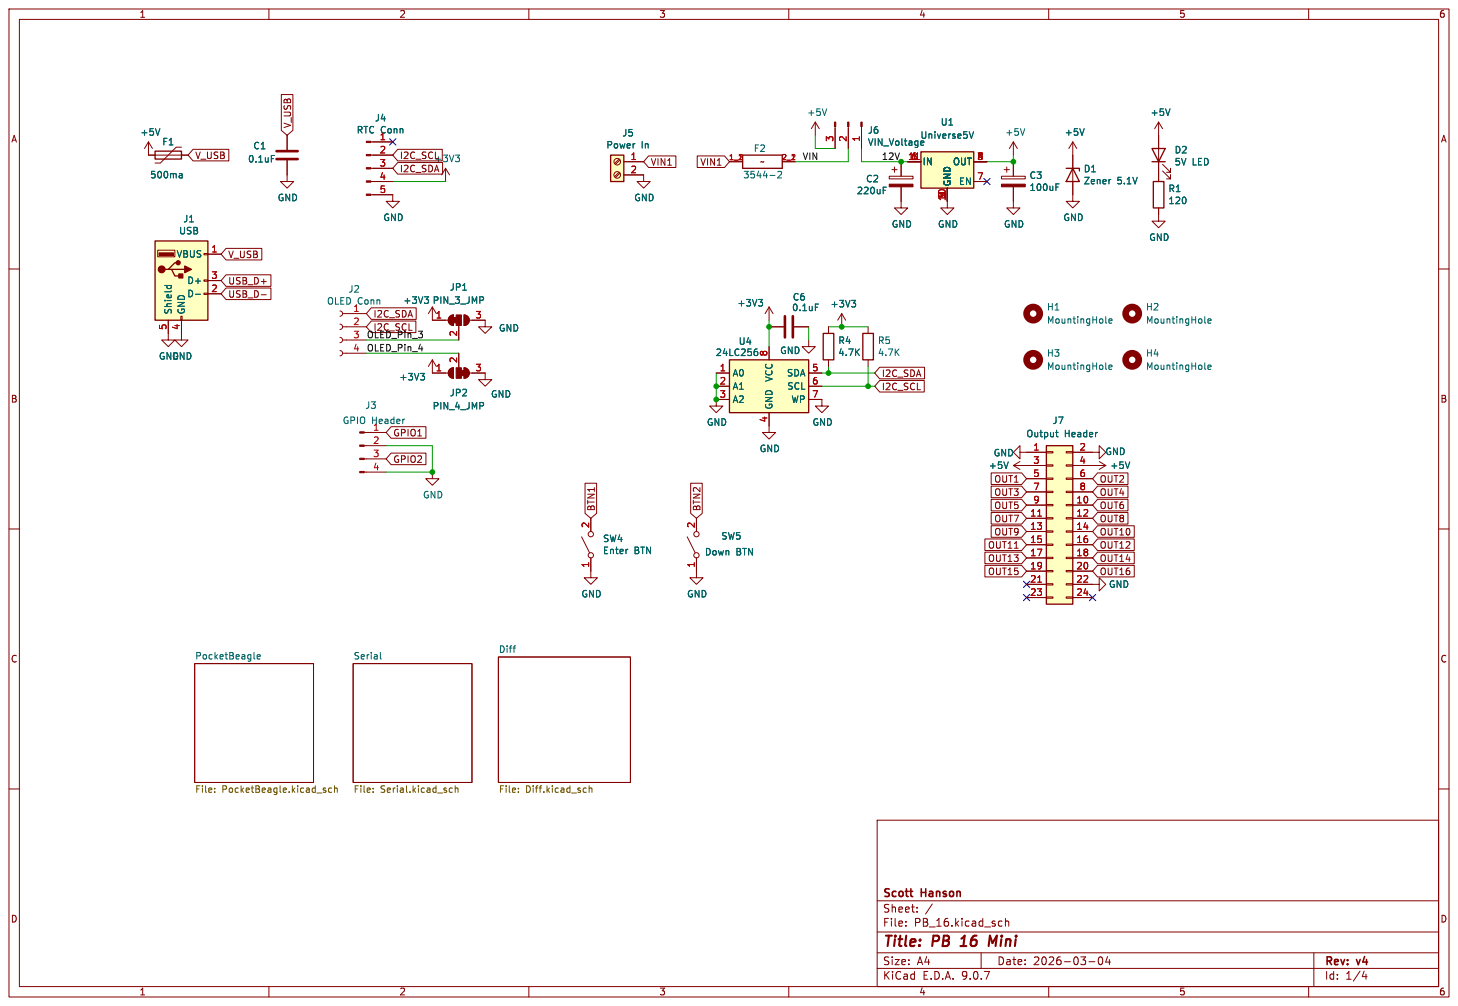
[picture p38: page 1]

4 SDA 5 SCL 6 WP 7 GND GND GND

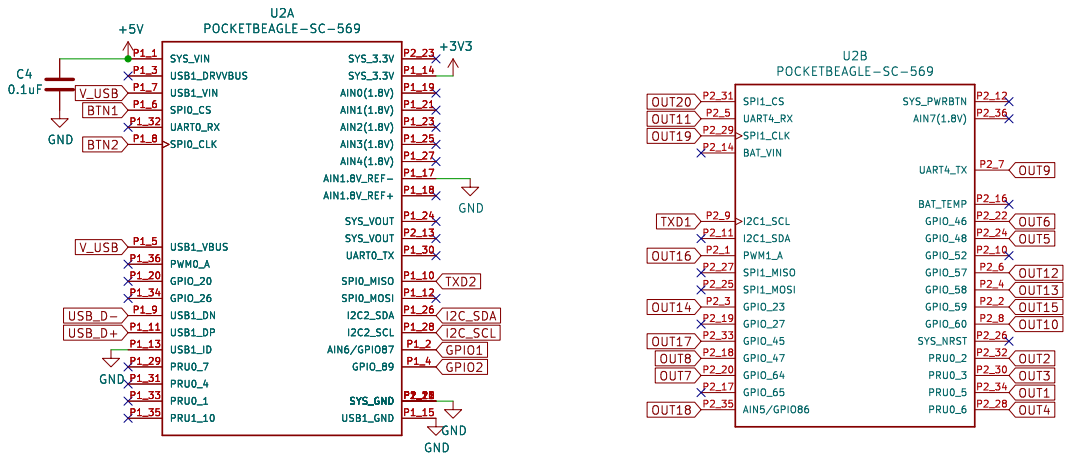
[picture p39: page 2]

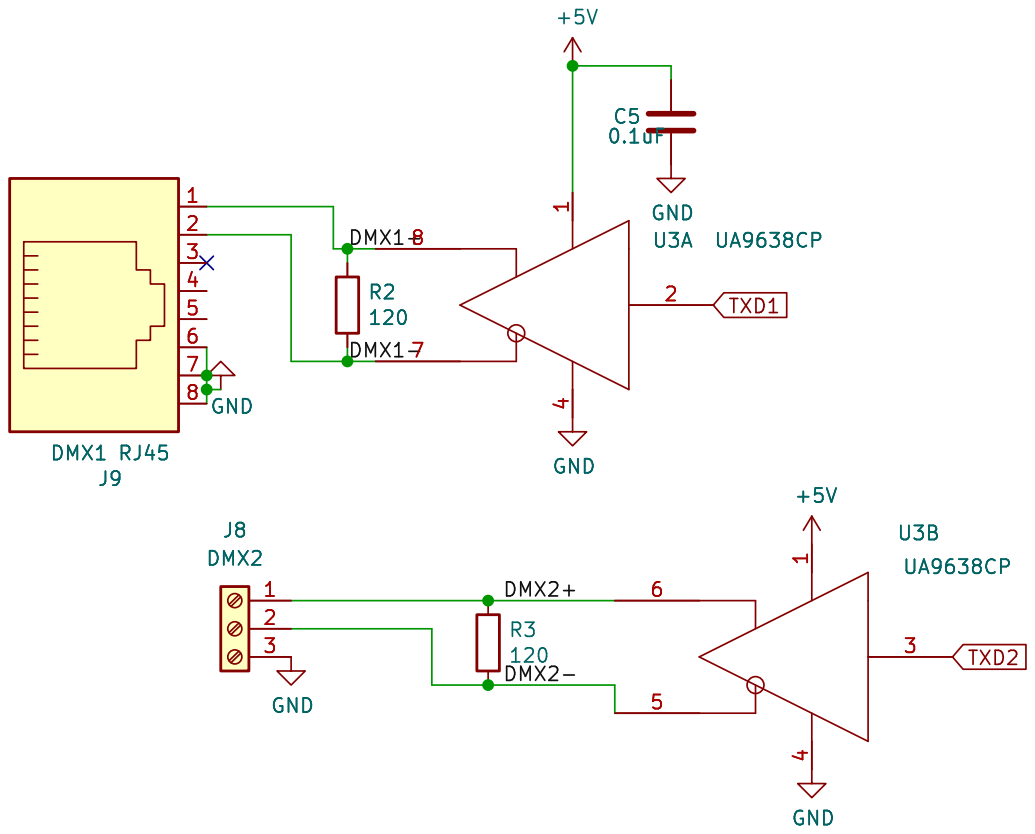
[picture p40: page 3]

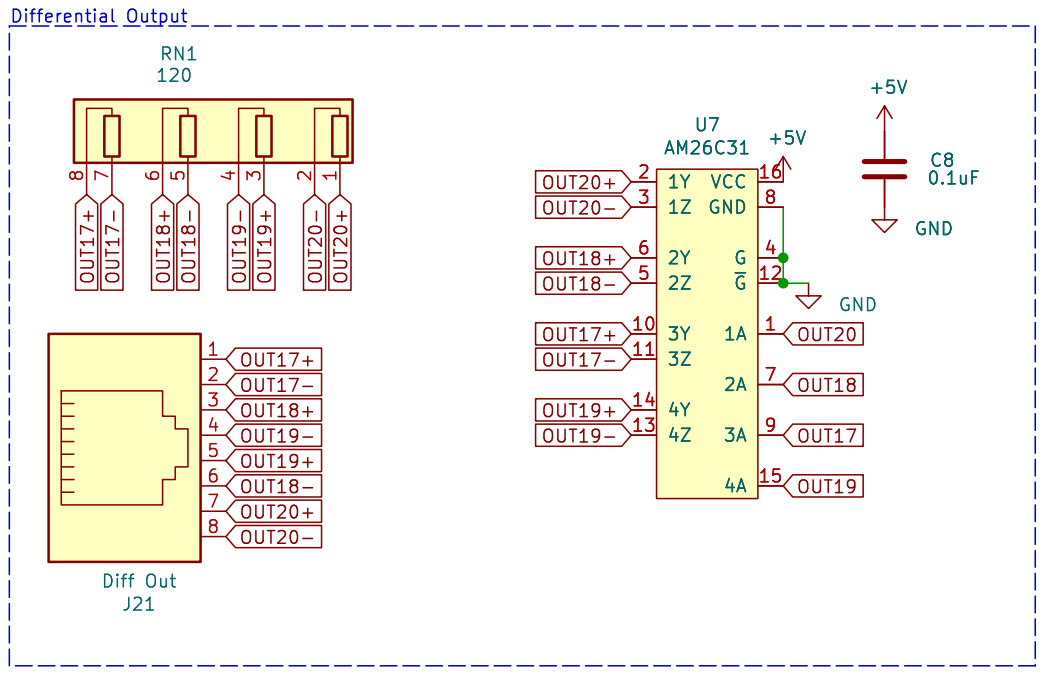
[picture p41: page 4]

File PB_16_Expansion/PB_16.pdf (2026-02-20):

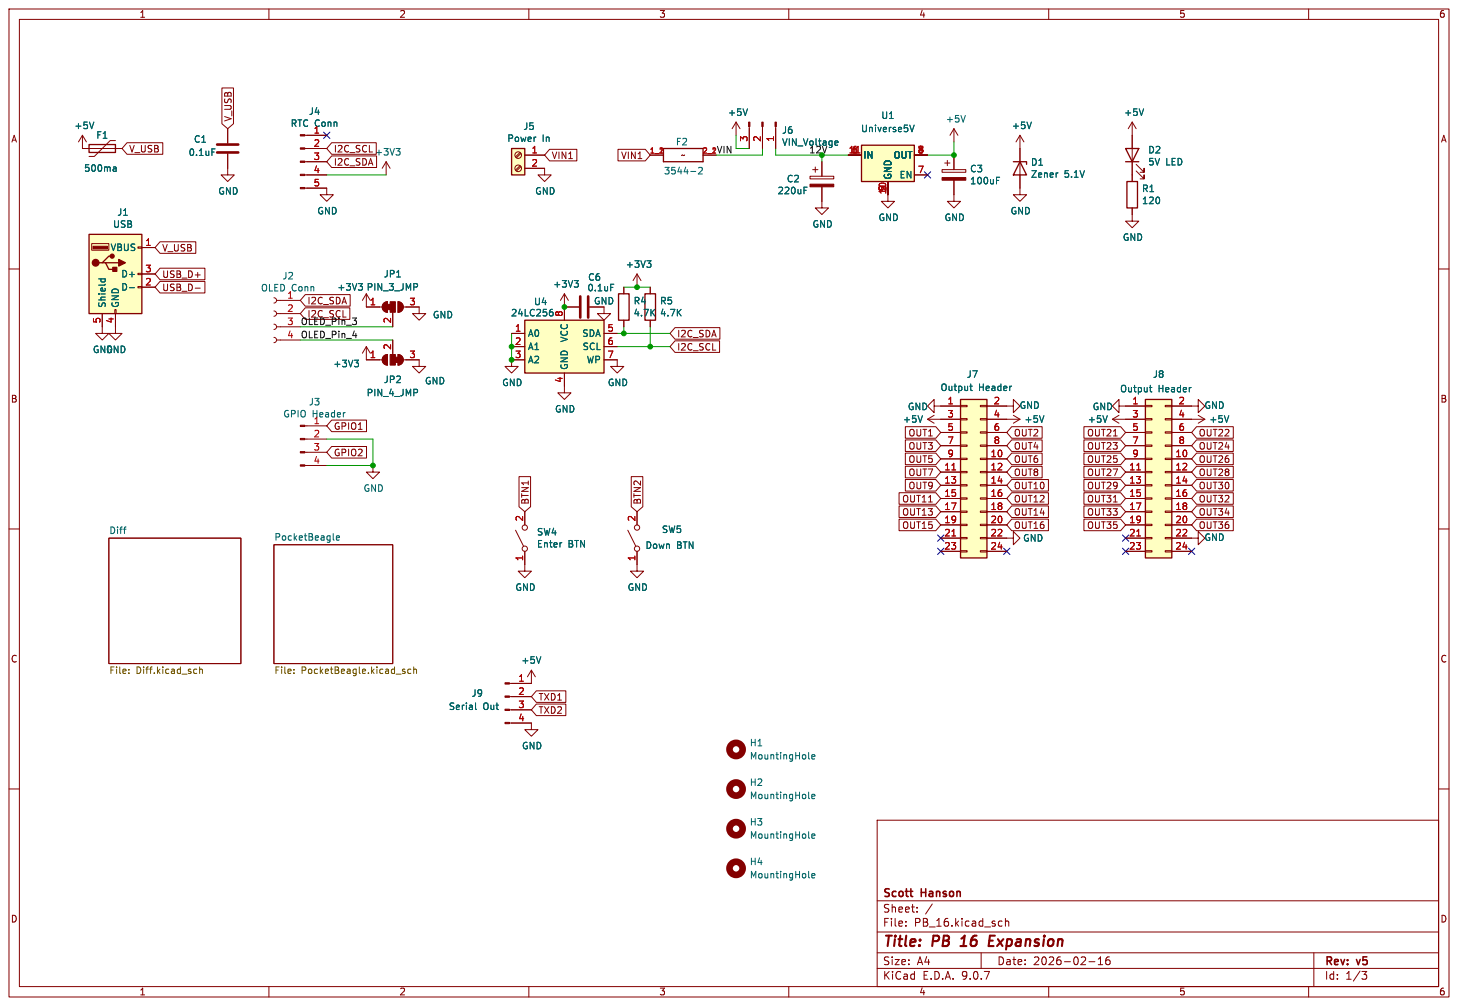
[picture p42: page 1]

4 SDA 5 SCL 6 WP 7 GND GND GND GND

PocketBeagle File: PocketBeagle.kicad_sch Diff File: Diff.kicad_sch

Id: 1/3 Title: PB 16 Expansion

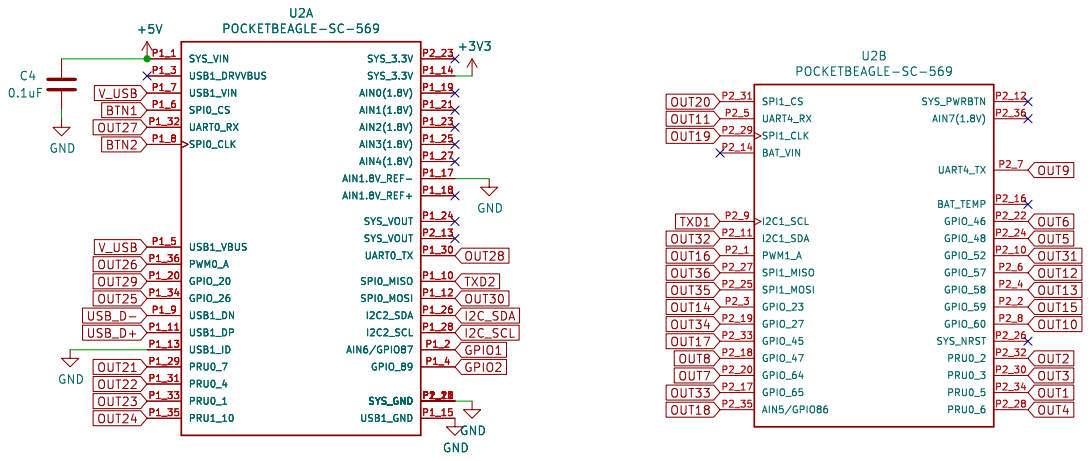
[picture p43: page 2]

Id: 2/3 Title: PB 16 Expansion

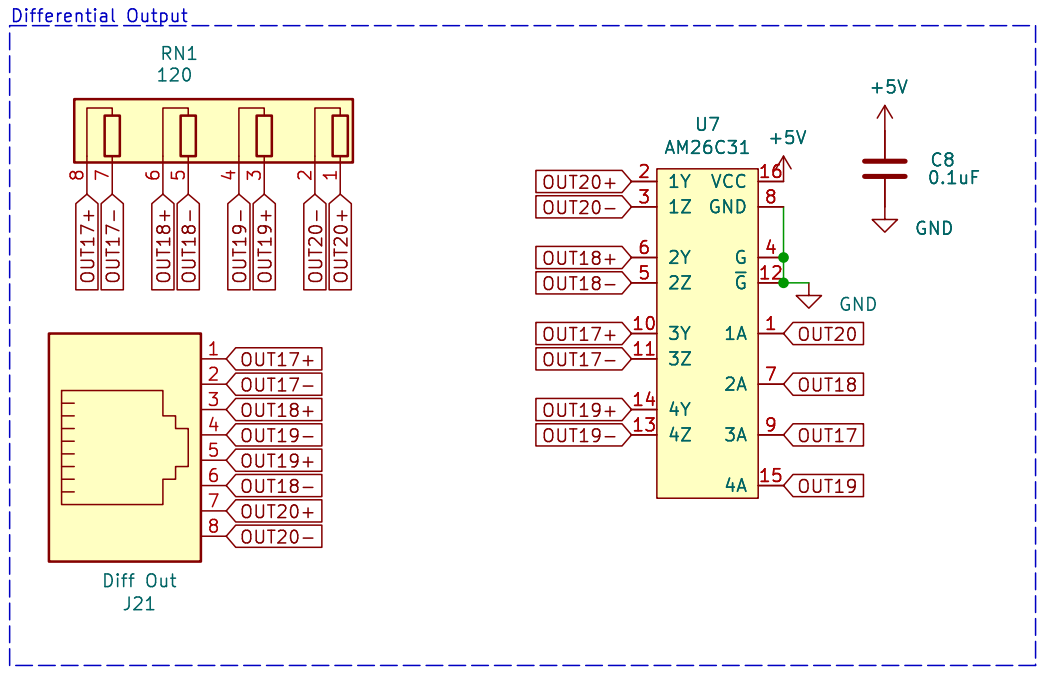
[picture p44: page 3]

Id: 3/3 Title: PB 16 Expansion

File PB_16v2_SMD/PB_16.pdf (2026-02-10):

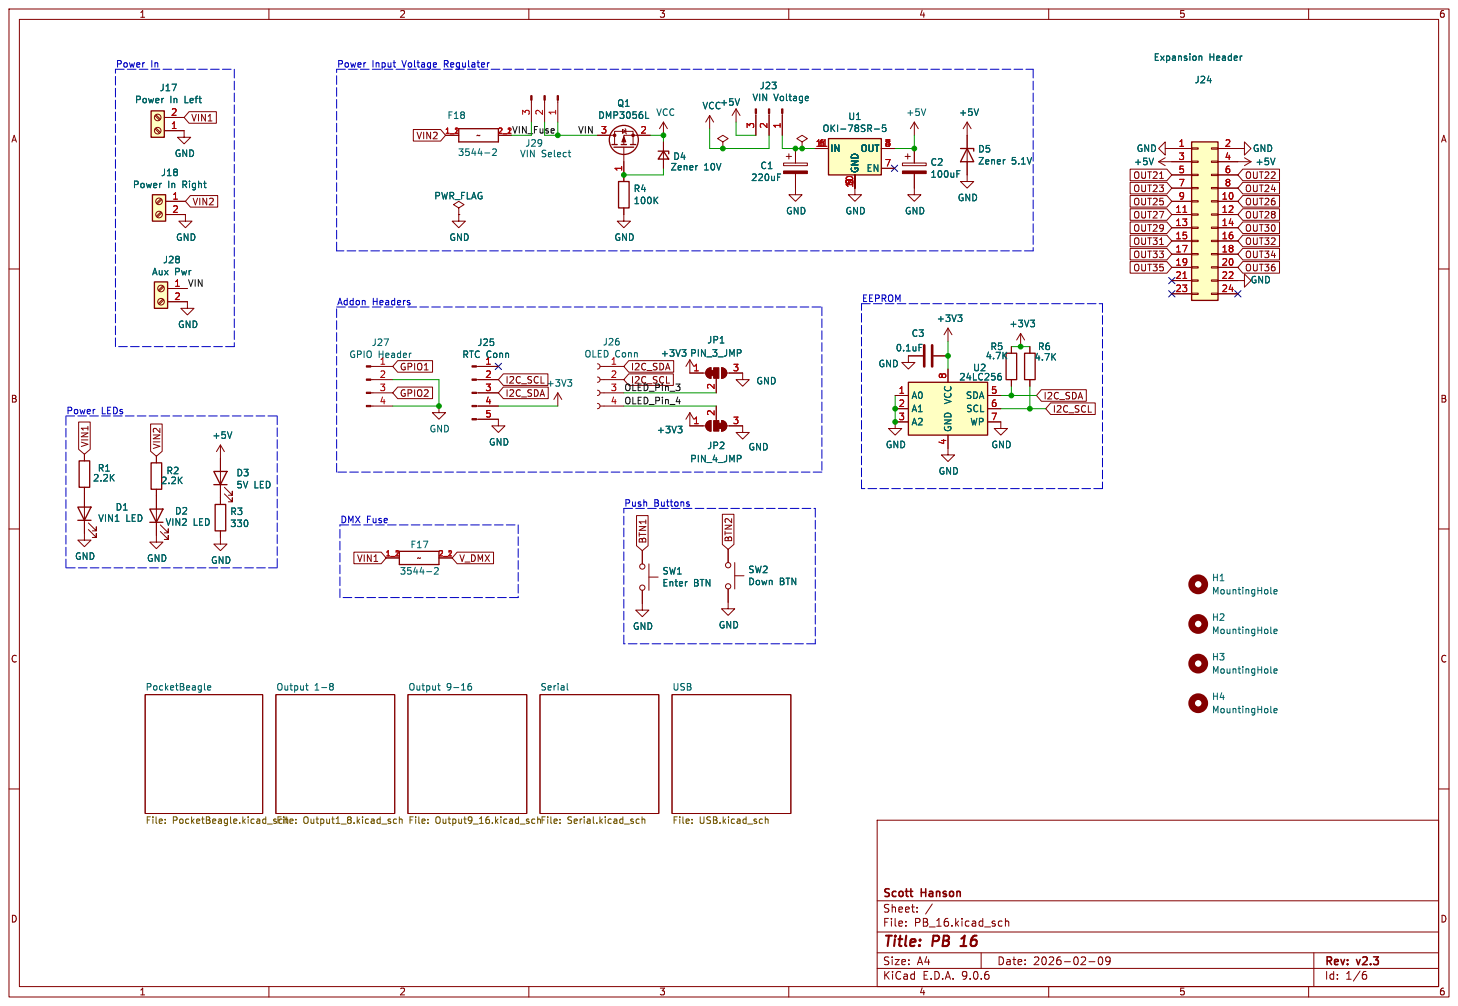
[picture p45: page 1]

D1 VIN1 LED GND GND GND

4 SDA 5 SCL 6 WP 7GND GND

H2 MountingHole H3 MountingHole H1 MountingHole H4 MountingHole R1

File: USB.kicad_sch Serial File: Serial.kicad_sch Output 9-16 File: Output9_16.kicad_sch

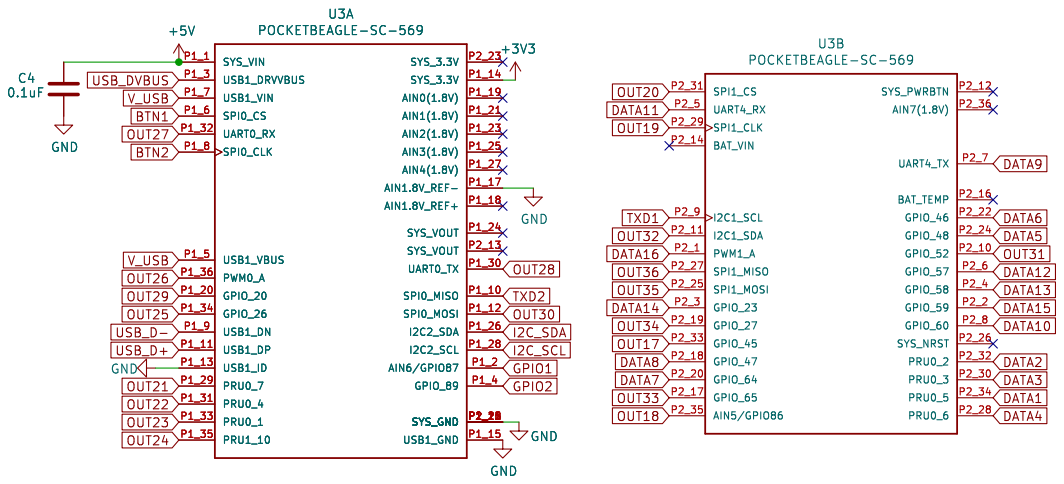
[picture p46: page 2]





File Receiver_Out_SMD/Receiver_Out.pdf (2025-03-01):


1 VO 2 VI 3 GND GND

1 SWDIO 2 ~{RESET} 3 SWCLK 4 GND

Id: 1/3 Title: Receiver Out SMD


Serial3_P

Serial1_P | Serial2_N

Id: 2/3 Title: Receiver Out SMD


Id: 3/3 Title: Receiver Out SMD

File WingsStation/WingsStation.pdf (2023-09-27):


Id: 1/4 Title: Button Station


Id: 2/4 Title: Button Station


Id: 3/4 Title: Button Station


File: Micro.kicad_sch Sheet: /Micro/
Id: 4/4 Title: Button Station

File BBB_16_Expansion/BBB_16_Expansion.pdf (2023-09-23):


2 OUT 3 U4Universe5V GND GND GND GND

2 OUT 3 GND GND GND

4 SDA 5 SCL 6 WP 7 VCC

File: BBB_16_Expansion.kicad_sch Sheet: / Scott Hanson

Id: 1/3 Title: BBB 16 Expansion


Sheet: /PocketBeagle/ Scott Hanson

File: PocketBeagle.kicad_sch
Id: 2/3 Title: BBB 16 Expansion


File: Serial.kicad_sch Sheet: /Serial/ Scott Hanson

Id: 3/3 Title: BBB 16 Expansion

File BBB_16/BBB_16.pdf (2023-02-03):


4 SDA 5 SCL 6 WP 7 VCC


Sheet: /BeagleBone/ Scott Hanson


Serial1_N

3 | | Serial2_P

File: Diff.kicad_sch Sheet: /Diff/ Scott Hanson GND

5 | | | Serial3_P
7 | | Serial4_P
8 | Serial4_N


Sheet: /Output 1-8/ Scott Hanson GND


8 RN333 GND GND GND DIR 1 GND 10 B8 11 B7 12 B6 13 B5 14 B4 15 B3 16 B2 17 B1 18

Sheet: /Output 9-16/ Scott Hanson


File: Serial.kicad_sch Sheet: /Serial/ Scott Hanson

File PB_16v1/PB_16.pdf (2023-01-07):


8 GND GND GND GND

4 SDA 5 SCL 6 WP 7 VCC

1 2 SW4 Enter BTN 1 2 SW5 Down BTN GND GND

File: PB_16.kicad_sch Sheet: / Scott Hanson Output 9-16


Sheet: /PocketBeagle/ Scott Hanson GNDGND




File: Serial.kicad_sch Sheet: /Serial/ Scott Hanson

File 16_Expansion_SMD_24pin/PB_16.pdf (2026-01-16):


Id: 1/3 Title: 16 Expansion SMD 24pin


Id: 2/3 Title: 16 Expansion SMD 24pin


Id: 3/3 Title: 16 Expansion SMD 24pin

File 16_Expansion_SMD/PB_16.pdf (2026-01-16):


Id: 1/3 Title: 16 Expansion SMD


Id: 2/3 Title: 16 Expansion SMD


Id: 3/3 Title: 16 Expansion SMD


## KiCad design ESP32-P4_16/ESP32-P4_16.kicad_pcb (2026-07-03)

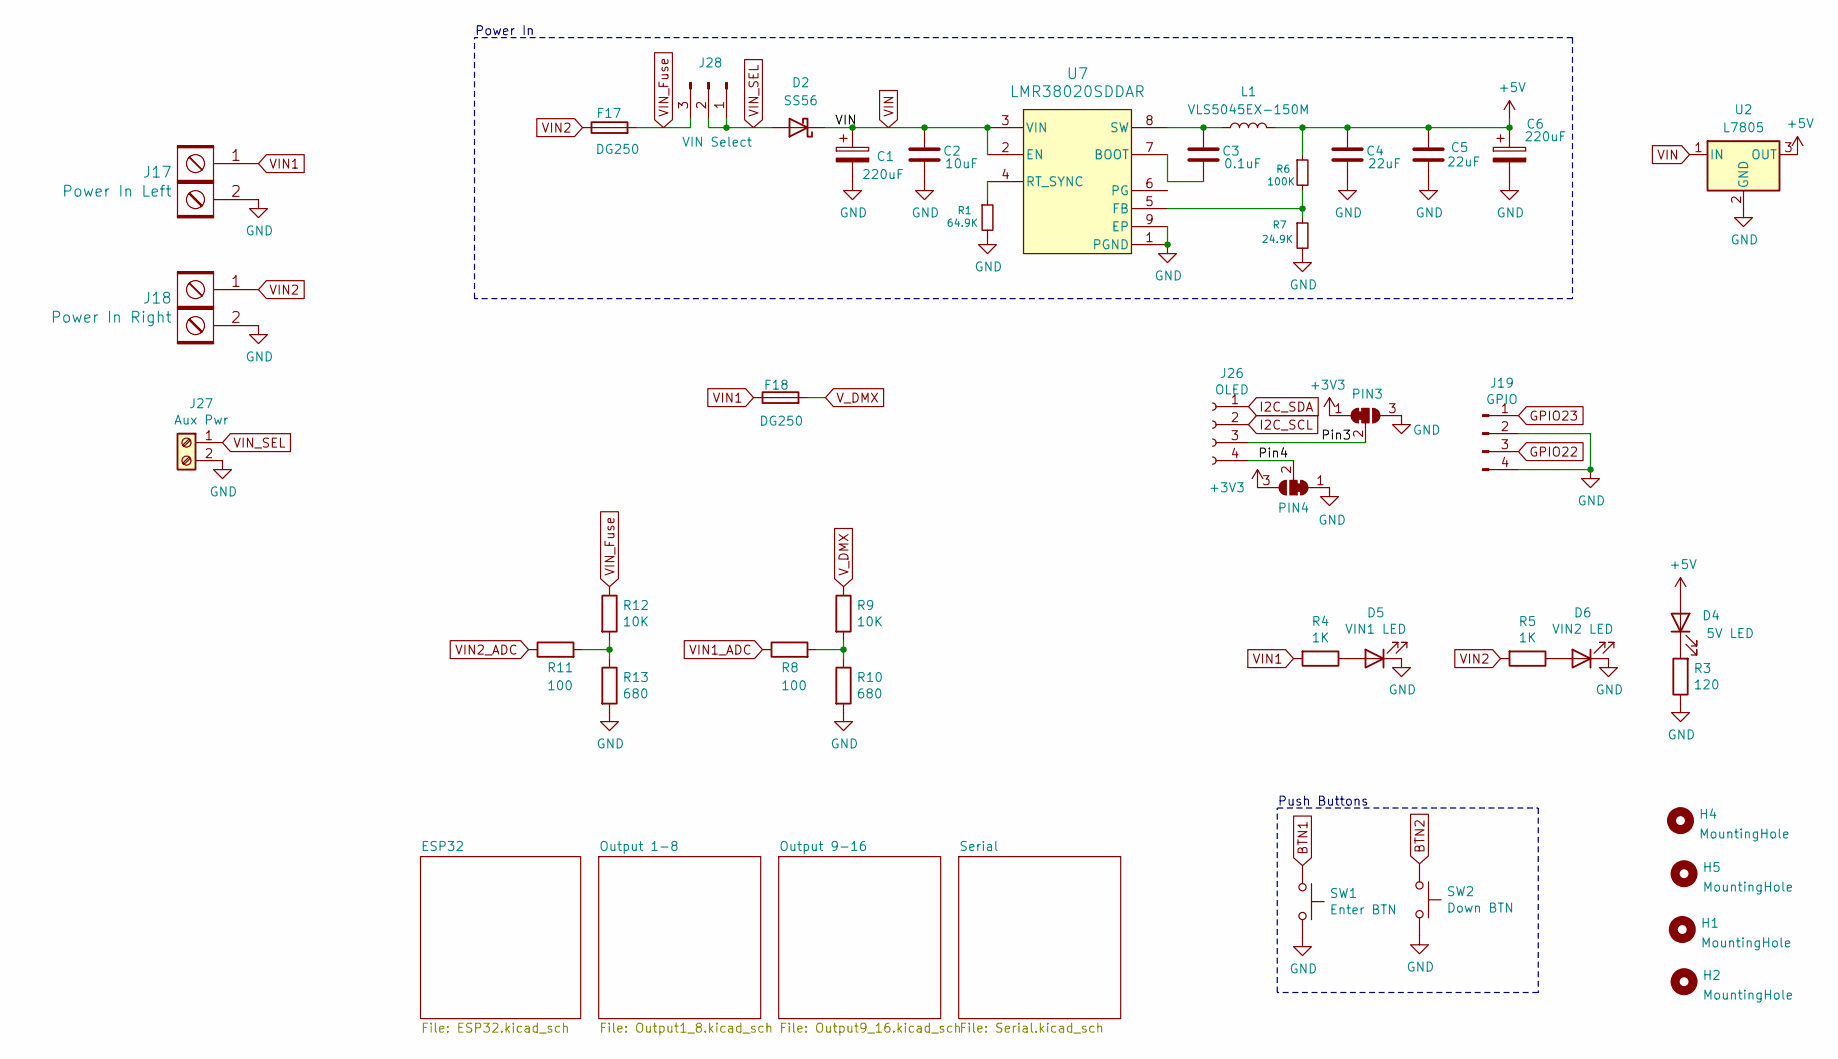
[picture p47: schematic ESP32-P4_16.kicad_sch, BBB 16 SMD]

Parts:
C1, C6: 220uF; CP_Elec_8x10.5; LCSC C3340
C2: 10uF; C_1206_3216Metric; LCSC_PN C13585
C3: 0.1uF; C_0603_1608Metric; MPN CC0603KRX7R9BB104; LCSC C14663
C4, C5: 22uF; C_1206_3216Metric; LCSC_PN C1859
D2: SS56; D_SMA; LCSC C65009
D4: 5V LED; LED_0603_1608Metric; MPN LTST-C190KRKT; Digi-Key_PN 160-1436-2-ND
D5: VIN1 LED; LED_0603_1608Metric; MPN LTST-C190KRKT; Digi-Key_PN 160-1436-2-ND
D6: VIN2 LED; LED_0603_1608Metric; MPN LTST-C190KRKT; Digi-Key_PN 160-1436-2-ND
F17: DG250; Fuse_1812_4532Metric; MPN 3544-2
F18: DG250; Fuse_1812_4532Metric
H1, H2, H4, H5: MountingHole; MountingHole_3.7mm
J17: Power In Left; BARRIER_BLOCK_1ROW_2POS_P9.5MM; MPN OSTYK51102030; Digi-Key_PN ED2953-ND
J18: Power In Right; BARRIER_BLOCK_1ROW_2POS_P9.5MM; MPN OSTYK51102030; Digi-Key_PN ED2953-ND
J19: GPIO; JST_XH_B4B-XH-A_1x04_P2.50mm_Vertical; MPN B4B-XH-A(LF)(SN); Digi-Key_PN 455-2249-ND
J26: OLED; OLED-SSD1306-128X64-I2C-THT_2HOLE; MPN PPTC041LFBN-RC; Digi-Key_PN S7002-ND
J27: Aux Pwr; PHOENIX_MKDS1_2-3.81; MPN 1727010; Digi-Key_PN 277-1947-ND
J28: VIN Select; PinHeader_1x03_P2.54mm_Vertical; MPN 61300311121; Digi-Key_PN 732-5316-ND
L1: VLS5045EX-150M; IND_VLS5045EX-150M; MPN VLS5045EX-150M; Digi-Key_PN 445-174845-1-ND
PIN3: Jumper; SolderJumper-3_P1.3mm_Bridged12_Pad1.0x1.5mm
PIN4: JUMPER; SolderJumper-3_P1.3mm_Bridged12_Pad1.0x1.5mm
R1: 64.9K; R_0603_1608Metric; LCSC C14891
R3: 120; R_0603_1608Metric; MPN CRGCQ0603F120R; Digi-Key_PN A129677CT-ND
R4, R5: 1K; R_0603_1608Metric; MPN RC0603FR-071KL; Digi-Key_PN 311-1.00KHRTR-ND
R6: 100K; R_0603_1608Metric; LCSC C25803
R7: 24.9K; R_0603_1608Metric; LCSC C25962
R8, R11: 100; R_0603_1608Metric; MPN RMCF0603FT100R; Digi-Key_PN RMCF0603FT100RCT-ND
R9, R12: 10K; R_0603_1608Metric; MPN RC0603FR-0710KL; Digi-Key_PN 311-10.0KHRCT-ND
R10, R13: 680; R_0603_1608Metric; MPN RC0603FR-07680RL; Digi-Key_PN 311-680HRCT-ND
SW1: Enter BTN; SW_Push_1P1T_NO_6x6mm_H9.5mm; MPN PTS645SL50SMTR92 LFS; Digi-Key_PN CKN9088CT-ND
SW2: Down BTN; SW_Push_1P1T_NO_6x6mm_H9.5mm; MPN PTS645SL50SMTR92 LFS; Digi-Key_PN CKN9088CT-ND
U2: L7805; OKI-78SR_Horz
U7: LMR38020SDDAR; DDA0008E-IPC_A; MPN LMR38020SDDAR; Digi-Key_PN 296-LMR38020SDDARCT-ND

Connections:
+3V3: PIN3.1 (A), PIN4.3 (B); also elsewhere on the board
+5V: C4.1, C5.1, C6.1, D4.2 (A), L1.2, R6.1, U2.3 (OUT); also elsewhere on the board
/Pin3: J26.3, PIN3.2 (C)
/Pin4: J26.4, PIN4.2 (C)
BTN1: SW1.1; also elsewhere on the board
BTN2: SW2.1; also elsewhere on the board
GND: C1.2, C2.2, C4.2, C5.2, C6.2, D5.1 (K), D6.1 (K), J17.2, J18.2, J19.2, J19.4, J27.2, PIN3.3 (B), PIN4.1 (A), R1.2, R3.1, R7.2, R10.2, R13.2, SW1.2, SW2.2, U2.2 (GND), U7.1 (PGND), U7.9 (EP); also elsewhere on the board
GPIO22: J19.3; also elsewhere on the board
GPIO23: J19.1; also elsewhere on the board
I2C_SCL: J26.2; also elsewhere on the board
I2C_SDA: J26.1; also elsewhere on the board
unnamed: D4.1 (K), R3.2
unnamed: D5.2 (A), R4.1
unnamed: D6.2 (A), R5.1
unnamed: R8.2, R9.2, R10.1
unnamed: R11.2, R12.2, R13.1
unnamed: C3.2, U7.7 (BOOT)
unnamed: R6.2, R7.1, U7.5 (FB)
unnamed: R1.1, U7.4 (RT_SYNC)
unnamed: C3.1, L1.1, U7.8 (SW)
VIN: C1.1, C2.1, D2.1 (K), U2.1 (IN), U7.2 (EN), U7.3 (VIN)
VIN1: F18.1, J17.1, R4.2; also elsewhere on the board
VIN1_ADC: R8.1; also elsewhere on the board
VIN2: F17.1, J18.1, R5.2; also elsewhere on the board
VIN2_ADC: R11.1; also elsewhere on the board
VIN_Fuse: F17.2, J28.3, R12.1
VIN_SEL: D2.2 (A), J27.1, J28.1, J28.2
V_DMX: F18.2, R9.1; also elsewhere on the board

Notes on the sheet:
Push Buttons
Power In

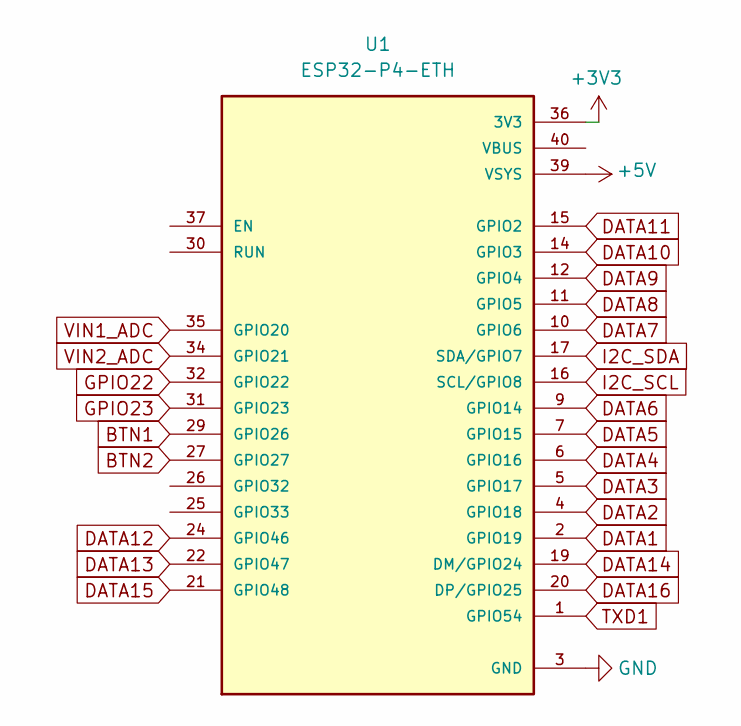
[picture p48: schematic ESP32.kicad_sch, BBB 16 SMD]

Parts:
U1: ESP32-P4-ETH; MODULE_ESP32-P4-ETH

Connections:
+3V3: U1.36 (3V3); also elsewhere on the board
+5V: U1.39 (VSYS); also elsewhere on the board
BTN1: U1.29 (GPIO26); also elsewhere on the board
BTN2: U1.27 (GPIO27); also elsewhere on the board
DATA1: U1.2 (GPIO19); also elsewhere on the board
DATA2: U1.4 (GPIO18); also elsewhere on the board
DATA3: U1.5 (GPIO17); also elsewhere on the board
DATA4: U1.6 (GPIO16); also elsewhere on the board
DATA5: U1.7 (GPIO15); also elsewhere on the board
DATA6: U1.9 (GPIO14); also elsewhere on the board
DATA7: U1.10 (GPIO6); also elsewhere on the board
DATA8: U1.11 (GPIO5); also elsewhere on the board
DATA9: U1.12 (GPIO4); also elsewhere on the board
DATA10: U1.14 (GPIO3); also elsewhere on the board
DATA11: U1.15 (GPIO2); also elsewhere on the board
DATA12: U1.24 (GPIO46); also elsewhere on the board
DATA13: U1.22 (GPIO47); also elsewhere on the board
DATA14: U1.19 (DM/GPIO24); also elsewhere on the board
DATA15: U1.21 (GPIO48); also elsewhere on the board
DATA16: U1.20 (DP/GPIO25); also elsewhere on the board
GND: U1.3 (GND), U1.8 (GND), U1.13 (GND), U1.18 (GND), U1.23 (GND), U1.28 (GND), U1.33 (GND), U1.38 (GND); also elsewhere on the board
GPIO22: U1.32 (GPIO22); also elsewhere on the board
GPIO23: U1.31 (GPIO23); also elsewhere on the board
I2C_SCL: U1.16 (SCL/GPIO8); also elsewhere on the board
I2C_SDA: U1.17 (SDA/GPIO7); also elsewhere on the board
TXD1: U1.1 (GPIO54); also elsewhere on the board
VIN1_ADC: U1.35 (GPIO20); also elsewhere on the board
VIN2_ADC: U1.34 (GPIO21); also elsewhere on the board

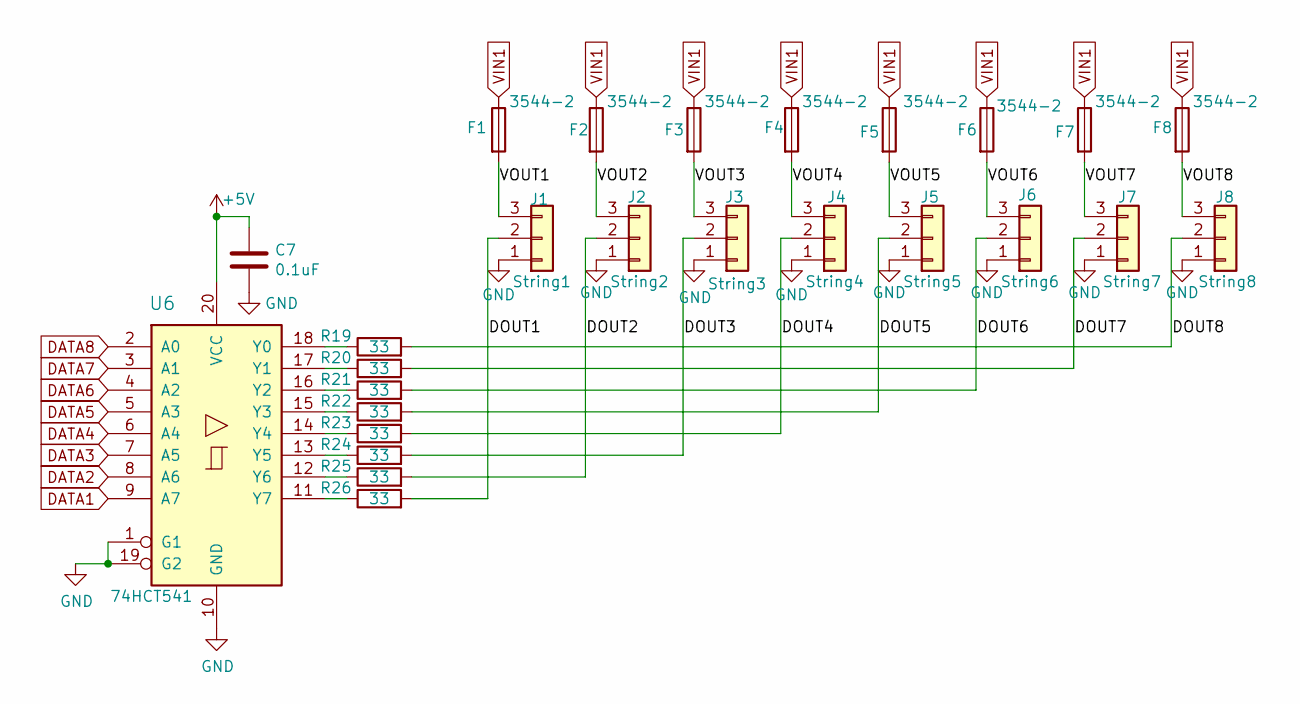
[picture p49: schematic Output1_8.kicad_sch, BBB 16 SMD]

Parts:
C7: 0.1uF; C_0603_1608Metric; MPN CL10B104KB8NNWC; Digi-Key_PN 1276-1935-2-ND
F1, F2, F3, F4, F5, F6, F7, F8: 3544-2; Fuse_1812_4532Metric; MPN 3544-2
J1: String1; DG250-3.5-03P; MPN 1843619/OSTTJ0311530
J2: String2; DG250-3.5-03P; MPN 1843619/OSTTJ0311530
J3: String3; DG250-3.5-03P; MPN 1843619/OSTTJ0311530
J4: String4; DG250-3.5-03P; MPN 1843619/OSTTJ0311530
J5: String5; DG250-3.5-03P; MPN 1843619/OSTTJ0311530
J6: String6; DG250-3.5-03P; MPN 1843619/OSTTJ0311530
J7: String7; DG250-3.5-03P; MPN 1843619/OSTTJ0311530
J8: String8; DG250-3.5-03P; MPN 1843619/OSTTJ0311530
R19, R20, R21, R22, R23, R24, R25, R26: 33; R_0603_1608Metric; MPN CN34J330CT; LCSC C23140
U6: 74HCT541; TSSOP-20_4.4x6.5mm_P0.65mm; MPN SN74HCT541PWR; Digi-Key_PN MC74HCT541ADTR2GOSTR-ND

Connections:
+5V: C7.1, U6.20 (VCC); also elsewhere on the board
/Output 1-8/DOUT1: J1.2, R26.2
/Output 1-8/DOUT2: J2.2, R25.2
/Output 1-8/DOUT3: J3.2, R24.2
/Output 1-8/DOUT4: J4.2, R23.2
/Output 1-8/DOUT5: J5.2, R22.2
/Output 1-8/DOUT6: J6.2, R21.2
/Output 1-8/DOUT7: J7.2, R20.2
/Output 1-8/DOUT8: J8.2, R19.2
/Output 1-8/VOUT1: F1.2, J1.3
/Output 1-8/VOUT2: F2.2, J2.3
/Output 1-8/VOUT3: F3.2, J3.3
/Output 1-8/VOUT4: F4.2, J4.3
/Output 1-8/VOUT5: F5.2, J5.3
/Output 1-8/VOUT6: F6.2, J6.3
/Output 1-8/VOUT7: F7.2, J7.3
/Output 1-8/VOUT8: F8.2, J8.3
DATA1: U6.9 (A7); also elsewhere on the board
DATA2: U6.8 (A6); also elsewhere on the board
DATA3: U6.7 (A5); also elsewhere on the board
DATA4: U6.6 (A4); also elsewhere on the board
DATA5: U6.5 (A3); also elsewhere on the board
DATA6: U6.4 (A2); also elsewhere on the board
DATA7: U6.3 (A1); also elsewhere on the board
DATA8: U6.2 (A0); also elsewhere on the board
GND: C7.2, J1.1, J2.1, J3.1, J4.1, J5.1, J6.1, J7.1, J8.1, U6.1 (G1), U6.10 (GND), U6.19 (G2); also elsewhere on the board
unnamed: R19.1, U6.18 (Y0)
unnamed: R20.1, U6.17 (Y1)
unnamed: R21.1, U6.16 (Y2)
unnamed: R22.1, U6.15 (Y3)
unnamed: R23.1, U6.14 (Y4)
unnamed: R24.1, U6.13 (Y5)
unnamed: R25.1, U6.12 (Y6)
unnamed: R26.1, U6.11 (Y7)
VIN1: F1.1, F2.1, F3.1, F4.1, F5.1, F6.1, F7.1, F8.1; also elsewhere on the board

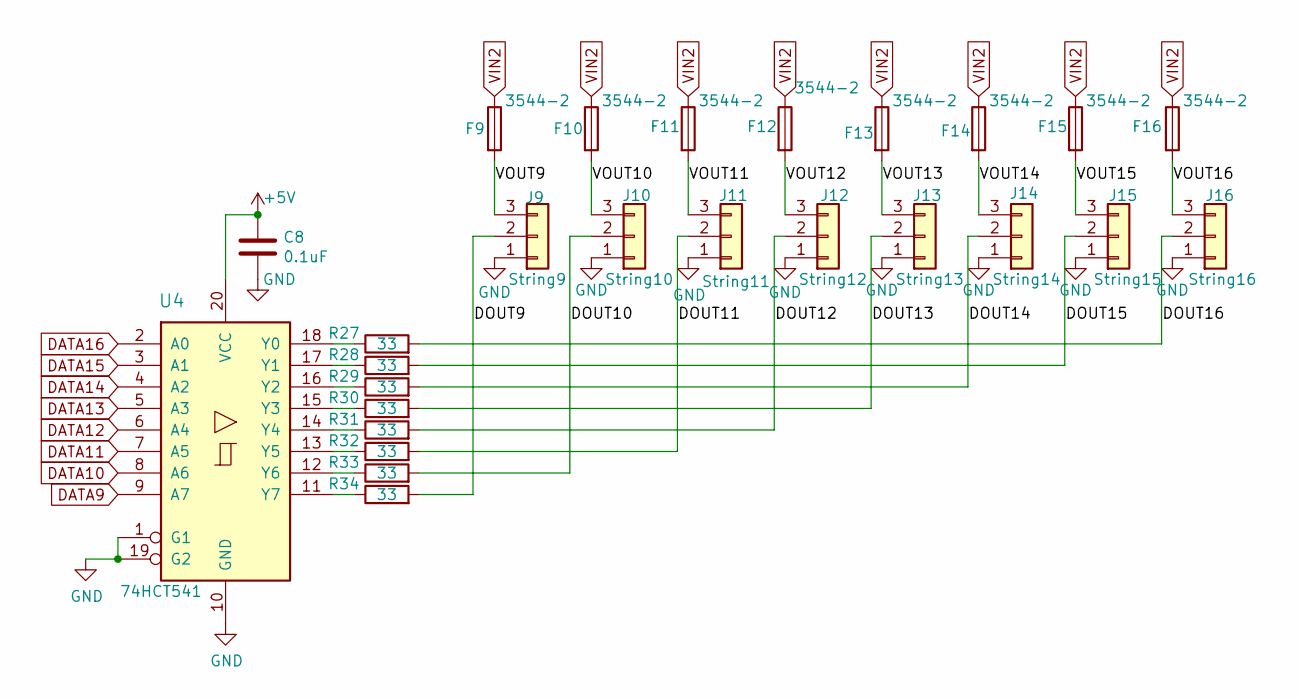
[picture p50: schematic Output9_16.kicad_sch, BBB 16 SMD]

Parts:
C8: 0.1uF; C_0603_1608Metric; MPN CL10B104KB8NNWC; Digi-Key_PN 1276-1935-2-ND
F9, F10, F11, F12, F13, F14, F15, F16: 3544-2; Fuse_1812_4532Metric; MPN 3544-2
J9: String9; DG250-3.5-03P; MPN 1843619/OSTTJ0311530
J10: String10; DG250-3.5-03P; MPN 1843619/OSTTJ0311530
J11: String11; DG250-3.5-03P; MPN 1843619/OSTTJ0311530
J12: String12; DG250-3.5-03P; MPN 1843619/OSTTJ0311530
J13: String13; DG250-3.5-03P; MPN 1843619/OSTTJ0311530
J14: String14; DG250-3.5-03P; MPN 1843619/OSTTJ0311530
J15: String15; DG250-3.5-03P; MPN 1843619/OSTTJ0311530
J16: String16; DG250-3.5-03P; MPN 1843619/OSTTJ0311530
R27, R28, R29, R30, R31, R32, R33, R34: 33; R_0603_1608Metric; MPN CN34J330CT; LCSC C23140
U4: 74HCT541; TSSOP-20_4.4x6.5mm_P0.65mm; MPN SN74HCT541PWR; Digi-Key_PN MC74HCT541ADTR2GOSTR-ND

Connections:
+5V: C8.1, U4.20 (VCC); also elsewhere on the board
/Output 9-16/DOUT9: J9.2, R34.2
/Output 9-16/DOUT10: J10.2, R33.2
/Output 9-16/DOUT11: J11.2, R32.2
/Output 9-16/DOUT12: J12.2, R31.2
/Output 9-16/DOUT13: J13.2, R30.2
/Output 9-16/DOUT14: J14.2, R29.2
/Output 9-16/DOUT15: J15.2, R28.2
/Output 9-16/DOUT16: J16.2, R27.2
/Output 9-16/VOUT9: F9.2, J9.3
/Output 9-16/VOUT10: F10.2, J10.3
/Output 9-16/VOUT11: F11.2, J11.3
/Output 9-16/VOUT12: F12.2, J12.3
/Output 9-16/VOUT13: F13.2, J13.3
/Output 9-16/VOUT14: F14.2, J14.3
/Output 9-16/VOUT15: F15.2, J15.3
/Output 9-16/VOUT16: F16.2, J16.3
DATA9: U4.9 (A7); also elsewhere on the board
DATA10: U4.8 (A6); also elsewhere on the board
DATA11: U4.7 (A5); also elsewhere on the board
DATA12: U4.6 (A4); also elsewhere on the board
DATA13: U4.5 (A3); also elsewhere on the board
DATA14: U4.4 (A2); also elsewhere on the board
DATA15: U4.3 (A1); also elsewhere on the board
DATA16: U4.2 (A0); also elsewhere on the board
GND: C8.2, J9.1, J10.1, J11.1, J12.1, J13.1, J14.1, J15.1, J16.1, U4.1 (G1), U4.10 (GND), U4.19 (G2); also elsewhere on the board
unnamed: R27.1, U4.18 (Y0)
unnamed: R28.1, U4.17 (Y1)
unnamed: R29.1, U4.16 (Y2)
unnamed: R30.1, U4.15 (Y3)
unnamed: R31.1, U4.14 (Y4)
unnamed: R32.1, U4.13 (Y5)
unnamed: R33.1, U4.12 (Y6)
unnamed: R34.1, U4.11 (Y7)
VIN2: F9.1, F10.1, F11.1, F12.1, F13.1, F14.1, F15.1, F16.1; also elsewhere on the board

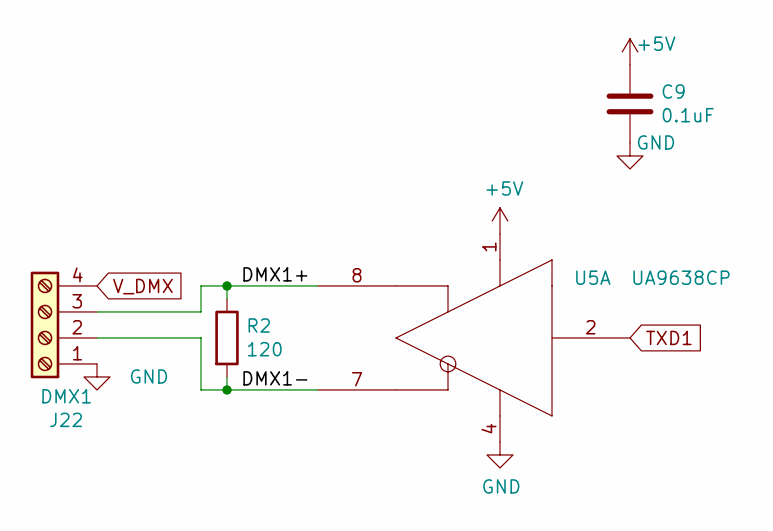
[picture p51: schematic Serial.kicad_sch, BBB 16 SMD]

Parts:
C9: 0.1uF; C_0603_1608Metric; MPN CL10B104KB8NNWC; Digi-Key_PN 1276-1935-2-ND
J22: DMX1; TerminalBlock_Phoenix_MKDS-1,5-4_1x04_P5.00mm_Horizontal; MPN 1729034; Digi-Key_PN 277-1238-ND
R2: 120; R_0603_1608Metric; MPN CRGCQ0603F120R; Digi-Key_PN A129677CT-ND
U5: UA9638CP; SOIC-8_3.9x4.9mm_P1.27mm; MPN UA9638CDR; Digi-Key_PN UA9638CP

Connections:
+5V: C9.1, U5.1 (VCC); also elsewhere on the board
/Serial/DMX1+: J22.3, R2.1, U5.8 (OUTB)
/Serial/DMX1-: J22.2, R2.2, U5.7 (OUTA)
GND: C9.2, J22.1, U5.4 (GND); also elsewhere on the board
TXD1: U5.2 (IN); also elsewhere on the board
V_DMX: J22.4; also elsewhere on the board

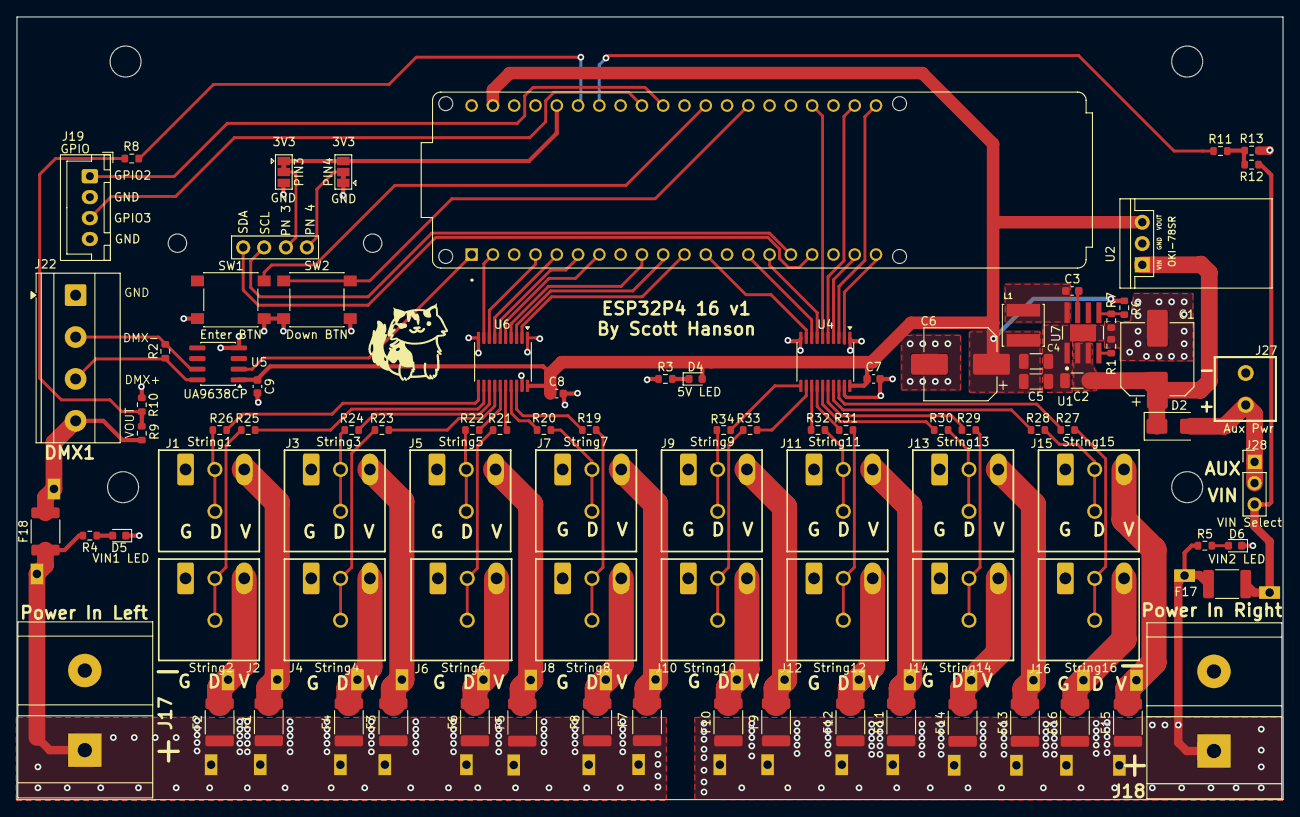
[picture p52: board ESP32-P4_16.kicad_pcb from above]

Board: 2 copper layers, 151.1 x 93.4 mm, 98 parts (0 on the bottom side), 95 nets.

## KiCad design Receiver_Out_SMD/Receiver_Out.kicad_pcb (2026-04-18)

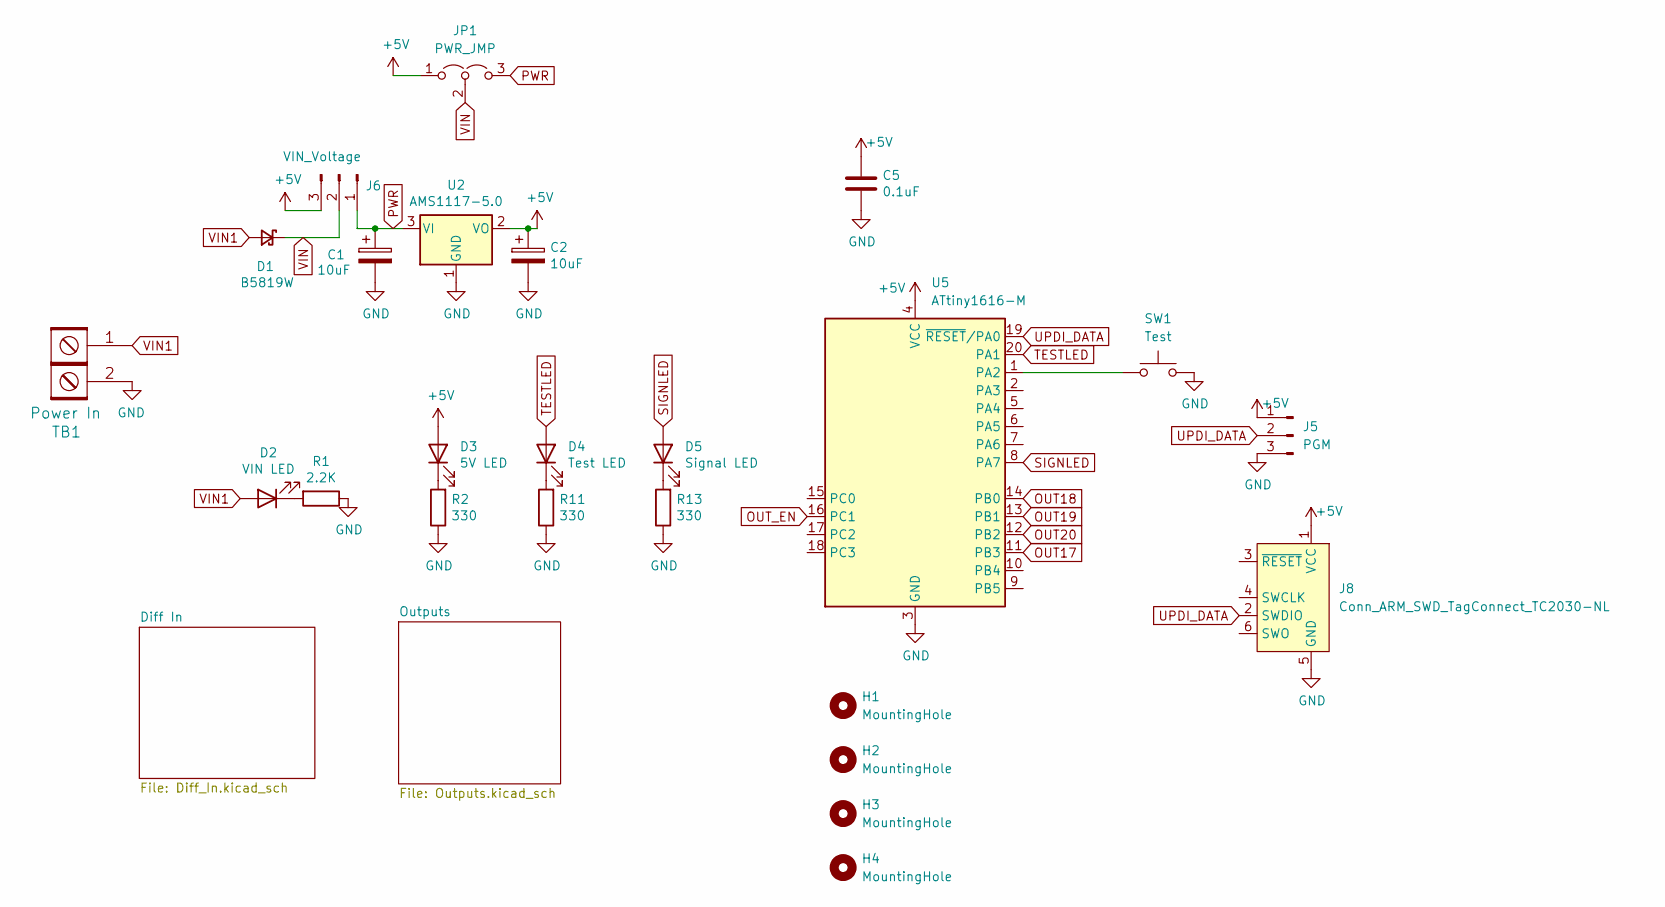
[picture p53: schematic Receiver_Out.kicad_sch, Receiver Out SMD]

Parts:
C1, C2: 10uF; C_0805_2012Metric; MPN GRM21BR61E106KA73L; Digi-Key_PN 490-5523-1-ND
C5: 0.1uF; C_0402_1005Metric; MPN 0402B104K160CT; Digi-Key_PN 1292-1630-1-ND
D1: B5819W; D_SOD-123; MPN B5819W-TP; LCSC_PN C8598
D2: VIN LED; LED_0603_1608Metric; MPN 150080RS75000; Digi-Key_PN 732-4984-1-ND
D3: 5V LED; LED_0603_1608Metric; MPN 150080RS75000; Digi-Key_PN 732-4984-1-ND
D4: Test LED; LED_0603_1608Metric; MPN 150080RS75000; Digi-Key_PN 732-4984-1-ND
D5: Signal LED; LED_0603_1608Metric; MPN 150080RS75000; Digi-Key_PN 732-4984-1-ND
H1, H2, H3, H4: MountingHole; MountingHole_3.7mm
J5: PGM; PinHeader_1x03_P2.54mm_Vertical
J6: VIN_Voltage; PinHeader_1x03_P2.54mm_Vertical; MPN 61300311121; Digi-Key_PN 732-5316-ND
J8: Conn_ARM_SWD_TagConnect_TC2030-NL; Tag-Connect_TC2030-IDC-NL_2x03_P1.27mm_Vertical
JP1: PWR_JMP; SolderJumper-3_P2.0mm_Open_TrianglePad1.0x1.5mm
R1: 2.2K; R_0603_1608Metric
R2, R11, R13: 330; R_0603_1608Metric; MPN CRGCQ0603F330R
SW1: Test; SW_Push_1P1T_NO_6x6mm_H9.5mm; MPN 222AMVBAR; LCSC C255812
TB1: Power In; BARRIER_BLOCK_1ROW_2POS; MPN 4DB-P108-02; Digi-Key_PN A98472-ND
U2: AMS1117-5.0; SOT-223-3_TabPin2; MPN LM1117MPX-50NOPB; LCSC_PN C6187
U5: ATtiny1616-M; VQFN-20-1EP_3x3mm_P0.4mm_EP1.7x1.7mm; MPN ATTINY1616-MNR; Digi-Key_PN ATTINY1616-MNRCT-ND

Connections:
+5V: C2.1, C5.1, D3.2 (A), J5.1, J6.3, J8.1 (VCC), JP1.1 (A), U2.2 (VO), U5.4 (VCC); also elsewhere on the board
GND: C1.2, C2.2, C5.2, J5.3, J8.5 (GND), R1.1, R2.1, R11.1, R13.1, SW1.2, TB1.2, U2.1 (GND), U5.3 (GND), U5.21 (GND); also elsewhere on the board
unnamed: D2.1 (K), R1.2
unnamed: D3.1 (K), R2.2
unnamed: D4.1 (K), R11.2
unnamed: D5.1 (K), R13.2
unnamed: SW1.1, U5.1 (PA2)
OUT17: U5.11 (PB3); also elsewhere on the board
OUT18: U5.14 (PB0); also elsewhere on the board
OUT19: U5.13 (PB1); also elsewhere on the board
OUT20: U5.12 (PB2); also elsewhere on the board
OUT_EN: U5.16 (PC1); also elsewhere on the board
PWR: C1.1, J6.1, JP1.3 (B), U2.3 (VI)
SIGNLED: D5.2 (A), U5.8 (PA7)
TESTLED: D4.2 (A), U5.20 (PA1)
UPDI_DATA: J5.2, J8.2 (SWDIO), U5.19 (~RESET/PA0)
VIN: D1.1 (K), J6.2, JP1.2 (C)
VIN1: D1.2 (A), D2.2 (A), TB1.1; also elsewhere on the board

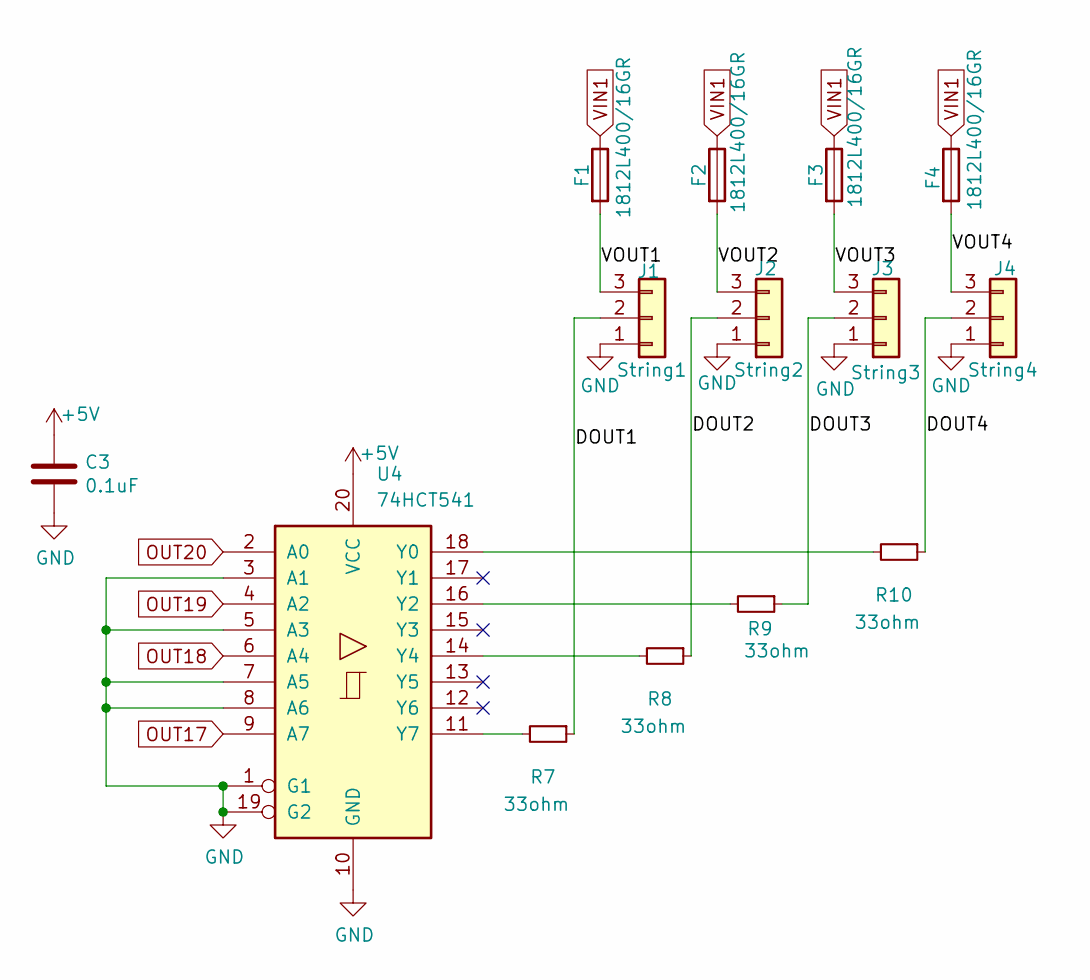
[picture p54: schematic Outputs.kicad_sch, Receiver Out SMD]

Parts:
C3: 0.1uF; C_0402_1005Metric; MPN 0402B104K160CT; Digi-Key_PN 1292-1630-1-ND
F1, F2, F3, F4: 1812L400/16GR; Fuse_1812_4532Metric; MPN 3544-2; Digi-Key_PN 36-3544-2-ND
J1: String1; DG250-3.5-03P; MPN 1843619/OSTTJ0311530; Digi-Key_PN 277-5737-ND/ED10555-ND
J2: String2; DG250-3.5-03P; MPN 1843619/OSTTJ0311530; Digi-Key_PN 277-5737-ND/ED10555-ND
J3: String3; DG250-3.5-03P; MPN 1843619/OSTTJ0311530; Digi-Key_PN 277-5737-ND/ED10555-ND
J4: String4; DG250-3.5-03P; MPN 1843619/OSTTJ0311530; Digi-Key_PN 277-5737-ND/ED10555-ND
R7, R8, R9, R10: 33ohm; R_0603_1608Metric; MPN RC0603JR-0733RL; LCSC_PN C23140
U4: 74HCT541; TSSOP-20_4.4x6.5mm_P0.65mm; MPN 74HCT541PW,118; LCSC C436096

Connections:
+5V: C3.1, U4.20 (VCC); also elsewhere on the board
/Outputs/DOUT1: J1.2, R7.1
/Outputs/DOUT2: J2.2, R8.1
/Outputs/DOUT3: J3.2, R9.1
/Outputs/DOUT4: J4.2, R10.1
/Outputs/VOUT1: F1.2, J1.3
/Outputs/VOUT2: F2.2, J2.3
/Outputs/VOUT3: F3.2, J3.3
/Outputs/VOUT4: F4.2, J4.3
GND: C3.2, J1.1, J2.1, J3.1, J4.1, U4.1 (G1), U4.3 (A1), U4.5 (A3), U4.7 (A5), U4.8 (A6), U4.10 (GND), U4.19 (G2); also elsewhere on the board
unnamed: R10.2, U4.18 (Y0)
unnamed: R9.2, U4.16 (Y2)
unnamed: R8.2, U4.14 (Y4)
unnamed: R7.2, U4.11 (Y7)
OUT17: U4.9 (A7); also elsewhere on the board
OUT18: U4.6 (A4); also elsewhere on the board
OUT19: U4.4 (A2); also elsewhere on the board
OUT20: U4.2 (A0); also elsewhere on the board
VIN1: F1.1, F2.1, F3.1, F4.1; also elsewhere on the board

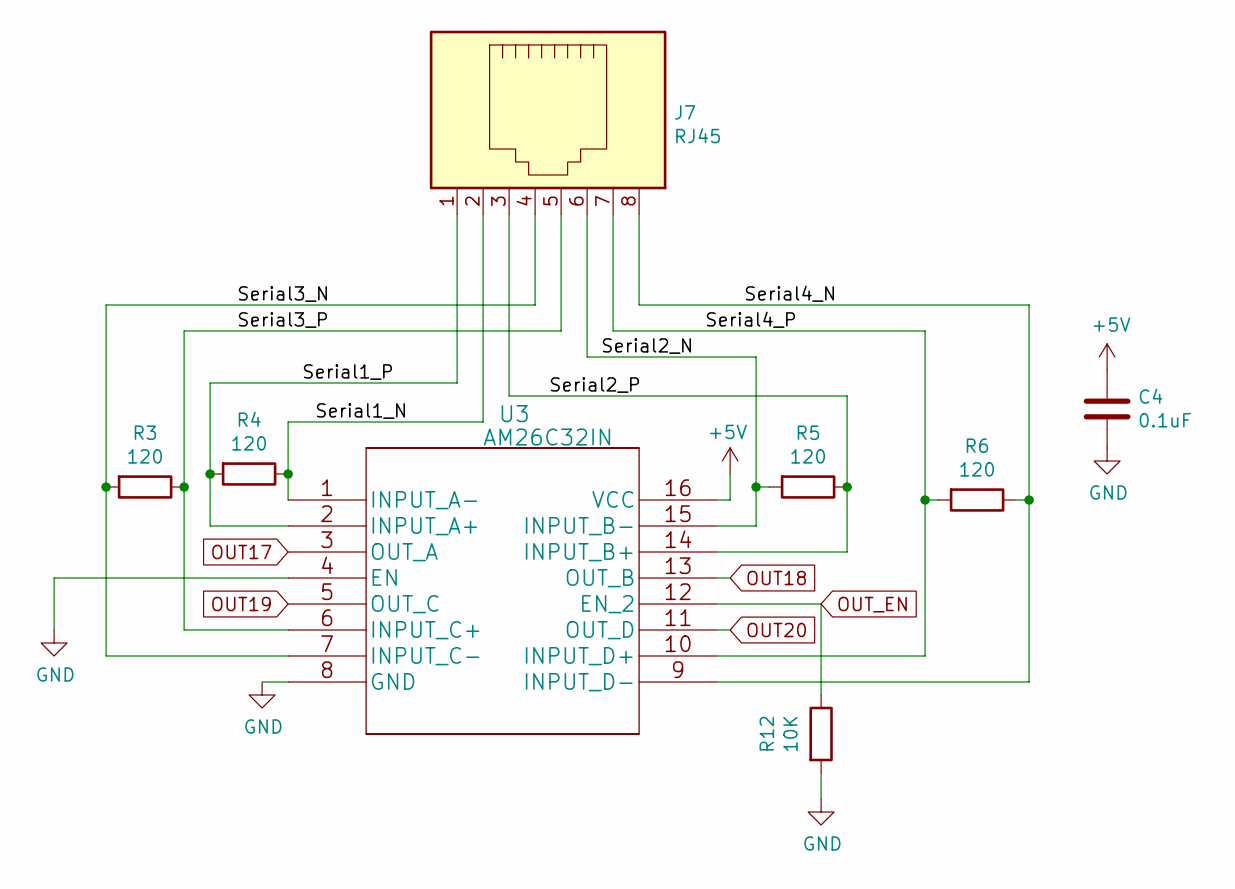
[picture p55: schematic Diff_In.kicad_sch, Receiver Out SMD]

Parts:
C4: 0.1uF; C_0402_1005Metric; MPN 0402B104K160CT; Digi-Key_PN 1292-1630-1-ND
J7: RJ45; RJ45_Amphenol_54602-x08_Horizontal; MPN A-2014-2-4-R; Digi-Key_PN AE10392-ND
R3, R4, R5, R6: 120; R_0603_1608Metric; MPN CRGCQ0603F120R; LCSC_PN C22787
R12: 10K; R_0603_1608Metric; MPN RC0603FR-0710KL; LCSC_PN C25804
U3: AM26C32IN; SOIC-16_3.9x9.9mm_P1.27mm; MPN AM26C32INSR; Digi-Key_PN 296-37322-1-ND

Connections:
+5V: C4.1, U3.16 (VCC); also elsewhere on the board
/Diff In/Serial1_N: J7.2, R4.1, U3.1 (INPUT_A-)
/Diff In/Serial1_P: J7.1, R4.2, U3.2 (INPUT_A+)
/Diff In/Serial2_N: J7.6, R5.2, U3.15 (INPUT_B-)
/Diff In/Serial2_P: J7.3, R5.1, U3.14 (INPUT_B+)
/Diff In/Serial3_N: J7.4, R3.2, U3.7 (INPUT_C-)
/Diff In/Serial3_P: J7.5, R3.1, U3.6 (INPUT_C+)
/Diff In/Serial4_N: J7.8, R6.1, U3.9 (INPUT_D-)
/Diff In/Serial4_P: J7.7, R6.2, U3.10 (INPUT_D+)
GND: C4.2, R12.2, U3.4 (EN), U3.8 (GND); also elsewhere on the board
OUT17: U3.3 (OUT_A); also elsewhere on the board
OUT18: U3.13 (OUT_B); also elsewhere on the board
OUT19: U3.5 (OUT_C); also elsewhere on the board
OUT20: U3.11 (OUT_D); also elsewhere on the board
OUT_EN: R12.1, U3.12 (EN_2); also elsewhere on the board

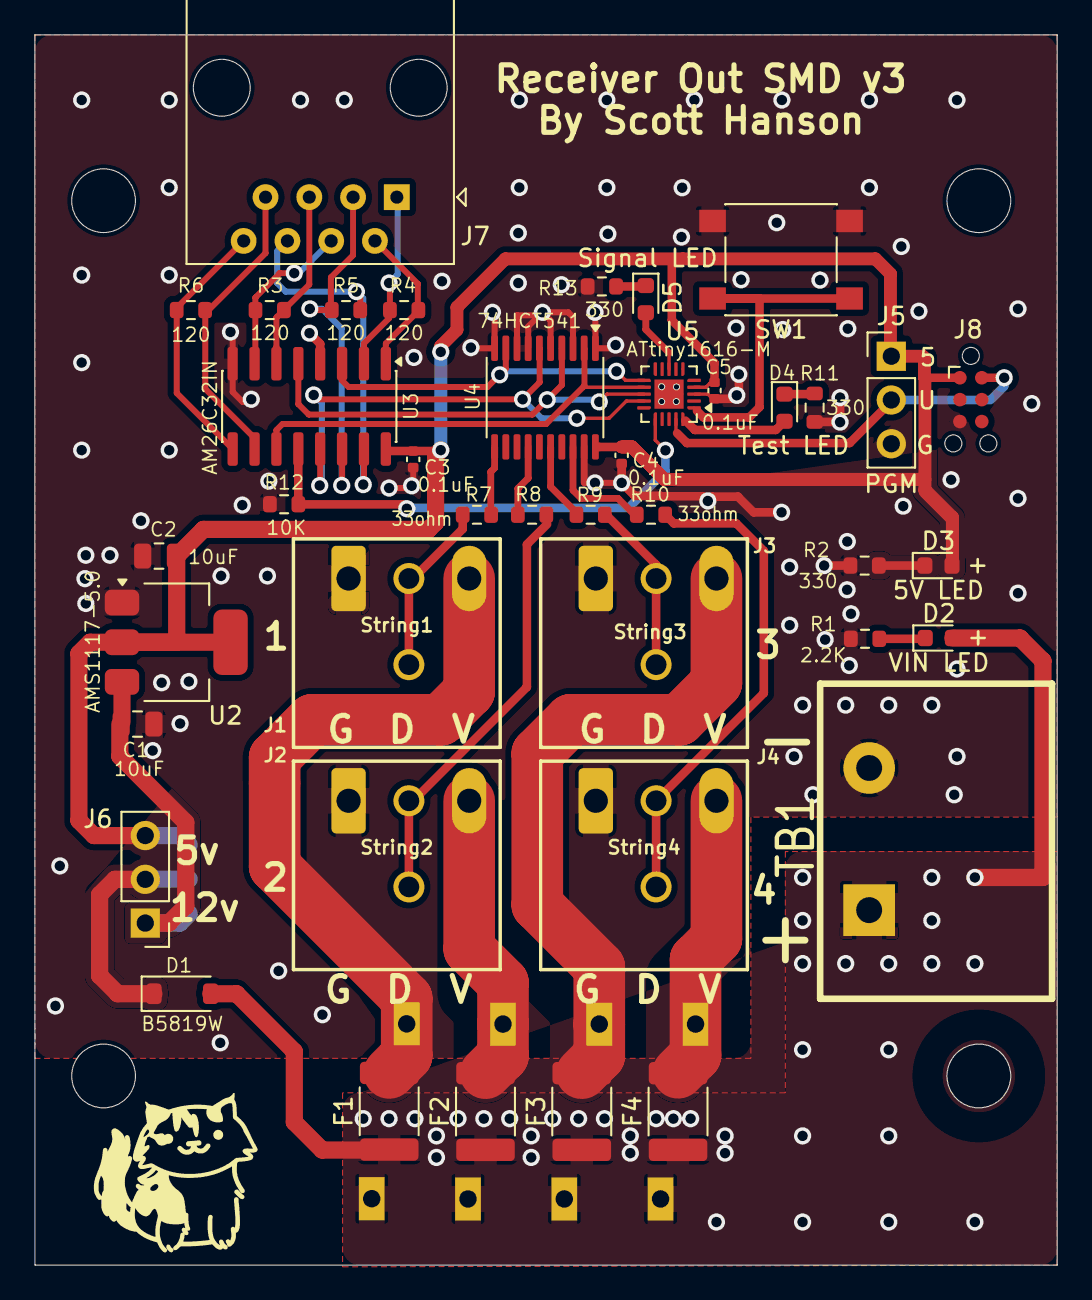
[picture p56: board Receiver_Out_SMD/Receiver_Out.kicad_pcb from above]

Board: 2 copper layers, 59.3 x 71.4 mm, 46 parts (1 on the bottom side), 38 nets.

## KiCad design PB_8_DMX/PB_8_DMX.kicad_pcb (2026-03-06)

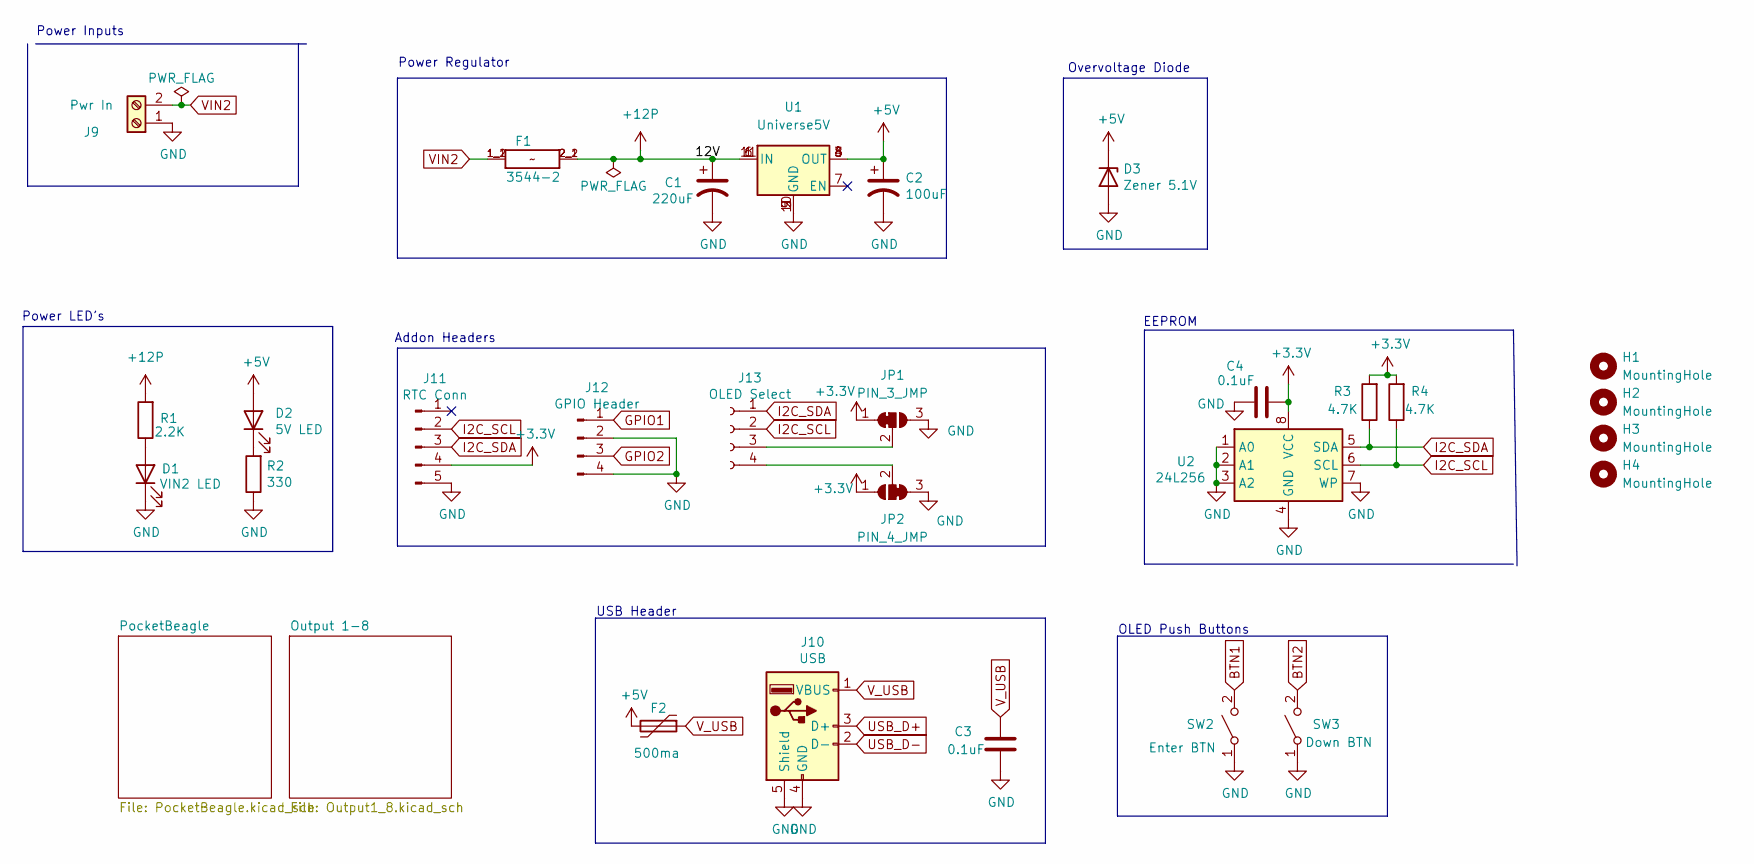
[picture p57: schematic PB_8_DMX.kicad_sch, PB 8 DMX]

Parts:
C1: 220uF; CP_Radial_D10.0mm_P5.00mm; MPN ECA-1HM221; Digi-Key_PN P5183-ND
C2: 100uF; CP_Radial_D5.0mm_P2.00mm; MPN 16ZLH100MEFC5X11; Digi-Key_PN 1189-1148-ND
C3, C4: 0.1uF; C_Rect_L7.0mm_W2.0mm_P5.00mm; MPN SR215C104KARTR1; Digi-Key_PN 478-7336-1-ND
D1: VIN2 LED; LED_D3.0mm_Clear; MPN WP3A8GD; Digi-Key_PN 754-1217-ND
D2: 5V LED; LED_D3.0mm_Clear; MPN WP3A8GD; Digi-Key_PN 754-1217-ND
D3: Zener 5.1V; D_5W_P10.16mm_Horizontal; MPN 1N5338BRLG; Digi-Key_PN 1N5338BRLGOSCT-ND
F1: 3544-2; FUSE_3544-2; MPN 3544-2; Digi-Key_PN 36-3544-2-ND
F2: 500ma; Fuse_BelFuse_0ZRE0005FF_L8.3mm_W3.8mm; MPN RXEF050-2; Digi-Key_PN RXEF050-2HFCT-ND
H1, H2, H3, H4: MountingHole; MountingHole_3.7mm
J9: Pwr In; TerminalBlock_Phoenix_MKDS-1,5-2_1x02_P5.00mm_Horizontal; MPN 1727010; Digi-Key_PN 277-1947-ND
J10: USB; USB_A_Molex_105057_Vertical; MPN 1050570001; Digi-Key_PN WM8672-ND
J11: RTC Conn; PinHeader_1x05_P2.54mm_Vertical; MPN 61300511121; Digi-Key_PN 732-5318-ND
J12: GPIO Header; JST_XH_B4B-XH-A_1x04_P2.50mm_Vertical; MPN B4B-XH-A(LF)(SN); Digi-Key_PN 455-2249-ND
J13: OLED Select; PinSocket_1x04_P2.54mm_Vertical; MPN PPTC041LFBN-RC; Digi-Key_PN S7002-ND
JP1: PIN_3_JMP; SolderJumper-3_P1mm_Bridged12
JP2: PIN_4_JMP; SolderJumper-3_P1mm_Bridged23
R1: 2.2K; R_Axial_DIN0207_L6.3mm_D2.5mm_P7.62mm_Horizontal; MPN CF14JT2K20; Digi-Key_PN CF14JT2K20CT-ND
R2: 330; R_Axial_DIN0207_L6.3mm_D2.5mm_P7.62mm_Horizontal; MPN CF14JT330R; Digi-Key_PN CF14JT330RCT-ND
R3, R4: 4.7K; R_Axial_DIN0207_L6.3mm_D2.5mm_P7.62mm_Horizontal; MPN CF14JT4K70; Digi-Key_PN CF14JT4K70CT-ND
SW2: Enter BTN; SW_PUSH_6mm; MPN 1825910-6; Digi-Key_PN 450-1650-ND
SW3: Down BTN; SW_PUSH_6mm; MPN 1825910-6; Digi-Key_PN 450-1650-ND
U1: Universe5V; Universal_5V_Horizontal; MPN OKI-78SR-5/1.5-W36-C; Digi-Key_PN 811-2196-5-ND
U2: 24L256; DIP-8_W7.62mm; MPN FT24C256A-UDR-B; Digi-Key_PN 1219-1052-ND

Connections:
+3.3V: C4.1, J11.4, JP1.1 (A), JP2.1 (A), R3.2, R4.2, U2.8 (VCC); also elsewhere on the board
+5V: C2.1, D2.2 (A), D3.1 (K), F2.2, U1.3 (OUT), U1.4 (OUT), U1.8 (OUT); also elsewhere on the board
+12P: C1.1, F1.2_1 (2), F1.2_2 (2), R1.2, U1.1 (IN), U1.6 (IN), U1.11 (IN)
BTN1: SW2.2 (B); also elsewhere on the board
BTN2: SW3.2 (B); also elsewhere on the board
GND: C1.2, C2.2, C3.2, C4.2, D1.1 (K), D3.2 (A), J9.1, J10.4 (GND), J10.5 (Shield), J11.5, J12.2, J12.4, JP1.3 (B), JP2.3 (B), R2.1, SW2.1 (A), SW3.1 (A), U1.2 (GND), U1.5 (GND), U1.9 (GND), U1.10 (GND), U2.1 (A0), U2.2 (A1), U2.3 (A2), U2.4 (GND), U2.7 (WP); also elsewhere on the board
GPIO1: J12.1; also elsewhere on the board
GPIO2: J12.3; also elsewhere on the board
I2C_SCL: J11.2, J13.2, R4.1, U2.6 (SCL); also elsewhere on the board
I2C_SDA: J11.3, J13.1, R3.1, U2.5 (SDA); also elsewhere on the board
unnamed: D1.2 (A), R1.1
unnamed: D2.1 (K), R2.2
unnamed: J13.3, JP1.2 (C)
unnamed: J13.4, JP2.2 (C)
USB_D+: J10.3 (D+); also elsewhere on the board
USB_D-: J10.2 (D-); also elsewhere on the board
VIN2: F1.1_1 (1), F1.1_2 (1), J9.2
V_USB: C3.1, F2.1, J10.1 (VBUS); also elsewhere on the board

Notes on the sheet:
Overvoltage Diode
EEPROM
USB Header
OLED Push Buttons
Addon Headers
Power Regulator
Power LED's
Power Inputs

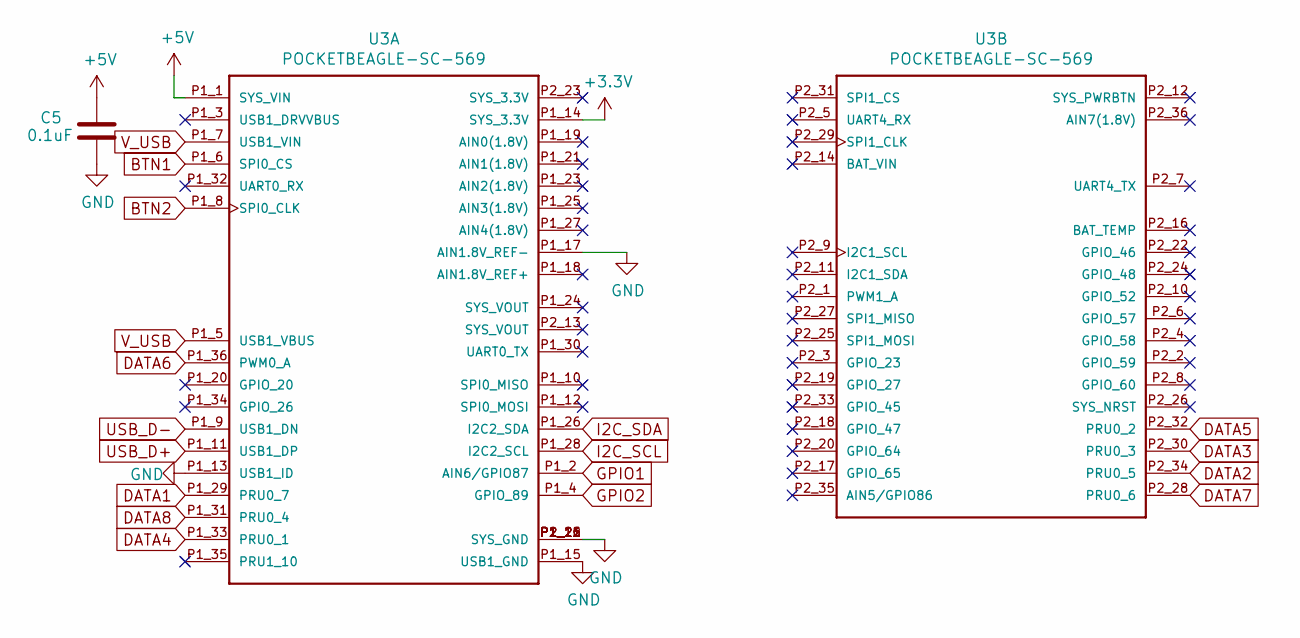
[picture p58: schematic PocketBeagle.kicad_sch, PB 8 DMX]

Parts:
C5: 0.1uF; C_Rect_L7.0mm_W2.0mm_P5.00mm; MPN SR215C104KARTR1; Digi-Key_PN 478-7336-1-ND
U3: POCKETBEAGLE-SC-569; BEAGLE_POCKETBEAGLE-SC-569; MPN POCKETBEAGLE-SC-569; Digi-Key_PN POCKETBEAGLE-SC-569-ND

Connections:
+3.3V: U3.P1_14 (SYS_3.3V); also elsewhere on the board
+5V: C5.1, U3.P1_1 (SYS_VIN); also elsewhere on the board
BTN1: U3.P1_6 (SPI0_CS); also elsewhere on the board
BTN2: U3.P1_8 (SPI0_CLK); also elsewhere on the board
DATA1: U3.P1_29 (PRU0_7); also elsewhere on the board
DATA2: U3.P2_34 (PRU0_5); also elsewhere on the board
DATA3: U3.P2_30 (PRU0_3); also elsewhere on the board
DATA4: U3.P1_33 (PRU0_1); also elsewhere on the board
DATA5: U3.P2_32 (PRU0_2); also elsewhere on the board
DATA6: U3.P1_36 (PWM0_A); also elsewhere on the board
DATA7: U3.P2_28 (PRU0_6); also elsewhere on the board
DATA8: U3.P1_31 (PRU0_4); also elsewhere on the board
GND: C5.2, U3.P1_13 (USB1_ID), U3.P1_15 (USB1_GND), U3.P1_16 (SYS_GND), U3.P1_17 (AIN1.8V_REF-), U3.P1_22 (SYS_GND), U3.P2_15 (SYS_GND), U3.P2_21 (SYS_GND); also elsewhere on the board
GPIO1: U3.P1_2 (AIN6/GPIO87); also elsewhere on the board
GPIO2: U3.P1_4 (GPIO_89); also elsewhere on the board
I2C_SCL: U3.P1_28 (I2C2_SCL); also elsewhere on the board
I2C_SDA: U3.P1_26 (I2C2_SDA); also elsewhere on the board
USB_D+: U3.P1_11 (USB1_DP); also elsewhere on the board
USB_D-: U3.P1_9 (USB1_DN); also elsewhere on the board
V_USB: U3.P1_5 (USB1_VBUS), U3.P1_7 (USB1_VIN); also elsewhere on the board


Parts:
C6, C7: 0.1uF; C_Rect_L7.0mm_W2.0mm_P5.00mm; MPN SR215C104KARTR1; Digi-Key_PN 478-7336-1-ND
IC1, IC2: AM26C31; DIP-16_W7.62mm; MPN 4975637; Farnell 4975637
J1: String1; PhoenixContact_MCV_1,5_3-G-3.5_1x03_P3.50mm_Vertical; MPN 1843619/OSTTJ0311530; Digi-Key_PN 277-5737-ND/ED10555-ND
J2: String2; PhoenixContact_MCV_1,5_3-G-3.5_1x03_P3.50mm_Vertical; MPN 1843619/OSTTJ0311530; Digi-Key_PN 277-5737-ND/ED10555-ND
J3: String3; PhoenixContact_MCV_1,5_3-G-3.5_1x03_P3.50mm_Vertical; MPN 1843619/OSTTJ0311530; Digi-Key_PN 277-5737-ND/ED10555-ND
J4: String4; PhoenixContact_MCV_1,5_3-G-3.5_1x03_P3.50mm_Vertical; MPN 1843619/OSTTJ0311530; Digi-Key_PN 277-5737-ND/ED10555-ND
J5: String5; PhoenixContact_MCV_1,5_3-G-3.5_1x03_P3.50mm_Vertical; MPN 1843619/OSTTJ0311530; Digi-Key_PN 277-5737-ND/ED10555-ND
J6: String6; PhoenixContact_MCV_1,5_3-G-3.5_1x03_P3.50mm_Vertical; MPN 1843619/OSTTJ0311530; Digi-Key_PN 277-5737-ND/ED10555-ND
J7: String7; PhoenixContact_MCV_1,5_3-G-3.5_1x03_P3.50mm_Vertical; MPN 1843619/OSTTJ0311530; Digi-Key_PN 277-5737-ND/ED10555-ND
J8: String8; PhoenixContact_MCV_1,5_3-G-3.5_1x03_P3.50mm_Vertical; MPN 1843619/OSTTJ0311530; Digi-Key_PN 277-5737-ND/ED10555-ND
R5, R6, R7, R8, R9, R10, R11, R12: 120; R_Axial_DIN0207_L6.3mm_D2.5mm_P7.62mm_Horizontal; MPN CF14JT120R; Digi-Key_PN CF14JT120RCT-ND

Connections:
+5V: C6.1, C7.1, IC1.16 (VCC), IC2.16 (VCC); also elsewhere on the board
/Output 1-8/DMX1+: IC1.14 (4Y), J1.3, R8.1
/Output 1-8/DMX1-: IC1.13 (4Z), J1.2, R8.2
/Output 1-8/DMX2+: IC1.2 (1Y), J2.3, R5.1
/Output 1-8/DMX2-: IC1.3 (1Z), J2.2, R5.2
/Output 1-8/DMX3+: IC1.10 (3Y), J3.3, R7.1
/Output 1-8/DMX3-: IC1.11 (3Z), J3.2, R7.2
/Output 1-8/DMX4+: IC1.6 (2Y), J4.3, R6.1
/Output 1-8/DMX4-: IC1.5 (2Z), J4.2, R6.2
/Output 1-8/DMX5+: IC2.14 (4Y), J5.3, R12.1
/Output 1-8/DMX5-: IC2.13 (4Z), J5.2, R12.2
/Output 1-8/DMX6+: IC2.2 (1Y), J6.3, R9.1
/Output 1-8/DMX6-: IC2.3 (1Z), J6.2, R9.2
/Output 1-8/DMX7+: IC2.10 (3Y), J7.3, R11.1
/Output 1-8/DMX7-: IC2.11 (3Z), J7.2, R11.2
/Output 1-8/DMX8+: IC2.6 (2Y), J8.3, R10.1
/Output 1-8/DMX8-: IC2.5 (2Z), J8.2, R10.2
DATA1: IC1.15 (4A); also elsewhere on the board
DATA2: IC1.1 (1A); also elsewhere on the board
DATA3: IC1.9 (3A); also elsewhere on the board
DATA4: IC1.7 (2A); also elsewhere on the board
DATA5: IC2.15 (4A); also elsewhere on the board
DATA6: IC2.1 (1A); also elsewhere on the board
DATA7: IC2.9 (3A); also elsewhere on the board
DATA8: IC2.7 (2A); also elsewhere on the board
GND: C6.2, C7.2, IC1.8 (GND), IC1.12 (~G), IC2.8 (GND), IC2.12 (~G), J1.1, J2.1, J3.1, J4.1, J5.1, J6.1, J7.1, J8.1; also elsewhere on the board


Board: 2 copper layers, 93.0 x 87.7 mm, 50 parts (0 on the bottom side), 42 nets.

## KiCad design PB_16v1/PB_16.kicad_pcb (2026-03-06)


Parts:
C1: 220uF; CP_Radial_D10.0mm_P5.00mm; MPN ECA-1HM221; Digi-Key_PN P5183-ND
C2: 100uF; CP_Radial_D5.0mm_P2.00mm; MPN 16ZLH100MEFC5X11; Digi-Key_PN 1189-1148-ND
C6, C8: 0.1uF; C_Rect_L7.0mm_W2.0mm_P5.00mm; MPN SR215C104KARTR1; Digi-Key_PN 478-7336-1-ND
D1, D2: SB5100-T; D_DO-201AD_P12.70mm_Horizontal; MPN SB5100-T; Digi-Key_PN SB5100DICT-ND
D3: Zener 5.1V; D_5W_P10.16mm_Horizontal; MPN 1N5338BRLG; Digi-Key_PN 1N5338BRLGOSCT-ND
D4: 5V LED; LED_D3.0mm_Clear; MPN WP3A8GD; Digi-Key_PN 754-1217-ND
D5: VIN1 LED; LED_D3.0mm_Clear; MPN WP3A8GD; Digi-Key_PN 754-1217-ND
D6: VIN2 LED; LED_D3.0mm_Clear; MPN WP3A8GD; Digi-Key_PN 754-1217-ND
F17: 3544-2; FUSE_3544-2; MPN 3544-2; Digi-Key_PN 36-3544-2-ND
F19: 500ma; Fuse_BelFuse_0ZRE0005FF_L8.3mm_W3.8mm; MPN RXEF050-2; Digi-Key_PN RXEF050-2HFCT-ND
H1, H2, H3, H4: MountingHole; MountingHole_3.7mm
J17: Power In Left; BARRIER_BLOCK_1ROW_2POS_P9.5MM; MPN OSTYK51102030; Digi-Key_PN ED2953-ND
J18: Power In Right; BARRIER_BLOCK_1ROW_2POS_P9.5MM; MPN OSTYK51102030; Digi-Key_PN ED2953-ND
J19: USB; USB_A_Molex_105057_Vertical; MPN 1050570001; Digi-Key_PN WM8672-ND
J23: VIN Voltage; PinHeader_1x03_P2.54mm_Vertical; MPN 61300311121; Digi-Key_PN 732-5316-ND
J24: Expansion Header; IDC-Header_2x12_P2.54mm_Vertical; MPN SBH11-PBPC-D20-ST-BK; Digi-Key_PN S9175-ND
J25: RTC Conn; PinHeader_1x05_P2.54mm_Vertical; MPN 61300511121; Digi-Key_PN 732-5318-ND
J26: OLED Select; PinSocket_1x04_P2.54mm_Vertical; MPN PPTC041LFBN-RC; Digi-Key_PN S7002-ND
J27: GPIO Header; JST_XH_B4B-XH-A_1x04_P2.50mm_Vertical; MPN B4B-XH-A(LF)(SN); Digi-Key_PN 455-2249-ND
J28: Aux Pwr; PHOENIX_MKDS1_2-3.81; MPN 1727010; Digi-Key_PN 277-1947-ND
J29: VIN Select; PinHeader_1x03_P2.54mm_Vertical; MPN 61300311121; Digi-Key_PN 732-5316-ND
JP1: PIN_3_JMP; SolderJumper-3_P1mm_Bridged12
JP2: PIN_4_JMP; SolderJumper-3_P1mm_Bridged23
R3: 120; R_Axial_DIN0207_L6.3mm_D2.5mm_P7.62mm_Horizontal; MPN CF14JT120R; Digi-Key_PN CF14JT120RCT-ND
R4, R5: 1K; R_Axial_DIN0207_L6.3mm_D2.5mm_P7.62mm_Horizontal; MPN CF14JT1K00; Digi-Key_PN CF14JT1K00CT-ND
R6, R7: 4.7K; R_Axial_DIN0207_L6.3mm_D2.5mm_P7.62mm_Horizontal; MPN CF14JT4K70; Digi-Key_PN CF14JT4K70CT-ND
SW4: Enter BTN; SW_PUSH_6mm; MPN 1825910-6; Digi-Key_PN 450-1650-ND
SW5: Down BTN; SW_PUSH_6mm; MPN 1825910-6; Digi-Key_PN 450-1650-ND
U2: Universe5V; Universal_5V_Horizontal
U6: 24L256; DIP-8_W7.62mm; MPN FT24C256A-UDR-B; Digi-Key_PN 1219-1052-ND

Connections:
+3V3: C8.1, J25.4, JP1.1 (A), JP2.1 (A), R6.2, R7.2, U6.8 (VCC); also elsewhere on the board
+5V: C2.1, D3.1 (K), D4.2 (A), F19.2, J23.3, J24.3, J24.4, U2.3 (OUT), U2.4 (OUT), U2.8 (OUT); also elsewhere on the board
/12V: C1.1, J23.1, U2.1 (IN), U2.6 (IN), U2.11 (IN)
/OLED_Pin_3: J26.3, JP1.2 (C)
/OLED_Pin_4: J26.4, JP2.2 (C)
/VIN: J23.2, J28.1, J29.1, J29.2
/VIN_Fuse: F17.2_1 (2), F17.2_2 (2), J29.3
BTN1: SW4.2 (B); also elsewhere on the board
BTN2: SW5.2 (B); also elsewhere on the board
GND: C1.2, C2.2, C6.2, C8.2, D1.2 (A), D2.2 (A), D3.2 (A), D5.1 (K), D6.1 (K), J17.1, J18.2, J19.4 (GND), J19.5 (Shield), J24.1, J24.2, J24.22, J25.5, J27.2, J27.4, J28.2, JP1.3 (B), JP2.3 (B), R3.1, SW4.1 (A), SW5.1 (A), U2.2 (GND), U2.5 (GND), U2.9 (GND), U2.10 (GND), U6.1 (A0), U6.2 (A1), U6.3 (A2), U6.4 (GND), U6.7 (WP); also elsewhere on the board
GPIO1: J27.1; also elsewhere on the board
GPIO2: J27.3; also elsewhere on the board
I2C_SCL: J25.2, J26.2, R7.1, U6.6 (SCL); also elsewhere on the board
I2C_SDA: J25.3, J26.1, R6.1, U6.5 (SDA); also elsewhere on the board
unnamed: D4.1 (K), R3.2
unnamed: D5.2 (A), R4.1
unnamed: D6.2 (A), R5.1
OUT17: J24.5; also elsewhere on the board
OUT18: J24.6; also elsewhere on the board
OUT19: J24.7; also elsewhere on the board
OUT20: J24.8; also elsewhere on the board
OUT21: J24.9; also elsewhere on the board
OUT22: J24.10; also elsewhere on the board
OUT23: J24.11; also elsewhere on the board
OUT24: J24.12; also elsewhere on the board
OUT25: J24.13; also elsewhere on the board
OUT26: J24.14; also elsewhere on the board
OUT27: J24.15; also elsewhere on the board
OUT28: J24.16; also elsewhere on the board
OUT29: J24.17; also elsewhere on the board
OUT30: J24.18; also elsewhere on the board
OUT31: J24.19; also elsewhere on the board
OUT32: J24.20; also elsewhere on the board
USB_D+: J19.3 (D+); also elsewhere on the board
USB_D-: J19.2 (D-); also elsewhere on the board
VIN1: D1.1 (K), J17.2, R4.2; also elsewhere on the board
VIN2: D2.1 (K), F17.1_1 (1), F17.1_2 (1), J18.1, R5.2; also elsewhere on the board
V_USB: C6.1, F19.1, J19.1 (VBUS); also elsewhere on the board

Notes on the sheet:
Overvoltage Diode
EEPROM
USB Header
OLED Push Buttons
Reverse Protection Diodes
Addon Headers
Power Regulator
Power LED's
Power Inputs


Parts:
C7: 0.1uF; C_Rect_L7.0mm_W2.0mm_P5.00mm; MPN SR215C104KARTR1; Digi-Key_PN 478-7336-1-ND
U1: POCKETBEAGLE-SC-569; BEAGLE_POCKETBEAGLE-SC-569; MPN POCKETBEAGLE-SC-569; Digi-Key_PN POCKETBEAGLE-SC-569-ND

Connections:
+3V3: U1.P1_14 (SYS_3.3V); also elsewhere on the board
+5V: C7.1, U1.P1_1 (SYS_VIN); also elsewhere on the board
BTN1: U1.P1_6 (SPI0_CS); also elsewhere on the board
BTN2: U1.P1_8 (SPI0_CLK); also elsewhere on the board
DATA1: U1.P2_22 (GPIO_46); also elsewhere on the board
DATA2: U1.P2_18 (GPIO_47); also elsewhere on the board
DATA3: U1.P2_10 (GPIO_52); also elsewhere on the board
DATA4: U1.P2_8 (GPIO_60); also elsewhere on the board
DATA5: U1.P2_6 (GPIO_57); also elsewhere on the board
DATA6: U1.P2_4 (GPIO_58); also elsewhere on the board
DATA7: U1.P2_2 (GPIO_59); also elsewhere on the board
DATA8: U1.P2_1 (PWM1_A); also elsewhere on the board
DATA9: U1.P2_24 (GPIO_48); also elsewhere on the board
DATA10: U1.P2_25 (SPI1_MOSI); also elsewhere on the board
DATA11: U1.P2_27 (SPI1_MISO); also elsewhere on the board
DATA12: U1.P2_33 (GPIO_45); also elsewhere on the board
DATA13: U1.P1_29 (PRU0_7); also elsewhere on the board
DATA14: U1.P2_34 (PRU0_5); also elsewhere on the board
DATA15: U1.P2_30 (PRU0_3); also elsewhere on the board
DATA16: U1.P1_33 (PRU0_1); also elsewhere on the board
GND: C7.2, U1.P1_13 (USB1_ID), U1.P1_15 (USB1_GND), U1.P1_16 (SYS_GND), U1.P1_17 (AIN1.8V_REF-), U1.P1_22 (SYS_GND), U1.P2_15 (SYS_GND), U1.P2_21 (SYS_GND); also elsewhere on the board
GPIO1: U1.P1_2 (AIN6/GPIO87); also elsewhere on the board
GPIO2: U1.P1_4 (GPIO_89); also elsewhere on the board
I2C_SCL: U1.P1_28 (I2C2_SCL); also elsewhere on the board
I2C_SDA: U1.P1_26 (I2C2_SDA); also elsewhere on the board
OUT17: U1.P1_31 (PRU0_4); also elsewhere on the board
OUT18: U1.P1_35 (PRU1_10); also elsewhere on the board
OUT19: U1.P1_34 (GPIO_26); also elsewhere on the board
OUT20: U1.P1_32 (UART0_RX); also elsewhere on the board
OUT21: U1.P1_30 (UART0_TX); also elsewhere on the board
OUT22: U1.P1_20 (GPIO_20); also elsewhere on the board
OUT23: U1.P1_12 (SPI0_MOSI); also elsewhere on the board
OUT24: U1.P2_9 (I2C1_SCL); also elsewhere on the board
OUT25: U1.P2_11 (I2C1_SDA); also elsewhere on the board
OUT26: U1.P2_19 (GPIO_27); also elsewhere on the board
OUT27: U1.P2_20 (GPIO_64); also elsewhere on the board
OUT28: U1.P2_17 (GPIO_65); also elsewhere on the board
OUT29: U1.P2_7 (UART4_TX); also elsewhere on the board
OUT30: U1.P2_5 (UART4_RX); also elsewhere on the board
OUT31: U1.P2_3 (GPIO_23); also elsewhere on the board
OUT32: U1.P2_28 (PRU0_6); also elsewhere on the board
TXD1: U1.P2_32 (PRU0_2); also elsewhere on the board
TXD2: U1.P1_36 (PWM0_A); also elsewhere on the board
USB_D+: U1.P1_11 (USB1_DP); also elsewhere on the board
USB_D-: U1.P1_9 (USB1_DN); also elsewhere on the board
V_USB: U1.P1_5 (USB1_VBUS), U1.P1_7 (USB1_VIN); also elsewhere on the board


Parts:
C3: 0.1uF; C_Rect_L7.0mm_W2.0mm_P5.00mm; MPN SR215C104KARTR1; Digi-Key_PN 478-7336-1-ND
F1, F2, F3, F4, F5, F6, F7, F8: 3544-2; FUSE_3544-2; MPN 3544-2; Digi-Key_PN 36-3544-2-ND
J1: String1; PhoenixContact_MCV_1,5_3-G-3.5_1x03_P3.50mm_Vertical; MPN 1843619/OSTTJ0311530; Digi-Key_PN 277-5737-ND/ED10555-ND
J2: String2; PhoenixContact_MCV_1,5_3-G-3.5_1x03_P3.50mm_Vertical; MPN 1843619/OSTTJ0311530; Digi-Key_PN 277-5737-ND/ED10555-ND
J3: String3; PhoenixContact_MCV_1,5_3-G-3.5_1x03_P3.50mm_Vertical; MPN 1843619/OSTTJ0311530; Digi-Key_PN 277-5737-ND/ED10555-ND
J4: String4; PhoenixContact_MCV_1,5_3-G-3.5_1x03_P3.50mm_Vertical; MPN 1843619/OSTTJ0311530; Digi-Key_PN 277-5737-ND/ED10555-ND
J5: String5; PhoenixContact_MCV_1,5_3-G-3.5_1x03_P3.50mm_Vertical; MPN 1843619/OSTTJ0311530; Digi-Key_PN 277-5737-ND/ED10555-ND
J6: String6; PhoenixContact_MCV_1,5_3-G-3.5_1x03_P3.50mm_Vertical; MPN 1843619/OSTTJ0311530; Digi-Key_PN 277-5737-ND/ED10555-ND
J7: String7; PhoenixContact_MCV_1,5_3-G-3.5_1x03_P3.50mm_Vertical; MPN 1843619/OSTTJ0311530; Digi-Key_PN 277-5737-ND/ED10555-ND
J8: String8; PhoenixContact_MCV_1,5_3-G-3.5_1x03_P3.50mm_Vertical; MPN 1843619/OSTTJ0311530; Digi-Key_PN 277-5737-ND/ED10555-ND
RN1, RN2: 33; R_Array_SIP8; MPN 4608X-102-330LF; Digi-Key_PN 4608X-2-330LF-ND
U3: SN74HCT245N; MPN SN74HCT245N; Digi-Key_PN 296-1612-5-ND

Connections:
+5V: C3.1, U3.1 (DIR), U3.20 (VCC); also elsewhere on the board
/Output 1-8/DOUT1: J1.2, RN1.1 (R1.1)
/Output 1-8/DOUT2: J2.2, RN1.3 (R2.1)
/Output 1-8/DOUT3: J3.2, RN1.5 (R3.1)
/Output 1-8/DOUT4: J4.2, RN1.7 (R4.1)
/Output 1-8/DOUT5: J5.2, RN2.2 (R1.2)
/Output 1-8/DOUT6: J6.2, RN2.4 (R2.2)
/Output 1-8/DOUT7: J7.2, RN2.6 (R3.2)
/Output 1-8/DOUT8: J8.2, RN2.8 (R4.2)
/Output 1-8/VOUT1: F1.2_1 (2), F1.2_2 (2), J1.3
/Output 1-8/VOUT2: F2.2_1 (2), F2.2_2 (2), J2.3
/Output 1-8/VOUT3: F3.2_1 (2), F3.2_2 (2), J3.3
/Output 1-8/VOUT4: F4.2_1 (2), F4.2_2 (2), J4.3
/Output 1-8/VOUT5: F5.2_1 (2), F5.2_2 (2), J5.3
/Output 1-8/VOUT6: F6.2_1 (2), F6.2_2 (2), J6.3
/Output 1-8/VOUT7: F7.2_1 (2), F7.2_2 (2), J7.3
/Output 1-8/VOUT8: F8.2_1 (2), F8.2_2 (2), J8.3
DATA1: U3.9 (A8); also elsewhere on the board
DATA2: U3.8 (A7); also elsewhere on the board
DATA3: U3.7 (A6); also elsewhere on the board
DATA4: U3.6 (A5); also elsewhere on the board
DATA5: U3.5 (A4); also elsewhere on the board
DATA6: U3.4 (A3); also elsewhere on the board
DATA7: U3.3 (A2); also elsewhere on the board
DATA8: U3.2 (A1); also elsewhere on the board
GND: C3.2, J1.1, J2.1, J3.1, J4.1, J5.1, J6.1, J7.1, J8.1, U3.10 (GND), U3.19 (*OE); also elsewhere on the board
unnamed: RN1.2 (R1.2), U3.11 (B8)
unnamed: RN1.4 (R2.2), U3.12 (B7)
unnamed: RN1.6 (R3.2), U3.13 (B6)
unnamed: RN1.8 (R4.2), U3.14 (B5)
unnamed: RN2.1 (R1.1), U3.15 (B4)
unnamed: RN2.3 (R2.1), U3.16 (B3)
unnamed: RN2.5 (R3.1), U3.17 (B2)
unnamed: RN2.7 (R4.1), U3.18 (B1)
VIN1: F1.1_1 (1), F1.1_2 (1), F2.1_1 (1), F2.1_2 (1), F3.1_1 (1), F3.1_2 (1), F4.1_1 (1), F4.1_2 (1), F5.1_1 (1), F5.1_2 (1), F6.1_1 (1), F6.1_2 (1), F7.1_1 (1), F7.1_2 (1), F8.1_1 (1), F8.1_2 (1); also elsewhere on the board


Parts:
C4: 0.1uF; C_Rect_L7.0mm_W2.0mm_P5.00mm; MPN SR215C104KARTR1; Digi-Key_PN 478-7336-1-ND
F9, F10, F11, F12, F13, F14, F15, F16: 3544-2; FUSE_3544-2; MPN 3544-2; Digi-Key_PN 36-3544-2-ND
J9: String9; PhoenixContact_MCV_1,5_3-G-3.5_1x03_P3.50mm_Vertical; MPN 1843619/OSTTJ0311530; Digi-Key_PN 277-5737-ND/ED10555-ND
J10: String10; PhoenixContact_MCV_1,5_3-G-3.5_1x03_P3.50mm_Vertical; MPN 1843619/OSTTJ0311530; Digi-Key_PN 277-5737-ND/ED10555-ND
J11: String11; PhoenixContact_MCV_1,5_3-G-3.5_1x03_P3.50mm_Vertical; MPN 1843619/OSTTJ0311530; Digi-Key_PN 277-5737-ND/ED10555-ND
J12: String12; PhoenixContact_MCV_1,5_3-G-3.5_1x03_P3.50mm_Vertical; MPN 1843619/OSTTJ0311530; Digi-Key_PN 277-5737-ND/ED10555-ND
J13: String13; PhoenixContact_MCV_1,5_3-G-3.5_1x03_P3.50mm_Vertical; MPN 1843619/OSTTJ0311530; Digi-Key_PN 277-5737-ND/ED10555-ND
J14: String14; PhoenixContact_MCV_1,5_3-G-3.5_1x03_P3.50mm_Vertical; MPN 1843619/OSTTJ0311530; Digi-Key_PN 277-5737-ND/ED10555-ND
J15: String15; PhoenixContact_MCV_1,5_3-G-3.5_1x03_P3.50mm_Vertical; MPN 1843619/OSTTJ0311530; Digi-Key_PN 277-5737-ND/ED10555-ND
J16: String16; PhoenixContact_MCV_1,5_3-G-3.5_1x03_P3.50mm_Vertical; MPN 1843619/OSTTJ0311530; Digi-Key_PN 277-5737-ND/ED10555-ND
RN3, RN4: 33; R_Array_SIP8; MPN 4608X-102-330LF; Digi-Key_PN 4608X-2-330LF-ND
U4: SN74HCT245N; MPN SN74HCT245N; Digi-Key_PN 296-1612-5-ND

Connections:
+5V: C4.1, U4.1 (DIR), U4.20 (VCC); also elsewhere on the board
/Output 9-16/DOUT9: J9.2, RN3.1 (R1.1)
/Output 9-16/DOUT10: J10.2, RN3.3 (R2.1)
/Output 9-16/DOUT11: J11.2, RN3.5 (R3.1)
/Output 9-16/DOUT12: J12.2, RN3.7 (R4.1)
/Output 9-16/DOUT13: J13.2, RN4.2 (R1.2)
/Output 9-16/DOUT14: J14.2, RN4.4 (R2.2)
/Output 9-16/DOUT15: J15.2, RN4.6 (R3.2)
/Output 9-16/DOUT16: J16.2, RN4.8 (R4.2)
/Output 9-16/VOUT9: F9.2_1 (2), F9.2_2 (2), J9.3
/Output 9-16/VOUT10: F10.2_1 (2), F10.2_2 (2), J10.3
/Output 9-16/VOUT11: F11.2_1 (2), F11.2_2 (2), J11.3
/Output 9-16/VOUT12: F12.2_1 (2), F12.2_2 (2), J12.3
/Output 9-16/VOUT13: F13.2_1 (2), F13.2_2 (2), J13.3
/Output 9-16/VOUT14: F14.2_1 (2), F14.2_2 (2), J14.3
/Output 9-16/VOUT15: F15.2_1 (2), F15.2_2 (2), J15.3
/Output 9-16/VOUT16: F16.2_1 (2), F16.2_2 (2), J16.3
DATA9: U4.9 (A8); also elsewhere on the board
DATA10: U4.8 (A7); also elsewhere on the board
DATA11: U4.7 (A6); also elsewhere on the board
DATA12: U4.6 (A5); also elsewhere on the board
DATA13: U4.5 (A4); also elsewhere on the board
DATA14: U4.4 (A3); also elsewhere on the board
DATA15: U4.3 (A2); also elsewhere on the board
DATA16: U4.2 (A1); also elsewhere on the board
GND: C4.2, J9.1, J10.1, J11.1, J12.1, J13.1, J14.1, J15.1, J16.1, U4.10 (GND), U4.19 (*OE); also elsewhere on the board
unnamed: RN3.2 (R1.2), U4.11 (B8)
unnamed: RN3.4 (R2.2), U4.12 (B7)
unnamed: RN3.6 (R3.2), U4.13 (B6)
unnamed: RN3.8 (R4.2), U4.14 (B5)
unnamed: RN4.1 (R1.1), U4.15 (B4)
unnamed: RN4.3 (R2.1), U4.16 (B3)
unnamed: RN4.5 (R3.1), U4.17 (B2)
unnamed: RN4.7 (R4.1), U4.18 (B1)
VIN2: F9.1_1 (1), F9.1_2 (1), F10.1_1 (1), F10.1_2 (1), F11.1_1 (1), F11.1_2 (1), F12.1_1 (1), F12.1_2 (1), F13.1_1 (1), F13.1_2 (1), F14.1_1 (1), F14.1_2 (1), F15.1_1 (1), F15.1_2 (1), F16.1_1 (1), F16.1_2 (1); also elsewhere on the board

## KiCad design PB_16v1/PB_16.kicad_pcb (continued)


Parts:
C5: 0.1uF; C_Rect_L7.0mm_W2.0mm_P5.00mm; MPN SR215C104KARTR1; Digi-Key_PN 478-7336-1-ND
F18: 3544-2; FUSE_3544-2; MPN 3544-2; Digi-Key_PN 36-3544-2-ND
J20: DMX1 RJ45; RJ45_Amphenol_54602-x08_Horizontal; MPN A-2014-2-4-R; Digi-Key_PN AE10392-ND
J21: DMX2 RJ45; RJ45_Amphenol_54602-x08_Horizontal; MPN A-2014-2-4-R; Digi-Key_PN AE10392-ND
J22: DMX2; TerminalBlock_Phoenix_MKDS-1,5-4_1x04_P5.00mm_Horizontal; MPN 1729034; Digi-Key_PN 277-1238-ND
R1, R2: 120; R_Axial_DIN0207_L6.3mm_D2.5mm_P7.62mm_Horizontal; MPN CF14JT120R; Digi-Key_PN CF14JT120RCT-ND
SW1: DMX_Renard_Select; SW_CK_JS202011CQN_DPDT_Straight; MPN JS202011CQN; Digi-Key_PN 401-2001-ND
SW3: DMX_LOR_Select; SW_CK_JS202011CQN_DPDT_Straight; MPN JS202011CQN; Digi-Key_PN 401-2001-ND
U5: UA9638CP; DIP-8_W7.62mm; MPN UA9638CP; Digi-Key_PN 296-15059-5-ND

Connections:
+5V: C5.1, U5.1 (VCC); also elsewhere on the board
/Serial/9V: J20.3
/Serial/DMX1+: R1.1, SW3.2 (B), U5.8 (OUTB)
/Serial/DMX1-: R1.2, SW3.5 (B), U5.7 (OUTA)
/Serial/DMX2+: J22.3, R2.1, SW1.5 (B), U5.6 (OUTB)
/Serial/DMX2-: J22.2, R2.2, SW1.2 (B), U5.5 (OUTA)
GND: C5.2, J20.6, J20.7, J20.8, J21.7, J21.8, J22.1, U5.4 (GND); also elsewhere on the board
unnamed: J21.4, SW1.1 (A)
unnamed: J21.2, SW1.3 (C)
unnamed: J21.1, SW1.4 (A)
unnamed: J21.5, SW1.6 (C)
unnamed: J20.4, SW3.1 (A)
unnamed: J20.1, SW3.3 (C)
unnamed: J20.2, SW3.4 (A)
unnamed: J20.5, SW3.6 (C)
TXD1: U5.2 (IN); also elsewhere on the board
TXD2: U5.3 (IN); also elsewhere on the board
VIN1: F18.1_1 (1), F18.1_2 (1); also elsewhere on the board
V_DMX: F18.2_1 (2), F18.2_2 (2), J22.4

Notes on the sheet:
DMX2
DMX1


Board: 2 copper layers, 148.1 x 102.6 mm, 89 parts (0 on the bottom side), 117 nets.

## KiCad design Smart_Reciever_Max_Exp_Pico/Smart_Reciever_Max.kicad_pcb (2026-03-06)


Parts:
C1: 100uF; CP_Radial_D5.0mm_P2.00mm; MPN 16ZLH100MEFC5X11; Digi-Key_PN 1189-1148-ND
C2: 10uF; CP_Radial_D5.0mm_P2.00mm; MPN UVR1H100MDD; Digi-Key_PN 493-1103-ND
D1: VIN LED; LED_D3.0mm_Clear; MPN WP3A8GD; Digi-Key_PN 754-1217-ND
F1: Fuse; Fuse_BelFuse_0ZRE0005FF_L8.3mm_W3.8mm; MPN RXEF050-2; Digi-Key_PN RXEF050-2HFCT-ND
H1, H2, H3, H4: MountingHole; MountingHole_4.3mm_M4
J1: Power In; TerminalBlock_Phoenix_MKDS-1,5-2_1x02_P5.00mm_Horizontal; MPN 1729018; Digi-Key_PN 277-1236-ND
J4: VIN_Voltage; PinHeader_1x03_P2.54mm_Vertical; MPN 61300311121; Digi-Key_PN 732-5316-ND
R1: 1K; R_Axial_DIN0207_L6.3mm_D2.5mm_P7.62mm_Horizontal; MPN CF14JT1K00; Digi-Key_PN CF14JT1K00CT-ND
U1: L7805; TO-220-3_Vertical; MPN MC7805CTG; Digi-Key_PN MC7805CTGOS-ND

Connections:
5IN: C2.1, F1.2, J4.3, U1.3 (OUT)
+5V: F1.1; also elsewhere on the board
/PWR: C1.1, J4.1, U1.1 (IN)
GND: C1.2, C2.2, J1.2, R1.1, U1.2 (GND); also elsewhere on the board
unnamed: D1.1 (K), R1.2
VIN2: D1.2 (A), J1.1, J4.2


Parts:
C3: 0.1uF; C_Rect_L7.0mm_W2.0mm_P5.00mm; MPN SR215C104KARTR1; Digi-Key_PN 478-7336-1-ND
D2: Stat LED; LED_D3.0mm_Clear; MPN WP3A8GD; Digi-Key_PN 754-1217-ND
J5: EXT1; PinHeader_1x04_P2.54mm_Vertical
J7: EXT3; PinHeader_1x06_P2.54mm_Vertical
R2: 120; R_Axial_DIN0207_L6.3mm_D2.5mm_P7.62mm_Horizontal; MPN CF14JT120R; Digi-Key_PN CF14JT120RCT-ND
SW1: USR; SW_PUSH_6mm; MPN 1825910-6; Digi-Key_PN 450-1650-ND
SW2: RUN; SW_PUSH_6mm; MPN 1825910-6; Digi-Key_PN 450-1650-ND
TP1: GP4; TestPoint_THTPad_1.0x1.0mm_Drill0.5mm
TP2: GP5; TestPoint_THTPad_1.0x1.0mm_Drill0.5mm
TP3, TP4: 3v3; TestPoint_THTPad_1.0x1.0mm_Drill0.5mm
TP5, TP6: GND; TestPoint_THTPad_1.0x1.0mm_Drill0.5mm
U2: raspberrypi-pico-module; raspberrypi-pico-module-nohole; MPN SC0915; Digi-Key_PN 2648-SC0915CT-ND

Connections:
+3V3: TP3.1, TP4.1, U2.36 (3V3_OUT); also elsewhere on the board
+5V: C3.1, J5.1, J7.1, U2.39 (VSYS); also elsewhere on the board
DATA1: U2.14 (GP10); also elsewhere on the board
DATA2: U2.15 (GP11); also elsewhere on the board
DATA3: U2.16 (GP12); also elsewhere on the board
DATA4: U2.17 (GP13); also elsewhere on the board
EN1A: U2.20 (GP15); also elsewhere on the board
EN1B: U2.24 (GP18); also elsewhere on the board
EN1C: U2.29 (GP22); also elsewhere on the board
EN2A: U2.19 (GP14); also elsewhere on the board
EN2B: U2.25 (GP19); also elsewhere on the board
EN2C: U2.31 (GP26_ADC0); also elsewhere on the board
EN3A: U2.21 (GP16); also elsewhere on the board
EN3B: U2.26 (GP20); also elsewhere on the board
EN3C: U2.32 (GP27_ADC1); also elsewhere on the board
EN4A: U2.22 (GP17); also elsewhere on the board
EN4B: U2.27 (GP21); also elsewhere on the board
EN4C: U2.34 (GP28_ADC2); also elsewhere on the board
GND: C3.2, J5.4, J7.6, R2.1, SW1.2, SW2.2, TP5.1, TP6.1, U2.3 (GND), U2.8 (GND), U2.13 (GND), U2.18 (GND), U2.23 (GND), U2.28 (GND), U2.33 (GND_AGND), U2.38 (GND); also elsewhere on the board
GPIO0: J5.2, U2.1 (GP0)
GPIO1: J5.3, U2.2 (GP1)
GPIO2: SW1.1, U2.4 (GP2)
GPIO3: D2.2 (A), U2.5 (GP3)
GPIO6: J7.2, U2.9 (GP6)
GPIO7: J7.3, U2.10 (GP7)
GPIO8: J7.4, U2.11 (GP8)
GPIO9: J7.5, U2.12 (GP9)
unnamed: D2.1 (K), R2.2
unnamed: TP1.1, U2.6 (GP4)
unnamed: TP2.1, U2.7 (GP5)
RUN: SW2.1, U2.30 (RUN)


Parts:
C4, C8: 0.1uF; C_Rect_L7.0mm_W2.0mm_P5.00mm; MPN SR215C104KARTR1; Digi-Key_PN 478-7336-1-ND
J3: RJ45; RJ45_Amphenol_54602-x08_Horizontal; MPN A-2014-2-4-R; Digi-Key_PN AE10392-ND
JP1: U6_V; SolderJumper-3_P2.0mm_Open_TrianglePad1.0x1.5mm
JP2: Data1_JMP; SolderJumper-2_P1.3mm_Open_TrianglePad1.0x1.5mm
JP3: Data4_JMP; SolderJumper-2_P1.3mm_Open_TrianglePad1.0x1.5mm
JP4: Data2_JMP; SolderJumper-2_P1.3mm_Open_TrianglePad1.0x1.5mm
JP5: Data3_JMP; SolderJumper-2_P1.3mm_Open_TrianglePad1.0x1.5mm
RN1: 120; R_Array_SIP8; MPN 4608X-102-121LF; Digi-Key_PN 4608X-2-121LF-ND
U6: AM26C32IN; DIP-16_W7.62mm_LongPads; MPN AM26C32IN; Digi-Key_PN 296-6789-5-ND
U7: 74LS125; DIP-14_W7.62mm_LongPads; MPN SN74AHC125N; Digi-Key_PN 296-4531-5-ND

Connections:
+3V3: C8.1, JP1.3 (B), U7.14 (VCC); also elsewhere on the board
+5V: JP1.1 (A); also elsewhere on the board
DATA1: JP2.2 (B), U7.3; also elsewhere on the board
DATA1_3v3: JP2.1 (A), U6.3 (OUT_A), U7.2
DATA2: JP4.2 (B), U7.8; also elsewhere on the board
DATA2_3v3: JP4.1 (A), U6.13 (OUT_B), U7.9
DATA3: JP5.2 (B), U7.11; also elsewhere on the board
DATA3_3v3: JP5.1 (A), U6.5 (OUT_C), U7.12
DATA4: JP3.2 (B), U7.6; also elsewhere on the board
DATA4_3v3: JP3.1 (A), U6.11 (OUT_D), U7.5
GND: C4.2, C8.2, U6.4 (EN), U6.8 (GND), U6.12 (EN_2), U7.1, U7.4, U7.7 (GND), U7.10, U7.13; also elsewhere on the board
Serial1_N: J3.2, RN1.1 (R1.1), U6.1 (INPUT_A-)
Serial1_P: J3.1, RN1.2 (R1.2), U6.2 (INPUT_A+)
Serial2_N: J3.6, RN1.3 (R2.1), U6.15 (INPUT_B-)
Serial2_P: J3.3, RN1.4 (R2.2), U6.14 (INPUT_B+)
Serial3_N: J3.4, RN1.6 (R3.2), U6.7 (INPUT_C-)
Serial3_P: J3.5, RN1.5 (R3.1), U6.6 (INPUT_C+)
Serial4_N: J3.8, RN1.8 (R4.2), U6.9 (INPUT_D-)
Serial4_P: J3.7, RN1.7 (R4.1), U6.10 (INPUT_D+)
U6_V: C4.1, JP1.2 (C), U6.16 (VCC)


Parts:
C3, C5, C6: 0.1uF; C_Rect_L7.0mm_W2.0mm_P5.00mm; MPN SR215C104KARTR1; Digi-Key_PN 478-7336-1-ND
J2: Expansion Header; IDC-Header_2x20_P2.54mm_Vertical; MPN SBH11-PBPC-D20-ST-BK; Digi-Key_PN S9175-ND
J6: EXT2; PinHeader_1x06_P2.54mm_Vertical
U3, U4, U5: 74LS125; DIP-14_W7.62mm_LongPads; MPN SN74AHC125N; Digi-Key_PN 296-4531-5-ND

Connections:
+5V: C3.1, C5.1, C6.1, J2.2, J2.4, J2.39, J2.40, J6.1, U3.14 (VCC), U4.14 (VCC), U5.14 (VCC); also elsewhere on the board
DATA1: U3.2, U4.2, U5.2; also elsewhere on the board
DATA2: U3.12, U4.12, U5.12; also elsewhere on the board
DATA3: U3.5, U4.5, U5.5; also elsewhere on the board
DATA4: U3.9, U4.9, U5.9; also elsewhere on the board
EN1A: U3.1; also elsewhere on the board
EN1B: U4.1; also elsewhere on the board
EN1C: U5.1; also elsewhere on the board
EN2A: U3.13; also elsewhere on the board
EN2B: U4.13; also elsewhere on the board
EN2C: U5.13; also elsewhere on the board
EN3A: U3.4; also elsewhere on the board
EN3B: U4.4; also elsewhere on the board
EN3C: U5.4; also elsewhere on the board
EN4A: U3.10; also elsewhere on the board
EN4B: U4.10; also elsewhere on the board
EN4C: U5.10; also elsewhere on the board
GND: C3.2, C5.2, C6.2, J2.3, J2.5, J2.7, J2.9, J2.11, J2.13, J2.15, J2.17, J2.19, J2.21, J2.23, J2.25, J2.27, J2.29, J2.33, J2.35, J2.37, J2.38, J6.6, U3.7 (GND), U4.7 (GND), U5.7 (GND); also elsewhere on the board
OUT1: J2.6, U3.3
OUT2: J2.8, U3.11
OUT3: J2.10, U3.6
OUT4: J2.12, U3.8
OUT5: J2.14, U4.3
OUT6: J2.16, U4.11
OUT7: J2.18, U4.6
OUT8: J2.20, U4.8
OUT9: J2.22, U5.3
OUT10: J2.24, U5.11
OUT11: J2.26, U5.6
OUT12: J2.28, U5.8
OUT13: J2.31, J6.2
OUT14: J2.32, J6.3
OUT15: J2.34, J6.4
OUT16: J2.36, J6.5



Board: 2 copper layers, 102.0 x 60.0 mm, 45 parts (11 on the bottom side), 64 nets.

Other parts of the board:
C7: 0.1uF; C_Rect_L7.0mm_W2.0mm_P5.00mm

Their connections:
+5V: C7.1; also elsewhere on the board
GND: C7.2; also elsewhere on the board

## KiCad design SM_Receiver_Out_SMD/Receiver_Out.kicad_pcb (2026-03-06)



Board: 2 copper layers, 83.2 x 71.4 mm, 65 parts (9 on the bottom side), 61 nets.

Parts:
C1, C2: 10uF; C_0805_2012Metric_Pad1.18x1.45mm_HandSolder
C3, C4, C5: 0.1uF; C_0603_1608Metric_Pad1.08x0.95mm_HandSolder
D1: B5819W; D_SOD-123
D2: VIN LED; LED_0603_1608Metric_Pad1.05x0.95mm_HandSolder
D4: LED; LED_0603_1608Metric_Pad1.05x0.95mm_HandSolder
F1, F2, F3, F4: 3544-2; FUSE_3544-2
H1, H2, H3, H4: MountingHole; MountingHole_3.7mm
J1: String1; PhoenixContact_MCV_1,5_3-G-3.5_1x03_P3.50mm_Vertical
J2: String2; PhoenixContact_MCV_1,5_3-G-3.5_1x03_P3.50mm_Vertical
J3: String3; PhoenixContact_MCV_1,5_3-G-3.5_1x03_P3.50mm_Vertical
J4: String4; PhoenixContact_MCV_1,5_3-G-3.5_1x03_P3.50mm_Vertical
J5: OLED; OLED-SSD1306-128X64-I2C-THT
J6: VIN_Voltage; PinHeader_1x03_P2.54mm_Vertical
J7, J8: RJ45; RJ45_Amphenol_54602-x08_Horizontal
J9: Debug; PinHeader_1x03_P2.54mm_Vertical
J10: SWD; 1x02_Horizontal_SMD
R1: 1K; R_0603_1608Metric_Pad0.98x0.95mm_HandSolder
R2: 100K; R_0603_1608Metric_Pad0.98x0.95mm_HandSolder
R3, R4, R5, R6: 120; R_0603_1608Metric_Pad0.98x0.95mm_HandSolder
R7, R8, R9, R10: 33ohm; R_0603_1608Metric_Pad0.98x0.95mm_HandSolder
R11: 220; R_0603_1608Metric_Pad0.98x0.95mm_HandSolder
R12, R13, R14, R15, R16, R17, R18, R19: 100ohm; R_0603_1608Metric_Pad0.98x0.95mm_HandSolder
SW1: ID; Nidec_Copal_SH-7010C
SW2: Terminators; SW_DIP_SPSTx04_Slide_6.7x11.72mm_W7.62mm_P2.54mm_LowProfile
SW3: User; SW_Push_1P1T_NO_6x6mm_H9.5mm
SW4: RUN; SW_Push_1P1T_NO_6x6mm_H9.5mm
TB1: Power In; BARRIER_BLOCK_1ROW_2POS
TP1: DATA1; TestPoint_Pad_D1.5mm
TP2: DATA2; TestPoint_Pad_D1.5mm
TP3: DATA3; TestPoint_Pad_D1.5mm
TP4: DATA4; TestPoint_Pad_D1.5mm
TP5: EN1; TestPoint_Pad_D1.5mm
TP6: EN2; TestPoint_Pad_D1.5mm
TP7: EN3; TestPoint_Pad_D1.5mm
TP8: EN4; TestPoint_Pad_D1.5mm
U1: Pico; RPi_Pico_SMD_TH
U2: AMS1117-5.0; SOT-223-3_TabPin2
U3: AM26C32IN; SOIC-16_3.9x9.9mm_P1.27mm
U4, U5, U6, U7: 74AHCT1G125; TSOP-5_1.65x3.05mm_P0.95mm

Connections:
+3V3: C4.1, J5.3, U1.36 (3V3), U3.16 (VCC)
+5V: C2.1, C3.1, C5.1, J6.3, U1.39 (VSYS), U2.2 (VO), U4.5 (VCC), U5.5 (VCC), U6.5 (VCC), U7.5 (VCC)
/Micro/SCL: J5.2, U1.32 (GPIO27_ADC1)
/Micro/SDA: J5.1, U1.31 (GPIO26_ADC0)
/Micro/SWDCLK: J10.1, U1.41 (SWCLK)
/Micro/SWDIO: J10.2, U1.43 (SWDIO)
/Outputs/DOUT1: J1.2, R7.1
/Outputs/DOUT2: J2.2, R8.1
/Outputs/DOUT3: J3.2, R9.1
/Outputs/DOUT4: J4.2, R10.1
/Outputs/VOUT1: F1.2_1 (2), F1.2_2 (2), J1.3
/Outputs/VOUT2: F2.2_1 (2), F2.2_2 (2), J2.3
/Outputs/VOUT3: F3.2_1 (2), F3.2_2 (2), J3.3
/Outputs/VOUT4: F4.2_1 (2), F4.2_2 (2), J4.3
/PWR: C1.1, J6.1, U2.3 (VI)
/VIN: D1.1 (K), J6.2
DIFF_EN: R2.1, U1.11 (GPIO8), U3.12 (EN_2)
EN1: TP5.1, U1.14 (GPIO10), U4.1
EN2: TP6.1, U1.15 (GPIO11), U5.1
EN3: TP7.1, U1.16 (GPIO12), U6.1
EN4: TP8.1, U1.17 (GPIO13), U7.1
GND: C1.2, C2.2, C3.2, C4.2, C5.2, J1.1, J2.1, J3.1, J4.1, J5.4, J9.3, R1.1, R2.2, R11.2, SW1.C, SW3.1, SW4.2, TB1.1, U1.3 (GND), U1.8 (GND), U1.13 (GND), U1.18 (GND), U1.23 (GND), U1.28 (GND), U1.38 (GND), U1.42 (GND), U2.1 (GND), U3.4 (EN), U3.8 (GND), U4.3 (GND), U5.3 (GND), U6.3 (GND), U7.3 (GND)
unnamed: D2.1 (K), R1.2
unnamed: D4.1 (K), R11.1
unnamed: D4.2 (A), U1.9 (GPIO6)
unnamed: J9.1, U1.2 (GPIO1)
unnamed: J9.2, U1.1 (GPIO0)
unnamed: R3.1, SW2.1
unnamed: R4.1, SW2.2
unnamed: R5.1, SW2.3
unnamed: R6.1, SW2.4
unnamed: R7.2, U4.4
unnamed: R8.2, U5.4
unnamed: R9.2, U6.4
unnamed: R10.2, U7.4
unnamed: R12.1, U3.13 (OUT_B)
unnamed: R13.1, U3.11 (OUT_D)
unnamed: R14.2, U3.3 (OUT_A)
unnamed: R15.2, U3.5 (OUT_C)
unnamed: R16.1, TP1.1, U1.4 (GPIO2)
unnamed: R17.1, TP2.1, U1.5 (GPIO3)
unnamed: R18.1, TP3.1, U1.6 (GPIO4)
unnamed: R19.1, TP4.1, U1.7 (GPIO5)
unnamed: SW1.1, U1.25 (GPIO19)
unnamed: SW1.2, U1.26 (GPIO20)
unnamed: SW1.4, U1.27 (GPIO21)
unnamed: SW3.2, U1.10 (GPIO7)
unnamed: SW4.1, U1.30 (RUN)
OUT17: R13.2, R16.2, U4.2
OUT18: R15.1, R17.2, U5.2
OUT19: R12.2, R18.2, U6.2
OUT20: R14.1, R19.2, U7.2
Serial1_N: J7.2, J8.2, SW2.8, U3.9 (INPUT_D-)
Serial1_P: J7.1, J8.1, R3.2, U3.10 (INPUT_D+)
Serial2_N: J7.6, J8.6, SW2.7, U3.7 (INPUT_C-)
Serial2_P: J7.3, J8.3, R4.2, U3.6 (INPUT_C+)
Serial3_N: J7.4, J8.4, SW2.6, U3.15 (INPUT_B-)
Serial3_P: J7.5, J8.5, R5.2, U3.14 (INPUT_B+)
Serial4_N: J7.8, J8.8, SW2.5, U3.1 (INPUT_A-)
Serial4_P: J7.7, J8.7, R6.2, U3.2 (INPUT_A+)
VIN1: D1.2 (A), D2.2 (A), F1.1_1 (1), F1.1_2 (1), F2.1_1 (1), F2.1_2 (1), F3.1_1 (1), F3.1_2 (1), F4.1_1 (1), F4.1_2 (1), TB1.2

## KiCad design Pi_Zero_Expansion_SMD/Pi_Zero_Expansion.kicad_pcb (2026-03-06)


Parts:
C1: 220uF; CP_Radial_D10.0mm_P5.00mm; MPN ECA-1HM221; Digi-Key_PN P5183-ND
C2: 100uF; CP_Elec_6.3x5.4_Nichicon; MPN UWX1C101MCL1GB; Digi-Key_PN 493-2105-1-ND
C3: 0.1uF; C_0603_1608Metric_Pad1.08x0.95mm_HandSolder; MPN CL10B104KB8NNWC; Digi-Key_PN 1276-1935-2-ND
D1: Zener 10V; D_SOD-123; MPN MMSZ5240B-7-F; Digi-Key_PN MMSZ5240B-FDICT-ND
D2: VIN2 LED; LED_0603_1608Metric_Pad1.05x0.95mm_HandSolder; MPN LTST-C190KRKT; Digi-Key_PN 160-1436-2-ND
D3: 5V LED; LED_0603_1608Metric_Pad1.05x0.95mm_HandSolder; MPN LTST-C190KRKT; Digi-Key_PN 160-1436-2-ND
F1: 3544-2; FUSE_3544-2; MPN 3544-2; Digi-Key_PN 36-3544-2-ND
H1, H2, H3, H4: MountingHole; MountingHole_3.7mm
J1: Pwr In; PHOENIX_MKDS1_2-3.81; MPN 1727010; Digi-Key_PN 277-1947-ND
J2: VIN Voltage; PinHeader_1x03_P2.54mm_Vertical; MPN 61300311121; Digi-Key_PN 732-5316-ND
J3: OLED Conn; PinSocket_1x04_P2.54mm_Vertical; MPN PPTC041LFBN-RC; Digi-Key_PN S7002-ND
J4: v3 Output Header; IDC-Header_2x20_P2.54mm_Vertical; MPN SBH11-PBPC-D20-ST-BK; Digi-Key_PN S9175-ND
J5: v4 Output Header; IDC-Header_2x12_P2.54mm_Vertical; MPN Z-S311024S1GK1A; Digi-Key_PN ED10525-ND
PIN3: PIN_3_JMP; SolderJumper-3_P1mm_Bridged12
PIN4: PIN_4_JMP; SolderJumper-3_P1mm_Bridged23
Q1: DMP3056L; SOT-23; MPN DMP3056L-7; Digi-Key_PN DMP3056L-7DICT-ND
R1: 100K; R_0603_1608Metric_Pad0.98x0.95mm_HandSolder; MPN RT0603BRD07100KL; Digi-Key_PN YAG1235CT-ND
R2: 2K; R_0603_1608Metric_Pad0.98x0.95mm_HandSolder; LCSC C4190
R3: 330; R_0603_1608Metric_Pad0.98x0.95mm_HandSolder; LCSC C23138
R4, R5: 4.7K; R_0603_1608Metric_Pad0.98x0.95mm_HandSolder; MPN RC0603JR-074K7L; Digi-Key_PN 311-4.7KGRCT-ND
SW1: Enter BTN; SW_Push_1P1T_NO_6x6mm_H9.5mm; MPN PTS645SL50SMTR92 LFS; Digi-Key_PN CKN9088CT-ND
SW2: Down BTN; SW_Push_1P1T_NO_6x6mm_H9.5mm; MPN PTS645SL50SMTR92 LFS; Digi-Key_PN CKN9088CT-ND
U1: Universe5V; Universal_5V_Horizontal
U2: 24LC256; SOIC-8_3.9x4.9mm_P1.27mm; MPN 24LC256T-I/SN; Digi-Key_PN 24LC256T-I/SNCT-ND

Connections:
+3V3: C3.1, J5.23, PIN3.1 (A), PIN4.1 (A), R4.2, R5.2, U2.8 (VCC); also elsewhere on the board
+5V: C2.1, D3.2 (A), J2.3, J4.2, J4.4, J4.39, J4.40, J5.3, J5.4, U1.3 (OUT), U1.4 (OUT), U1.8 (OUT); also elsewhere on the board
BTN1: SW1.1; also elsewhere on the board
BTN2: SW2.1; also elsewhere on the board
GND: C1.2, C2.2, C3.2, D2.1 (K), J1.2, J4.3, J4.5, J4.7, J4.9, J4.11, J4.13, J4.15, J4.17, J4.19, J4.21, J4.23, J4.25, J4.27, J4.29, J4.33, J4.35, J4.37, J4.38, J5.1, J5.2, J5.21, J5.22, PIN3.3 (B), PIN4.3 (B), R1.1, R3.1, SW1.2, SW2.2, U1.2 (GND), U1.5 (GND), U1.9 (GND), U1.10 (GND), U2.1 (A0), U2.2 (A1), U2.3 (A2), U2.4 (GND), U2.7 (WP); also elsewhere on the board
I2C_SCL: J3.2, R5.1, U2.6 (SCL); also elsewhere on the board
I2C_SDA: J3.1, R4.1, U2.5 (SDA); also elsewhere on the board
unnamed: C1.1, J2.1, U1.1 (IN), U1.6 (IN), U1.11 (IN)
unnamed: D1.2 (A), Q1.1 (G), R1.2
unnamed: D2.2 (A), R2.1
unnamed: D3.1 (K), R3.2
unnamed: J3.3, PIN3.2 (C)
unnamed: J3.4, PIN4.2 (C)
OUT1: J4.6, J5.5; also elsewhere on the board
OUT2: J4.8, J5.6; also elsewhere on the board
OUT3: J4.10, J5.7; also elsewhere on the board
OUT4: J4.12, J5.8; also elsewhere on the board
OUT5: J4.14, J5.9; also elsewhere on the board
OUT6: J4.16, J5.10; also elsewhere on the board
OUT7: J4.18, J5.11; also elsewhere on the board
OUT8: J4.20, J5.12; also elsewhere on the board
OUT9: J4.22, J5.13; also elsewhere on the board
OUT10: J4.24, J5.14; also elsewhere on the board
OUT11: J4.26, J5.15; also elsewhere on the board
OUT12: J4.28, J5.16; also elsewhere on the board
OUT13: J4.31, J5.17; also elsewhere on the board
OUT14: J4.32, J5.18; also elsewhere on the board
OUT15: J4.34, J5.19; also elsewhere on the board
OUT16: J4.36, J5.20; also elsewhere on the board
VCC: D1.1 (K), J2.2, Q1.2 (S)
VIN: F1.2_1 (2), F1.2_2 (2), Q1.3 (D), R2.2
VIN2: F1.1_1 (1), F1.1_2 (1), J1.1

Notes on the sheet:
Power LEDs
Power In
OLED Headers
Push Buttons
Power Input Voltage Regulater
EEPROM


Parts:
U3: Raspberry Pi Zero; Raspberry_Pi_Zero_Socketed_THT_FaceDown_MountingHoles

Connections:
+3V3: U3.1 (3V3); also elsewhere on the board
+5V: U3.2 (5V), U3.4 (5V); also elsewhere on the board
BTN1: U3.27 (ID_SD/GPIO0); also elsewhere on the board
BTN2: U3.28 (ID_SC/GPIO1); also elsewhere on the board
GND: U3.6 (GND), U3.9 (GND), U3.14 (GND), U3.20 (GND), U3.25 (GND), U3.30 (GND), U3.34 (GND), U3.39 (GND); also elsewhere on the board
I2C_SCL: U3.5 (SCL/GPIO3); also elsewhere on the board
I2C_SDA: U3.3 (SDA/GPIO2); also elsewhere on the board
OUT1: U3.32 (PWM0/GPIO12); also elsewhere on the board
OUT2: U3.26 (~CE1/GPIO7); also elsewhere on the board
OUT3: U3.23 (SCLK0/GPIO11); also elsewhere on the board
OUT4: U3.24 (~CE0/GPIO8); also elsewhere on the board
OUT5: U3.21 (MISO0/GPIO9); also elsewhere on the board
OUT6: U3.22 (GPIO25); also elsewhere on the board
OUT7: U3.19 (MOSI0/GPIO10); also elsewhere on the board
OUT8: U3.18 (GPIO24); also elsewhere on the board
OUT9: U3.16 (GPIO23); also elsewhere on the board
OUT10: U3.15 (GPIO22); also elsewhere on the board
OUT11: U3.13 (GPIO27); also elsewhere on the board
OUT12: U3.12 (GPIO18/PWM0); also elsewhere on the board
OUT13: U3.11 (GPIO17); also elsewhere on the board
OUT14: U3.10 (GPIO15/RXD); also elsewhere on the board
OUT15: U3.8 (GPIO14/TXD); also elsewhere on the board
OUT16: U3.7 (GCLK0/GPIO4); also elsewhere on the board
OUT17: U3.37 (GPIO26)
OUT18: U3.40 (GPIO21/SCLK1)
OUT19: U3.38 (GPIO20/MOSI1)
OUT20: U3.36 (GPIO16)
OUT21: U3.29 (GCLK1/GPIO5)
OUT22: U3.31 (GCLK2/GPIO6)
OUT23: U3.33 (PWM1/GPIO13)
OUT24: U3.35 (GPIO19/MISO1)


Board: 2 copper layers, 100.0 x 70.0 mm, 29 parts (1 on the bottom side), 32 nets.

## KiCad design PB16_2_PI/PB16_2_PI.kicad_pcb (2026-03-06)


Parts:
J1: Raspberry_Pi_2_3; Raspberry_Pi_Zero_Socketed_THT_FaceDown_MountingHoles
TP1: USB_D-; TestPoint_THTPad_1.0x1.0mm_Drill0.5mm
TP2: USB_D+; TestPoint_THTPad_1.0x1.0mm_Drill0.5mm
U1: POCKETBEAGLE-SC-569; BEAGLE_POCKETBEAGLE-SC-569

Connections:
+3V3: J1.17 (3V3), U1.P1_14 (SYS_3.3V)
+5V: J1.2 (5V), J1.4 (5V), U1.P1_1 (SYS_VIN), U1.P1_5 (USB1_VBUS)
BTN1: J1.27 (ID_SD/GPIO0), U1.P1_6 (SPI0_CS)
BTN2: J1.28 (ID_SC/GPIO1), U1.P1_8 (SPI0_CLK)
DATA1_DATA14: J1.40 (GPIO21/SCLK1), U1.P2_34 (PRU0_5)
DATA2: J1.36 (GPIO16), U1.P2_32 (PRU0_2)
DATA3_DATA15: J1.33 (PWM1/GPIO13), U1.P2_30 (PRU0_3)
DATA4: J1.26 (~CE1/GPIO7), U1.P2_28 (PRU0_6)
DATA5_DATA9: J1.24 (~CE0/GPIO8), U1.P2_24 (GPIO_48)
DATA6_DATA1: J1.22 (GPIO25), U1.P2_22 (GPIO_46)
DATA7: J1.21 (MISO0/GPIO9), U1.P2_20 (GPIO_64)
DATA8_DATA2: J1.19 (MOSI0/GPIO10), U1.P2_18 (GPIO_47)
DATA9_DATA3: J1.13 (GPIO27), U1.P2_7 (UART4_TX), U1.P2_10 (GPIO_52)
DATA10_DATA4: J1.16 (GPIO23), U1.P2_8 (GPIO_60)
DATA11: J1.12 (GPIO18/PWM0), U1.P2_5 (UART4_RX)
DATA12_DATA5: J1.18 (GPIO24), U1.P2_6 (GPIO_57)
DATA13_DATA6: J1.15 (GPIO22), U1.P2_4 (GPIO_58)
DATA14: J1.11 (GPIO17), U1.P2_3 (GPIO_23)
DATA15_DATA7: J1.10 (GPIO15/RXD), U1.P2_2 (GPIO_59)
DATA16_DATA8: J1.7 (GCLK0/GPIO4), U1.P2_1 (PWM1_A)
GND: J1.6 (GND), J1.9 (GND), J1.14 (GND), J1.20 (GND), J1.25 (GND), J1.30 (GND), J1.34 (GND), J1.39 (GND), U1.P1_13 (USB1_ID), U1.P1_15 (USB1_GND), U1.P1_16 (SYS_GND), U1.P1_17 (AIN1.8V_REF-), U1.P1_22 (SYS_GND), U1.P2_15 (SYS_GND), U1.P2_21 (SYS_GND)
I2C_SCL: J1.5 (SCL/GPIO3), U1.P1_28 (I2C2_SCL)
I2C_SDA: J1.3 (SDA/GPIO2), U1.P1_26 (I2C2_SDA)
OUT17_DATA12: J1.37 (GPIO26), U1.P2_33 (GPIO_45)
OUT18: J1.38 (GPIO20/MOSI1), U1.P2_35 (AIN5/GPIO86)
OUT19_DATA10: J1.32 (PWM0/GPIO12), U1.P2_25 (SPI1_MOSI), U1.P2_29 (SPI1_CLK)
OUT20_DATA11: J1.35 (GPIO19/MISO1), U1.P2_27 (SPI1_MISO), U1.P2_31 (SPI1_CS)
TXD1: J1.8 (GPIO14/TXD), U1.P1_10 (SPI0_MISO), U1.P1_36 (PWM0_A), U1.P2_9 (I2C1_SCL)
USB_D+: TP2.1, U1.P1_11 (USB1_DP)
USB_D-: TP1.1, U1.P1_9 (USB1_DN)
V1_D13: J1.29 (GCLK1/GPIO5), U1.P1_29 (PRU0_7)
V1_D16: J1.31 (GCLK2/GPIO6), U1.P1_33 (PRU0_1)


Board: 2 copper layers, 65.1 x 37.4 mm, 4 parts (1 on the bottom side), 32 nets.

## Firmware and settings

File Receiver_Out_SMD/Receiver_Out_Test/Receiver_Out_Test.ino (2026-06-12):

#include <FAB_LED.h>
#include <OneButton.h>

const uint16_t numPixels = 300;

ws2812b<B,3> myLeds1;
ws2812b<B,0> myLeds2;
ws2812b<B,1> myLeds3;
ws2812b<B,2> myLeds4;
//ws2812b8s<B,0,7> strip_split8;//maybe?

volatile bool test_en = false;

volatile int mode = 0;

volatile unsigned long previousMillis = 0;

// constants won't change:
const long interval = 1000;

// --- WS2812 data detection on PB3, status LED on PA7 ---
const uint8_t DATA_PIN_BM = (1 << 3);    // PB3 bitmask within PORTB
const unsigned long dataTimeoutMs = 250; // consider data "lost" after this idle time
#define WS_DETECT_ISC PORT_ISC_RISING_gc // interrupt on rising edges (line idles low)
volatile bool wsActivity = false;        // set by the pin-change ISR on each edge
unsigned long lastDataMillis = 0;        // last time activity was seen on PB3
bool dataLedOn = false;                  // current state of the PA7 status LED

////////////////////////////////////////////////////////////////////////////////
/// @brief Pin-change ISR for PORTB.
/// The WS2812 line idles low and produces a rising edge for every bit clocked
/// in, so any edge means data is present. We only flag activity here; the loop
/// timestamps it. The PB3 interrupt is disabled while test mode drives PORTB.
////////////////////////////////////////////////////////////////////////////////
ISR(PORTB_PORT_vect)
{
  if (PORTB.INTFLAGS & DATA_PIN_BM)
  {
    PORTB.INTFLAGS = DATA_PIN_BM; // clear the flag (write 1 to clear)
    wsActivity = true;
  }
}

OneButton  button = OneButton (
  PIN_PA2,  // Input pin for the button
  true,        // Button is active LOW
  true         // Enable internal pull-up resistor
);

////////////////////////////////////////////////////////////////////////////////
/// @brief Display numPixels with one solid color.
/// We only use a 3 byte array, storing one pixel.
/// We then send the same pixel repeatedly to the LED strip very fast.
/// This demonstrates the ability tocall the library repeatedly.
/// If this feature fails, you may see only 1 pixel lit, or a varying number
/// of pixels glitching on and off.
////////////////////////////////////////////////////////////////////////////////
void color1N(uint8_t red, uint8_t green, uint8_t blue)
{
  rgb pix[1];

  pix[0].r = red;
  pix[0].g = green;
  pix[0].b = blue;

  // Disable interupts, save the old interupt state
  const uint8_t oldSREG = SREG;
  cli();

  // Display the LEDs. Each strip must be streamed contiguously: the gap
  // between successive sendPixels() calls on the SAME pin is only a few us,
  // well under the WS2812 latch time. Interleaving the four strips would
  // leave each line idle ~90us between its pixels, latching the strip after
  // the first pixel (symptom: only the first LED lights up).
  for (uint16_t i = 0; i < numPixels; i++) { myLeds1.sendPixels(1, pix); }
  for (uint16_t i = 0; i < numPixels; i++) { myLeds2.sendPixels(1, pix); }
  for (uint16_t i = 0; i < numPixels; i++) { myLeds3.sendPixels(1, pix); }
  for (uint16_t i = 0; i < numPixels; i++) { myLeds4.sendPixels(1, pix); }

  // Restore the old interrupt state
  SREG = oldSREG;
}

void LongPress(void * /*oneButton*/)
{
  if(test_en)
  {
    myLeds1.clear(numPixels);
    myLeds2.clear(numPixels);
    myLeds3.clear(numPixels);
    myLeds4.clear(numPixels);
    digitalWrite(PIN_PA1, LOW);
    //FAB_PORT(B, 0x00); // all pins low
    PORTB.DIR =    0b00000000;
    PORTB.PIN0CTRL = 0;
    PORTB.PIN1CTRL = 0;
    PORTB.PIN2CTRL = 0;
    PORTB.PIN3CTRL = WS_DETECT_ISC; // re-enable WS2812 data-detect interrupt on PB3
    digitalWrite(PIN_PC1, LOW);
  }
  else
  {
    digitalWrite(PIN_PC1, HIGH);
    digitalWrite(PIN_PA1, HIGH);
    FAB_PORT(B, 0x00); // all pins low
    FAB_DDR(B, 0xFF); // all pins out
    PORTB.PIN3CTRL = 0; // disable PB3 interrupt while test mode drives PORTB
    myLeds1.clear(numPixels);
    myLeds2.clear(numPixels);
    myLeds3.clear(numPixels);
    myLeds4.clear(numPixels);
    previousMillis = 0;
  }
  test_en = !test_en;
}

////////////////////////////////////////////////////////////////////////////////
/// @brief This method is automatically called once when the board boots.
////////////////////////////////////////////////////////////////////////////////
void setup()
{
  pinMode(PIN_PC1, OUTPUT);
  pinMode(PIN_PA1, OUTPUT);
  pinMode(PIN_PA7, OUTPUT);     // WS2812 data-present status LED
  digitalWrite(PIN_PA7, LOW);
  //digitalWrite(PIN_PC1, HIGH);

  // button.attachPress(ShortPress, &button);
  button.attachLongPressStart(LongPress, &button);
  button.setDebounceMs(20);
  button.setLongPressIntervalMs(1000);

  //FAB_PORT(B, 0x00); // all pins low
  PORTB.DIR = 0b00000000;
  PORTB.PIN0CTRL = 0;
  PORTB.PIN1CTRL = 0;
  PORTB.PIN2CTRL = 0;
  PORTB.PIN3CTRL = WS_DETECT_ISC; // enable WS2812 data-detect interrupt on PB3
  digitalWrite(PIN_PC1, LOW);
  digitalWrite(PIN_PA1, LOW);
}

void loop()
{
  button.tick();
  unsigned long currentMillis = millis();
  if (currentMillis - previousMillis >= interval)
  {
    previousMillis = currentMillis;
    if(test_en)
    {
      switch(mode) {
        case 0:
          color1N(127,0,0);
          mode = 1;
          break;
        case 1:
          color1N(0,127,0);
          mode = 2;
          break;
        case 2:
          color1N(0,0,127);
          mode = 0;
          break;
      }
    }
  }

  // WS2812 data detection (PB3) -> status LED (PA7).
  // Only valid while test mode is off, since test mode drives PORTB as outputs.
  if (!test_en)
  {
    // Atomically read & clear the activity flag set by the pin-change ISR.
    uint8_t oldSREG = SREG;
    cli();
    bool act = wsActivity;
    wsActivity = false;
    SREG = oldSREG;

    if (act)
    {
      lastDataMillis = currentMillis;
    }
    bool present = (currentMillis - lastDataMillis) < dataTimeoutMs;
    if (present != dataLedOn)
    {
      dataLedOn = present;
      digitalWrite(PIN_PA7, present ? HIGH : LOW);
    }
  }
  else if (dataLedOn)
  {
    // Entered test mode: turn the data-present LED off.
    dataLedOn = false;
    digitalWrite(PIN_PA7, LOW);
  }

  delay(10);
}

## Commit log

2019-08-25 Added PB16 rev D files
    [Output1_8.sch, Output9_16.sch, PB16_Bom.ods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]
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2019-09-20 updated Aux header to 3.81mm spaced header
    [Output1_8.sch, Output9_16.sch, PB16_Bom.ods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]
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2019-10-03 added quad out again
    [Quad_Diff_Out-B_Cu.gbr, Quad_Diff_Out-B_Mask.gbr, Quad_Diff_Out-B_Paste.gbr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]
2019-10-03 changed pin 4 to gnd to match the datasheet
    [Quad_Diff_Out-B_Cu.gbr, Quad_Diff_Out-B_Mask.gbr, Quad_Diff_Out-B_Paste.gbr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]
2019-10-04 Added PB16 E682 and Serial Board
    [PB_16-B_Cu.gbr, PB_16-B_Mask.gbr, PB_16-B_Paste.gbr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]
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2019-10-08 Added LOR/DMX Serial Port Selector, EEPROM, and Push buttons
    [Output1_8.sch, Output9_16.sch, PB16_Bom.ods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]
2019-10-10 fixed switch labels
    [PB_16.kicad_pcb]
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2019-11-05 updating pcb and fixing bom
    [PB_16-B_Cu.gbr, PB_16-B_Mask.gbr, PB_16-B_Paste.gbr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]
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2019-11-09 fixed aux header
    [PB_16.kicad_pcb, PB_16.sch]
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2019-12-04 added mini, four out, and Multi Expansion
    [Four_Out_BOM.ods, Multi_Expansion_BOM.ods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]
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2019-12-05 added port number silk screen and moved LEDs a little
    [PB_16-B_Adhes.gbr, PB_16-B_CrtYd.gbr, PB_16-B_Cu.gbr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]
2019-12-14 fixed BOM, minor tweaks to ground plane and silkscreen
    [Four_Out-B_Adhes.gbr, Four_Out-B_CrtYd.gbr, Four_Out-B_Cu.gbr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]
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2019-12-19 rotated header and alt added screw header
    [Four_Out-B_Adhes.gbr, Four_Out-B_CrtYd.gbr, Four_Out-B_Cu.gbr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]
2019-12-23 rotated header and added screw terminals
    [Differential.sch, Four_Out_BOM.ods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]
2019-12-31 fix BOM
    [Four_Out_BOM.ods]
2019-12-31 fix output 2/3 pinout
    [Quad_Diff_Out-B_Cu.gbr, Quad_Diff_Out-B_Mask.gbr, Quad_Diff_Out-B_Paste.gbr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]
2019-12-31 The Pinouts were all messed up for the Differential outputs, only the first output would work
    [Differential.sch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]
2019-12-31 fix two pins
    [Multi_Expansion-B_Adhes.gbr, Multi_Expansion-B_CrtYd.gbr, Multi_Expansion-B_Cu.gbr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]
2019-12-31 fixed silkscreen
    [Multi_Expansion-B_Adhes.gbr, Multi_Expansion-B_CrtYd.gbr, Multi_Expansion-B_Cu.gbr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]
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2019-12-31 Added BOM and fixed gnd flood
    [Four_Out_BOM.ods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]
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2019-12-31 added Dual Expansion Board
    [PB_16-B_Cu.gbr, PB_16-B_Mask.gbr, PB_16-B_Paste.gbr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]
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2020-01-01 fixed mounting hole location
    [Diff_Expansion-B_Adhes.gbr, Diff_Expansion-B_CrtYd.gbr, Diff_Expansion-B_Cu.gbr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]
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2020-01-03 added serial header that should work with the E682 Serial PCB
    [PB_16-B_Cu.gbr, PB_16-B_Mask.gbr, PB_16-B_Paste.gbr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]
2020-01-03 moved one trace and Updated PCB
    [PB_16-B_Cu.gbr, PB_16-B_Mask.gbr, PB_16-B_Paste.gbr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]
2020-01-09 fixed digikey partnumber
    [Quad_Diff_Out_BOM.ods]
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2020-01-16 Added PB16 Flex PCB
    [PB_16-B_Cu.gbr, PB_16-B_Mask.gbr, PB_16-B_Paste.gbr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]
2020-01-22 fixed BOM
    [BBB_16_Bom.ods]
2020-01-25 fix hole spacing
    [PB_16-B_Cu.gbr, PB_16-B_Mask.gbr, PB_16-B_Paste.gbr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]
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2020-01-29 swapped DMX1 and DMX2 wiring
    [BBB_16-B_Adhes.gbr, BBB_16-B_CrtYd.gbr, BBB_16-B_Cu.gbr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]
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2020-03-21 updated BOM for 120 ohm resistors added instruction to flash EEPROM chip
    [PB16_Bom.ods]
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2020-05-09 Added some pdf schematics increased Pwr Diff Breakout header spacing
    [BBB_16_Bom.ods, Differential.sch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]
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2020-05-10 updated PB16 to rev G, changed power in ports to screw type connector
    [Output1_8.sch, Output9_16.sch, PB16_Bom.ods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]
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2020-07-17 Update README.md
    fix bom link
2020-09-11 fix header silkscreen
    [Four_Out-B_Adhes.gbr, Four_Out-B_CrtYd.gbr, Four_Out-B_Cu.gbr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]
2020-10-06 fixed the schematic, to match the PCB
    [Diff_In.sch, Outputs.sch, Receiver_Out.kicad_pcb]
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2020-12-16 fixed bom link
    [PB_16_Expansion_BOM.ods]
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2021-01-05 Early Design of 12 port Smart Receiver. TODO: BOM, and clean up firmware for STM32L412
    [Outputs.sch, STM32.sch, Serial.sch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]
2021-01-05 fix DMX1 pins backwards
    [PB_16-B_Cu.gbr, PB_16-B_Mask.gbr, PB_16-B_Paste.gbr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]
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2021-02-20 v3 Fix Push Buttons and GPIO
    [BBB_16-B_Adhes.gbr, BBB_16-B_CrtYd.gbr, BBB_16-B_Cu.gbr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]
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2021-08-29 added BBB16 Flex
    [BBB_16.kicad_pcb, BBB_16.sch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]
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2021-08-30 redid header placement and made PCB smaller again
    [PB_16-B_Adhes.gbr, PB_16-B_CrtYd.gbr, PB_16-B_Cu.gbr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]
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2021-09-02 fix DMX port
    [BBB_16.kicad_pcb, Serial.sch]
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2021-09-02 added v2.0 Gerbers, use at your own risk
    [BBB_16-B_Adhes.gbr, BBB_16-B_CrtYd.gbr, BBB_16-B_Cu.gbr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]
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2021-09-15 added BOM and Position file for SMD assembly
    [16_Expansion_BOM.ods, 16_Expansion_SMD_BOM.csv, Output1_8.sch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]
2021-11-04 Fix a few BBB16v2 Silkscreen issues and added EEPROM file
    [BBB_16-B_Adhes.gbr, BBB_16-B_CrtYd.gbr, BBB_16-B_Cu.gbr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]
2021-11-08 Update README.md
    https://forum.kicad.info/t/warning-avoid-all-links-to-kicad-pcb-org-use-kicad-org/31521
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2022-01-08 fix 5v and GND pin issue
    [Diff_Expansion-B_Adhes.gbr, Diff_Expansion-B_CrtYd.gbr, Diff_Expansion-B_Cu.gbr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]
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2022-03-14 fix BOM and Pic
2022-03-14 added missing diode
    [PB_16.sch]
2022-03-22 fixing I2C lines were backwards
    [Diff_In.kicad_sch, Micro.kicad_sch, Outputs.kicad_sch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]
2022-03-26 fix miswired serial receiver
    [Diff_In.kicad_sch, Micro.kicad_sch, Outputs.kicad_sch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]
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2022-04-08 created Adapter to use Pi hats with Expansion Port
    [Input_Adapter-B_Cu.gbr, Input_Adapter-B_Mask.gbr, Input_Adapter-B_Paste.gbr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]
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2022-04-22 fix upside down PI
    [Input_Adapter-B_Cu.gbr, Input_Adapter-B_Mask.gbr, Input_Adapter-B_Paste.gbr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]
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2022-04-30 i think Kicad has a bug
    [Diff_In.kicad_sch, Micro.kicad_sch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]
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2022-05-09 fix bom path
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2022-05-20 Move C1 (#22)
    Move C1 away from B2 header pin, reroute, refill, move silk screens.
    [BBB_16.kicad_pcb]
2022-05-20 fixing some files on the BBB16_SMD
    [BBB_16-B_Adhesive.gbr, BBB_16-B_Courtyard.gbr, BBB_16-B_Fab.gbr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]
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2022-05-27 Switched to SMD resistors, need to fix BOM
    [BOM-PB_16.csv, Output1_8.kicad_sch, Output9_16.kicad_sch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]
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2022-05-30 added "universal" 5V regulator, switched to Kicad 6
    [Output1_8.kicad_sch, Output9_16.kicad_sch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]
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2022-05-30 fix J28 text
    [PB_16-B_Adhesive.gbr, PB_16-B_Courtyard.gbr, PB_16-B_Cu.gbr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]
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2022-06-04 Move Cap footprint out of the way of reg. (#24)
    * Move c1 Down...
    ... modify Aux silk to be Visible with cap on , repair traces, update Ibom, gerbers, cpl ect.
    * Add more Part LCSC part numbers
    [BOM-PB_16.csv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]
2022-06-04 Fix Pixel and Fuse port numbering, added all JLC partnumbers
    [BOM-PB_16.csv, Output1_8.kicad_sch, Output9_16.kicad_sch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]
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2022-06-04 fix U8 JLC partnumber
    [BOM-PB_16.csv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]
2022-06-05 Update R4 100k discontinued part...
    ...Update rj45 to be 8 pin and match existing footprint. Update Bom.ods manually as im not sure how Scooter Exports it.
    [BOM-PB_16.csv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]
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2022-06-05 added resistors to help with noise the input lines causing flickering
    [BOM-PB_16.csv, Output1_8.kicad_sch, Output9_16.kicad_sch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]
2022-06-05 added resistors to help with noise the input lines causing flickering, Updated BOMS
    [16_Expansion_BOM.ods, BOM-PB_16.csv, Output1_8.kicad_sch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]
2022-06-14 Small updates
    Update Wrong switch that would force standard pcb vs Economic variant. Update Rj45 PartNumber.
    [BBB_16-CuBottom.gbr, BBB_16-CuTop.gbr, BBB_16-EdgeCuts.gbr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]
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2022-06-19 Move Footprint for C1 (#29)
    Move Footprint for C1
    as part is actually 12.5mm and would interfere with next-door neighbor.
    [BBB_16_Expansion-CuBottom.gbr, BBB_16_Expansion-CuTop.gbr, BBB_16_Expansion-EdgeCuts.gbr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]
2022-06-19 update j6, push buttons back to TH, Part number for j6 was for a 3.81.. (#30)
    .. grabbed a random 5mm to use. will probably update pads for buttons yet and maybe different input connector
    [BBB_16_Expansion-CuBottom.gbr, BBB_16_Expansion-CuTop.gbr, BBB_16_Expansion-EdgeCuts.gbr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]
2022-06-20 Update Pwr_IN footprint to match pb16v2/bbb16smd 3.81mm (#31)
    [BBB_16_Expansion-CuBottom.gbr, BBB_16_Expansion-CuTop.gbr, BBB_16_Expansion-EdgeCuts.gbr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]
2022-07-06 fix some 3D paths
    [PB_16.kicad_pcb]
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2022-07-06 fixing some of the rescue libraries
    [Output1_8.kicad_sch, Output9_16.kicad_sch, PB_16.kicad_sch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]
2022-07-06 fix DC-DC name
    [PB_16.kicad_pcb]
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2022-07-22 reverting bills change
    [BBB_16-CuBottom.gbr, BBB_16-CuTop.gbr, BBB_16-EdgeCuts.gbr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]
2022-07-22 ~Create some new custom footprints ~Update some JLC PN's ~Updated some 3D model paths
    [BBB_16-B_Adhesive.gbr, BBB_16-B_Courtyard.gbr, BBB_16-B_Cu.gbr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]
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2022-07-22 fixing some SMD placement rotations
    [POS-BBB_16.csv]
2022-07-23 added BOM. CPL files for BBB_16, DF_Exp (#33)
    added BOM. CPL files for BBB_16 and Diff_Expansion
    [BBB_16_BOM.csv, BOM-DF Extn.csv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]
2022-08-06 update gerbers to maybe fix JLC
    [BBB_16-B_Adhesive.gbr, BBB_16-B_Courtyard.gbr, BBB_16-B_Cu.gbr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]
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2022-08-07 ignore erc until I fix the power signal stuff
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2022-08-12 fix overlap from drc
    [PB_16.kicad_pcb]
2022-08-12 fix errors
    [BBB_16.kicad_pcb]
2022-08-12 fix more warnings
    [BBB_16.kicad_pcb]
2022-08-12 drc fixes
    [BBB_16.kicad_pcb]
2022-08-12 warning fixes
    [Receiver_Out.kicad_pcb]
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2022-08-14 Added Universal 5V regulator and updated to V6
    [BOM-PB_16.csv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]
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2022-08-14 fix warnings
    [PB_16.kicad_pcb]
2022-08-14 fix 3D models
    [Receiver_Out.kicad_pcb]
2022-08-14 fix warning
    [PB16_2_PI.kicad_pcb]
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2022-08-15 switch to two SP3485EN for serial, fix some BOMs
    [BBB_16_BOM.ods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]
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2022-08-15 added change log to try to remember my confusing versioning system....
    [BBB_16.kicad_pcb]
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2022-08-24 add missing footprint
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2022-09-02 fix 3D model pah
    [Pi_Zero_Expansion.kicad_pcb]
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2023-01-07 update a few footprints, fix mounting hole location
    [PB_16-CuBottom.gbr, PB_16-CuTop.gbr, PB_16-EdgeCuts.gbr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]
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2023-04-10 fix RJ45 LCSC PN
    [BOM-Receiver_Out.csv, Diff_In.kicad_sch, Outputs.kicad_sch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]
2023-04-10 fix RJ45 PN
    [BOM-Receiver_Out.csv, Diff_In.kicad_sch, Receiver_Out.kicad_pcb]
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2023-09-02 fix names
    [Diff_In.kicad_sch, Wally_Tree.kicad_sch]
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2023-09-27 fix pinout
    [BOM-WingsStation.csv, Diff_In.kicad_sch, Micro.kicad_sch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]
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2023-11-28 fix pin mappings for Pi_Zero_W_16
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2025-02-24 v3 - Add an Attiny1616 Micro controller and Test Button to enable local testing.
    [BOM-Receiver_Out.csv, Diff_In.kicad_sch, Outputs.kicad_sch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]
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2025-06-30 fix delay on test button press, clean up white space
    [Receiver_Out_Test.ino]
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2026-02-09 v2.3 ---- * 2026-02-09 * Switched to TSSOP-20 for U4 & U5. * Switched to 603 Resistors for Pixel Outputs. * Switched Pixel Outputs to Dual 3.5mm/3.81mm Pads. * Switched Expansion Header to 24pin Falc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
    [BOM-PB_16.csv, Output1_8.kicad_sch, Output9_16.kicad_sch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]
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2026-02-20 PB_16_Expansion v5 ---- * 2026-02-20 * Add Different Output * Switched Expansion Header to 24pin Falcon V4 pinout. * Switched to PB16v2 pinout, use PB16v2 EEPROM
    [PB_16-CuBottom.gbr, PB_16-CuTop.gbr, PB_16-EdgeCuts.gbr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]
2026-02-20 drc fix
    [BOM-PB_16.csv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]
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2026-03-06 try to fix
    [BBB_16.kicad_pcb]
2026-03-06 fix some libraries, BBB16 SMD to kicad v9
    [BBB_16.kicad_pcb]
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2026-03-06 fix font
    [Input_Adapter.kicad_pcb]
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2026-03-06 kicad 9 fixes
    [Pi_Zero_24_Diff.kicad_pcb]
2026-03-06 fix PB footprint location
    [PB16_2_PI.kicad_pcb]
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2026-03-06 fix holes
    [PB_16-B_Adhesive.gbr, PB_16-B_Courtyard.gbr, PB_16-B_Cu.gbr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]
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2026-06-12 add data led indicator and fix single pixel issues on "faster" ws2811 chips
    [Receiver_Out_Test.ino]

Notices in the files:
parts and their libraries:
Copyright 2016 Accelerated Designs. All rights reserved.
